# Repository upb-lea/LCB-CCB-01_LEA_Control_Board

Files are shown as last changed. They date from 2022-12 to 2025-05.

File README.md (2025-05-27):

# LEA Control Board

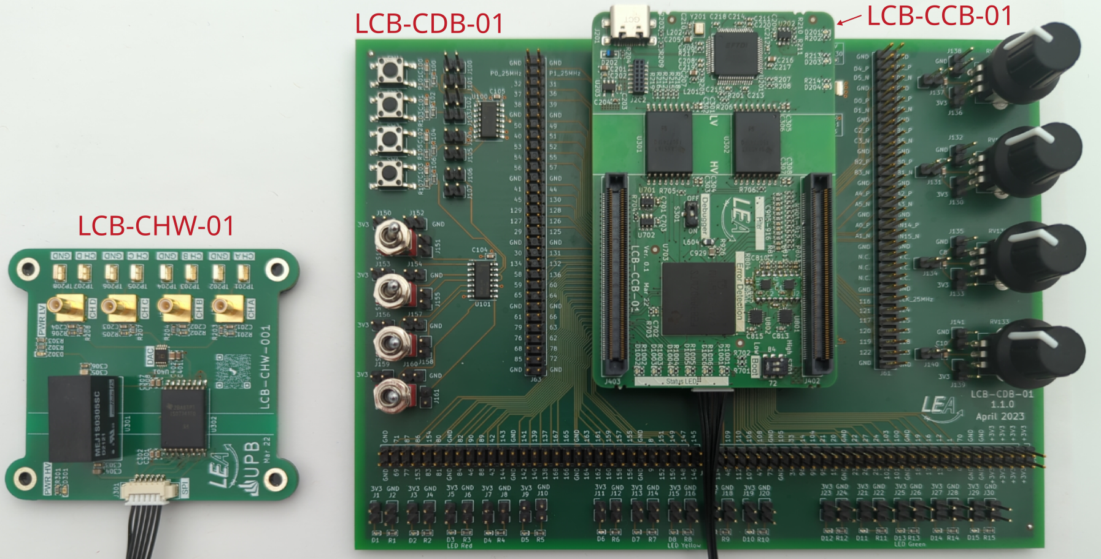
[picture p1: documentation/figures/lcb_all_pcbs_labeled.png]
    

The LEA Control Board (LCB) is a construction kit to provide power electronic converters with a control board.

The basic module is the control board (LCB-CCB) itself. It contains a powerful dual-core processor, error latches and various predefined low-pass filters to respond to input signals. An XDS100v2 debugger is directly integrated on the board. 

The docking board (LCB-CDB) is suitable for initial operation. This contains various input options (switches, buttons, potentiometers) as well as LEDs for output.

The external hardware monitor (LCB-CHW) is for viewing internal counter variables on the oscilloscope and is mainly used for troubleshooting the control board in the overall system (control board + power converter).

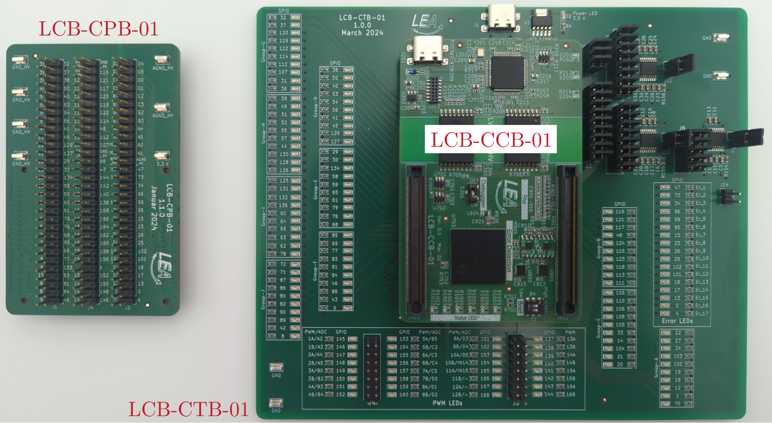
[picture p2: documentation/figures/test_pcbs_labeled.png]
    

The pin board (LCB-CPB) is for in-circuit signal measurments by an external scope on certain pins.
The test board (LCB-CTB) was developed to check all pins, PWM signals, ADCs and DACs for functionality after a new board has been completed (end of line test).

## PCB overview
This is the main repository of the LEA Control Board (LCB) project. Due to correct PCB versioning, every single PCB is in its own repository.
 * [LCB-CDB-01_Dock_Board](https://github.com/upb-lea/LCB-CDB-01_Dock_Board)
 * [LCB-CHW-01_Hardware_Monitor](https://github.com/upb-lea/LCB-CHW-01_Hardware_Monitor)
 * [LCB-CPB-01_Pin_Board](https://github.com/upb-lea/LCB-CPB-01_Pin_Board)
 * [LCB-CTB-01_Test_Board](https://github.com/upb-lea/LCB-CTB-01_Test_Board)
 * [LCB-CBB-01_Bus_Board](https://github.com/upb-lea/LCB-CBB-01_Bus_Board)

Symbols, footprints and 3D-models can be found in the [LEA KiCad Library](https://github.com/upb-lea/LEA_KiCad_Library).

## PCB versioning
Example `LCB-CCB-01-1.0.5`:
 * First three letters `LCB`: Parent project name `LEA Control Board`
 * Second three letters `CCB`: PCB name `Control Board`
 * Number `01`: PCB size. For future use in case of several PCB sizes
 * First version number `1`: Major version, increases for incompatible changes
 * Second number `0`: PCB release, increases for improved layouts
 * Third number `5`: Schematic version, increases for component changes, but no layout changes

## Kicad Options
To open the LEA Control Board files, [KiCad 9](https://www.kicad.org/) needs to be used. Make sure that you run the latest version of KiCad.

### Downloading this project and folder structure
To use this project, LEA KiCad symbols, footprints and 3D-models need to be included. Note, that both folders need to be in the same direction.

Clone the symbols, footprints and 3D-models:
```
git clone https://github.com/upb-lea/LEA_KiCad_Library.git
```

Clone this project:
```
https://github.com/upb-lea/LCB-CCB-01_LEA_Control_Board.git
```
If you are downloading the `.zip`-files manually, unpack them in the same direction.

### Symbol library and footprint libary
The libraries are included by default, if the above mentioned folder structure was considered. Open Kicad, load one of the projects and see the libraries:
 * `symbol editor` -> Search for `LEA_Symbol_Library`
 * `footprint editor` -> Search for `LEA_Footprint_Library`

### Set environment variable for 3D models:
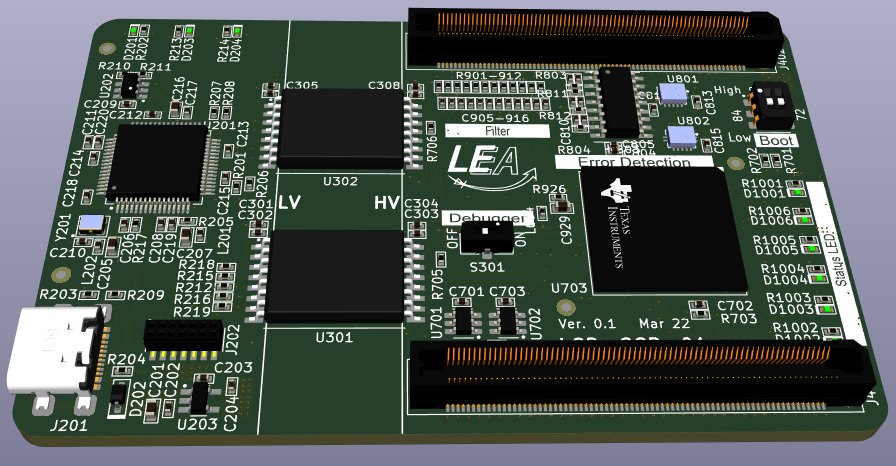
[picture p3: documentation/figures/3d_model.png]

Please refer to [this section](https://github.com/upb-lea/LEA_KiCad_Library#set-environment-variable-for-3d-models).

## Software
Various software examples using the LEA Control Board is available and can be found [in this repository](https://github.com/upb-lea/LCB-Software). There are examples for using the hardware monitor, SPI, UART and many others.

## How to design the LCB into your cirucit?
 * A stable external 3.3 V power supply must be provided, recommended by a linear regulator.
 * It is recommended to use buffer-ICs for the LCB GPIOs to prevent damage on the LCB board.

## Design decisions 
 * To not confuse the user, there is only one supply voltage needed. All pins of the board are save for 3.3 V. Some components can be used with higher voltage, but this would lead to confusion and may damage the board due to misunderstandings.
 * A stable external 3.3 V power supply must be provided, recommended by a linear regulator. We did not decide for an internal regulator, as this regulator does not know your external load, and might be overloaded.

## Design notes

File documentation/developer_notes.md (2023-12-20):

# Developer notes

## create BOM

Create XML-file from kicad schematic
```
kicad-cli sch export python-bom LCB-CPB-01_Pin_Board.kicad_sch 
```

create BOM using kicost
```
pip install kicost
```
Run kicost
`kicost`

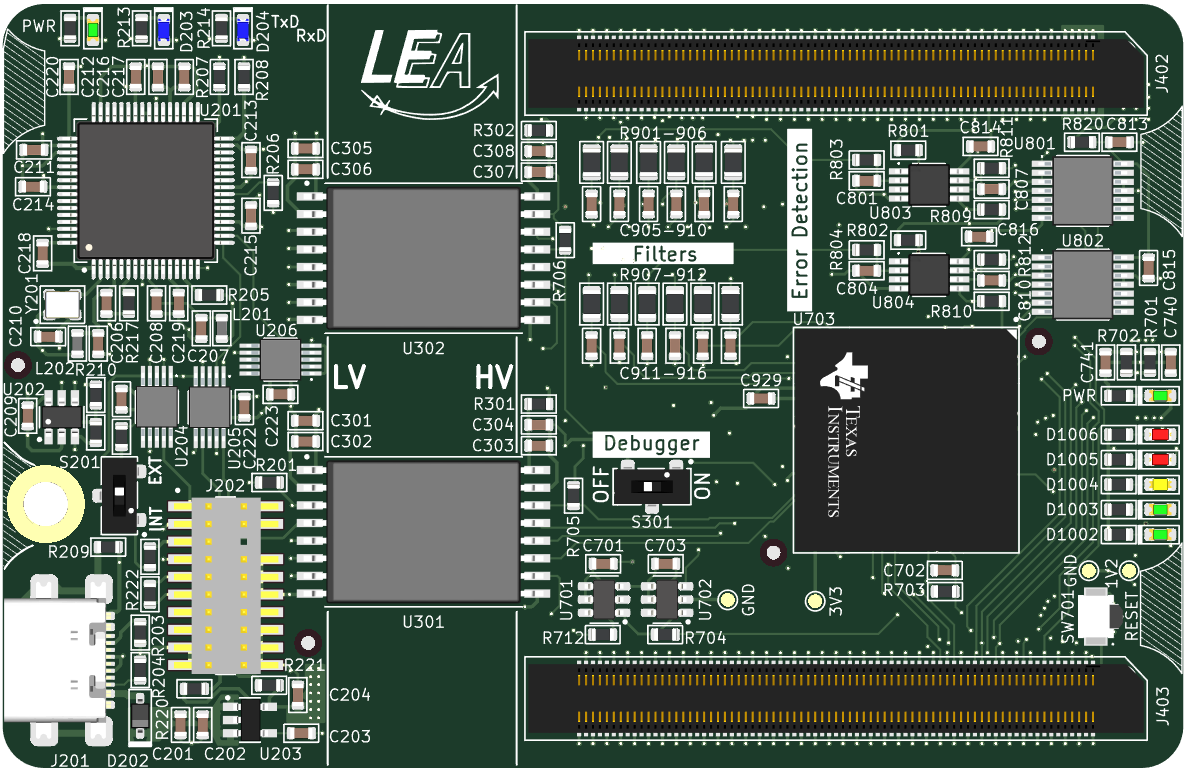
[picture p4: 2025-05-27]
LCB-CCB-01/TopSide.png

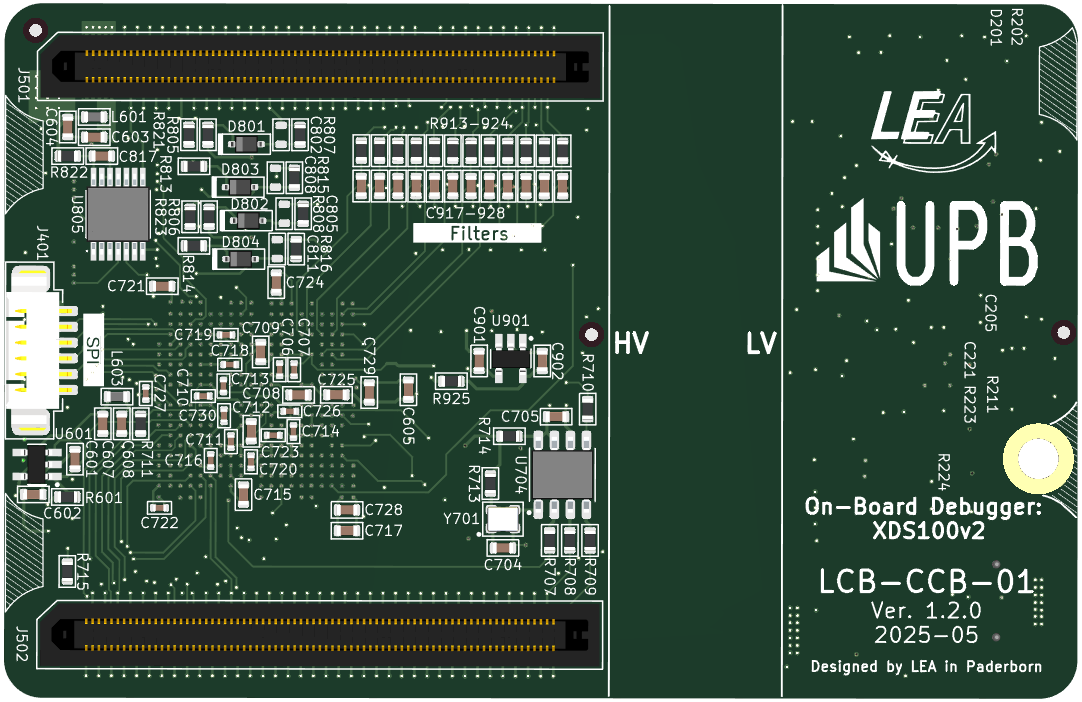
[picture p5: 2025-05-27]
LCB-CCB-01/BottomSide.png

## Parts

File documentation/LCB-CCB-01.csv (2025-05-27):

Source: | /home/nikolasf/Dokumente/01_git/70_PCBs/LCB-CCB-01_LEA_Control_Board/LCB-CCB-01/LCB-CCB-01.kicad_sch
Date: | 2025-05-27T11:14:56+0200
Tool: | Eeschema 9.0.2
Generator: | /usr/share/kicad/plugins/bom_csv_grouped_by_value.py
Component Count: | 248
Collated Components:
Item | Qty | Reference(s) | Value | LibPart | Footprint | Datasheet | DNP | Datasheet | Description | Footprint | Manufacturer | Sim.Enable | manf# | mouser#
1 | 1 | ACCESSORY901 | ACCESSORY_USB_C_cable | LEA_SymbolLibrary:ACCESSORY_USB_C_cable |  | https://www.mouser.de/datasheet/2/813/ACCA-2532_Model__1_-1621233.pdf |  | https://www.mouser.de/datasheet/2/813/ACCA-2532_Model__1_-1621233.pdf |  |  | SparkFun |  | CAB-15424 | 474-CAB-15424
2 | 4 | C201, C205, C207, C216 | 4u7 | LEA_SymbolLibrary:C_0603__4u7_X5R_10P__35V | LEA_FootprintLibrary:C_0603 |  |  |  | Capacitor 0603 | LEA_FootprintLibrary:C_0603 | TDK |  | C1608X5R1V475K | 810-C1608X5R1V475K
3 | 3 | C202, C203, C702 | 10n | LEA_SymbolLibrary:C_0603__10n_X7R_10P__50V | LEA_FootprintLibrary:C_0603 |  |  |  | Capacitor 0603 | LEA_FootprintLibrary:C_0603 | TDK |  | CGA3E2X7R1H103K | 810-CGA3E2X7R1H103K
4 | 5 | C204, C601, C602, C740, C741 | 1u0 | LEA_SymbolLibrary:C_0603__1u0_X5R_10P__50V | LEA_FootprintLibrary:C_0603 |  |  |  | Capacitor 0603 | LEA_FootprintLibrary:C_0603 | TDK |  | C1608X5R1H105K | 810-C1608X5R1H105K
5 | 41 | C206, C208, C209, C210, C211, C212, C213, C214, C215, C217, C218, C219, C220, C221, C222, C223, C302, C303, C306, C307, C701, C703, C704, C705, C708, C709, C712, C715, C717, C721, C724, C725, C728, C729, C813, C814, C815, C816, C817, C901, C902 | 100n | LEA_SymbolLibrary:C_0603_100n_X5R_10P__50V | LEA_FootprintLibrary:C_0603 |  |  |  | Capacitor 0603 | LEA_FootprintLibrary:C_0603 | TDK |  | C1608X5R1H104K | 810-C1608X5R1H104K
6 | 9 | C301, C304, C305, C308, C603, C604, C605, C607, C608 | 2u2 | LEA_SymbolLibrary:C_0603__2u2_X5R_10P__35V | LEA_FootprintLibrary:C_0603 |  |  |  | Capacitor 0603 | LEA_FootprintLibrary:C_0603 | TDK |  | C1608X5R1V225K | 810-C1608X5R1V225K
7 | 15 | C706, C707, C710, C711, C713, C714, C716, C718, C719, C720, C722, C723, C726, C727, C730 | 100n | LEA_SymbolLibrary:C_0402_100n_X7R_10P__50V | LEA_FootprintLibrary:C_0402 |  |  |  | Capacitor 0402 | LEA_FootprintLibrary:C_0402 | TDK |  | C1005X7R1H104K | 810-C1005X7R1H104K
8 | 16 | C801, C804, C807, C810, C905, C906, C909, C910, C913, C914, C917, C918, C921, C922, C925, C926 | 100p | LEA_SymbolLibrary:C_0603_100p_C0G_10P__50V | LEA_FootprintLibrary:C_0603 |  |  |  | Capacitor 0603 | LEA_FootprintLibrary:C_0603 | TDK |  | C1608C0G1H101KAA | 810-C1608C0G1H101KAA
9 | 4 | C802, C805, C808, C811 | 10n | LEA_SymbolLibrary:C_0603__10n_X7R_10P__50V | LEA_FootprintLibrary:C_0603 |  | DNP |  | Capacitor 0603 | LEA_FootprintLibrary:C_0603 | TDK |  | CGA3E2X7R1H103K | 810-CGA3E2X7R1H103K
10 | 12 | C907, C908, C911, C912, C915, C916, C919, C920, C923, C924, C927, C928 | 1n0 | LEA_SymbolLibrary:C_0603__1n0_X7R_10P__50V | LEA_FootprintLibrary:C_0603 |  |  |  | Capacitor 0603 | LEA_FootprintLibrary:C_0603 | TDK |  | C1608X7R1H102KAE | 810-C1608X7R1H102KAE
11 | 1 | C929 | 22u | LEA_SymbolLibrary:C_0603__22u_X5R_10P_6V3 | LEA_FootprintLibrary:C_0603 |  |  |  | Capacitor 0603 | LEA_FootprintLibrary:C_0603 | Samsung |  | CL10A226KQ8NRNE | 187-CL10A226KQ8NRNE
12 | 4 | D201, D1001, D1002, D1003 | 2mA | LEA_SymbolLibrary:LED_0603_G_2mA_APTD1608LCGCK | LEA_FootprintLibrary:LED_0603_G | https://www.mouser.de/datasheet/2/216/APTD1608LCGCK-1102124.pdf |  | https://www.mouser.de/datasheet/2/216/APTD1608LCGCK-1102124.pdf | LED 0603, Green, If 2mA, Vf 1.9V | LEA_FootprintLibrary:LED_0603_G | Kingbright |  | APTD1608LCGCK | 604-APTD1608LCGCK
13 | 1 | D202 | 1A0 | LEA_SymbolLibrary:D_SOD_1A0_BAS3010A03WE6327HTSA1 | LEA_FootprintLibrary:SOD-323_Infineon | https://www.mouser.de/datasheet/2/196/Infineon-BAS3010ASERIES-DS-v01_01-en-1226012.pdf |  | https://www.mouser.de/datasheet/2/196/Infineon-BAS3010ASERIES-DS-v01_01-en-1226012.pdf | Schottky Diodes & Rectifiers Medium Power IF Diode | LEA_FootprintLibrary:SOD-323_Infineon | Infineon |  | BAS3010A03WE6327HTSA1 | 726-BAS3010A-03WE6
14 | 2 | D203, D204 | 2mA | LEA_SymbolLibrary:LED_0603_B_2mA_APHD1608LVBC/D | LEA_FootprintLibrary:LED_0603_B | https://eu.mouser.com/datasheet/2/216/APHD1608LVBC-D-1100823.pdf |  | https://eu.mouser.com/datasheet/2/216/APHD1608LVBC-D-1100823.pdf | LED 0603, Blue, If 2mA, Vf 2.65V | LEA_FootprintLibrary:LED_0603_B | Kingbright |  | APHD1608LVBC/D | 604-APHD1608LVBCD
15 | 4 | D801, D802, D803, D804 | 150mA | LEA_SymbolLibrary:D_SOD_150mA_BAS316_R1_00001 | LEA_FootprintLibrary:SOD-323_Panjit | https://www.mouser.de/datasheet/2/1057/BAS316-1876387.pdf |  | https://www.mouser.de/datasheet/2/1057/BAS316-1876387.pdf | Diodes - General Purpose, Power, Switching SURFACE MOUNT SWITCHING DIODE | LEA_FootprintLibrary:SOD-323_Panjit | Panjit |  | BAS316_R1_00001 | 241-BAS316_R1_00001
16 | 1 | D1004 | 2mA | LEA_SymbolLibrary:LED_0603_Y_2mA_APTD1608LSYCK | LEA_FootprintLibrary:LED_0603_Y | https://eu.mouser.com/datasheet/2/216/APHD1608LSURCK-1100899.pdf |  | https://eu.mouser.com/datasheet/2/216/APHD1608LSURCK-1100899.pdf | LED 0603, Yellow, If 2mA, Vf 1.85V | LEA_FootprintLibrary:LED_0603_Y | Kingbright |  | APTD1608LSYCK | 604-APTD1608LSYCK
17 | 2 | D1005, D1006 | 2mA | LEA_SymbolLibrary:LED_0603_R_2mA_APHD1608LSURCK | LEA_FootprintLibrary:LED_0603_R | https://eu.mouser.com/datasheet/2/216/APHD1608LSURCK-1100899.pdf |  | https://eu.mouser.com/datasheet/2/216/APHD1608LSURCK-1100899.pdf | LED 0603, Red, If 2mA, Vf 1.75V | LEA_FootprintLibrary:LED_0603_R | Kingbright |  | APHD1608LSURCK | 604-APHD1608LSURCK
18 | 1 | J201 | USBC_GTC_USB4110-GF-A | LEA_SymbolLibrary:Conn_USBC_GTC_USB4110-GF-A | LEA_FootprintLibrary:USB_C_GCT_USB4110-GF-A | https://www.mouser.de/datasheet/2/837/USB4110-2888203.pdf |  | https://www.mouser.de/datasheet/2/837/USB4110-2888203.pdf | USB Connectors USB Type C, 2.0, Rec, SMT , G/F, RA , Top Mnt, T & R | LEA_FootprintLibrary:USB_C_GCT_USB4110-GF-A | GTC |  | USB4110-GF-A | 640-USB4110-GF-A
19 | 1 | J202 | FTR-110-03-G-D-06-TR | LEA_SymbolLibrary:Conn_02x10_Male_JTAG | LEA_FootprintLibrary:FTR-110-03-G-D-06 | https://kinetictest.samtec.com/partnumber/ftr-110-03-g-d-06-tr |  | https://kinetictest.samtec.com/partnumber/ftr-110-03-g-d-06-tr | 20 pin SMD Micro Header, 1.27 mm pitch | LEA_FootprintLibrary:FTR-110-03-G-D-06 | Samtec |  | FTR-110-03-G-D-06-TR | 200-FTR11003GD06TR
20 | 1 | J401 | Molex_532617006 | LEA_SymbolLibrary:Conn_Molex_532617006 | LEA_FootprintLibrary:6-PinHeader_Molex_532617006 | https://www.molex.com/pdm_docs/sd/532617006_sd.pdf |  | https://www.molex.com/pdm_docs/sd/532617006_sd.pdf | 6 Pin Male, right angle, 1.25mm Pitch | LEA_FootprintLibrary:6-PinHeader_Molex_532617006 | Molex |  | 53261-7006 | 538-53261-7006
21 | 2 | J402, J403 | ERF5-075-05.0-L-DV-TR | LEA_SymbolLibrary:Conn_ERF5-075-05.0-L-DV-TR | LEA_FootprintLibrary:ERF5-075-05.0-L-DV | https://suddendocs.samtec.com/prints/erf5-xxx-xx.x-dv-xx-tr-footprint.pdf |  | https://suddendocs.samtec.com/prints/erf5-xxx-xx.x-dv-xx-tr-footprint.pdf | Board to Board & Mezzanine Connectors 0.50 mm Edge Rate Rugged High Speed Socket | LEA_FootprintLibrary:ERF5-075-05.0-L-DV | Samtec |  | ERF5-075-05.0-L-DV-TR | 200-ERF507505.0LDVTR
22 | 2 | J501, J502 | ERM5-075-05.0-L-DV-K-TR | LEA_SymbolLibrary:Conn_ERM5-075-05.0-L-DV-K-TR | LEA_FootprintLibrary:ERM5-075-05.0-L-DV | https://suddendocs.samtec.com/prints/erm5-xxx-xx.x-dv-xx-tr-footprint.pdf |  | https://suddendocs.samtec.com/prints/erm5-xxx-xx.x-dv-xx-tr-footprint.pdf | Board to Board & Mezzanine Connectors 0.50 mm Edge Rate Rugged High Speed Terminal | LEA_FootprintLibrary:ERM5-075-05.0-L-DV | Samtec | 0 | ERM5-075-05.0-L-DV-K-TR | 200-ERM5075050LDVKTR
23 | 2 | L201, L202 | Ferrite_0603 | LEA_SymbolLibrary:Ferrite_0603_600R_300mA | LEA_FootprintLibrary:L_0603 | https://www.mouser.de/datasheet/2/643/ds_ST_FCB_0603_series-3420259.pdf |  | https://www.mouser.de/datasheet/2/643/ds_ST_FCB_0603_series-3420259.pdf | Ferrite Bead, 0603, 600Ohm, 300mA | LEA_FootprintLibrary:L_0603 | Murata |  | FCB-0603-601A | 530-FCB-0603-601A
24 | 2 | L601, L603 | 60R/3A5 | LEA_SymbolLibrary:Ferrite_0603_60R_3A5 | LEA_FootprintLibrary:L_0603 | https://product.tdk.com/system/files/dam/doc/product/emc/emc/beads/catalog/beads_commercial_power_mpz1608_en.pdf |  | https://product.tdk.com/system/files/dam/doc/product/emc/emc/beads/catalog/beads_commercial_power_mpz1608_en.pdf | Ferrite Bead, 0603 | LEA_FootprintLibrary:L_0603 | TDK |  | MPZ1608S600ATAH0 | 810-MPZ1608S600ATAH0
25 | 11 | R201, R205, R207, R208, R211, R223, R701, R702, R703, R705, R706 | 2k2 | LEA_SymbolLibrary:R_0603__2k2_THICK__1P__75V | LEA_FootprintLibrary:R_0603 |  |  |  | Resistor 0603 | LEA_FootprintLibrary:R_0603 | Vishay |  | CRCW06032K20FKEAC | 71-CRCW06032K20FKEAC
26 | 9 | R202, R213, R214, R1001, R1002, R1003, R1004, R1005, R1006 | 680R | LEA_SymbolLibrary:R_0603_680R_THICK__1P__75V | LEA_FootprintLibrary:R_0603 |  |  |  | Resistor 0603 | LEA_FootprintLibrary:R_0603 | Vishay |  | CRCW0603680RFKEAC | 71-CRCW0603680RFKEAC
27 | 9 | R203, R204, R220, R221, R224, R805, R806, R813, R814 | 4k7 | LEA_SymbolLibrary:R_0603__4k7_THICK__1P__75V | LEA_FootprintLibrary:R_0603 |  |  |  | Resistor 0603 | LEA_FootprintLibrary:R_0603 | Vishay |  | CRCW06034K70FKEBC | 71-CRCW06034K70FKEBC
28 | 15 | R206, R209, R222, R301, R302, R601, R704, R712, R713, R714, R820, R821, R822, R823, R925 | 0R0 | LEA_SymbolLibrary:R_0603__0R0_THICK__1P__75V | LEA_FootprintLibrary:R_0603 |  |  |  | Resistor 0603 | LEA_FootprintLibrary:R_0603 | Vishay |  | CRCW06030000Z0EAC | 71-CRCW06030000Z0EAC
29 | 5 | R210, R807, R808, R815, R816 | 10k | LEA_SymbolLibrary:R_0603__10k_THICK__1P__75V | LEA_FootprintLibrary:R_0603 |  |  |  | Resistor 0603 | LEA_FootprintLibrary:R_0603 | Vishay |  | CRCW060310K0FKEAC | 71-CRCW060310K0FKEAC
30 | 1 | R217 | 12k | LEA_SymbolLibrary:R_0603__12k_THICK__1P__75V | LEA_FootprintLibrary:R_0603 |  |  |  | Resistor 0603 | LEA_FootprintLibrary:R_0603 | Vishay |  | CRCW060312K0FKEAC | 71-CRCW060312K0FKEAC
31 | 4 | R707, R708, R709, R710 | 33R | LEA_SymbolLibrary:R_0603__33R_THICK__1P__75V | LEA_FootprintLibrary:R_0603 |  |  |  | Resistor 0603 | LEA_FootprintLibrary:R_0603 | Vishay |  | CRCW060333R0FKEAC | 71-CRCW060333R0FKEAC
32 | 1 | R711 | 56R | LEA_SymbolLibrary:R_0603__56R_THICK__1P__75V | LEA_FootprintLibrary:R_0603 |  |  |  | Resistor 0603 | LEA_FootprintLibrary:R_0603 | Vishay |  | CRCW060356R0FKEAC | 71-CRCW060356R0FKEAC
33 | 1 | R715 | 10R | LEA_SymbolLibrary:R_0603__10R_THICK__1P__75V | LEA_FootprintLibrary:R_0603 |  |  |  | Resistor 0603 | LEA_FootprintLibrary:R_0603 | Vishay |  | CRCW060310R0FKEAC | 71-CRCW060310R0FKEAC
34 | 20 | R801, R802, R803, R804, R809, R810, R811, R812, R913, R914, R915, R916, R917, R918, R919, R920, R921, R922, R923, R924 | 1k0 | LEA_SymbolLibrary:R_0603__1k0_THICK__1P__75V | LEA_FootprintLibrary:R_0603 |  |  |  | Resistor 0603 | LEA_FootprintLibrary:R_0603 | Vishay |  | CRCW06031K00FKEAC | 71-CRCW06031K00FKEAC
35 | 12 | R901, R902, R903, R904, R905, R906, R907, R908, R909, R910, R911, R912 | 1k0 | LEA_SymbolLibrary:R_0805__1k0_THICK__1P_150V | LEA_FootprintLibrary:R_0805 |  |  |  | Resistor 0805 | LEA_FootprintLibrary:R_0805 | Vishay |  | CRCW08051K00FKEAC | 71-CRCW08051K00FKEAC
36 | 2 | S201, S301 | CAS-120TA | LEA_SymbolLibrary:CAS-120TA | LEA_FootprintLibrary:CAS-120TA | https://www.mouser.de/datasheet/2/972/cas-1628136.pdf |  | https://www.mouser.de/datasheet/2/972/cas-1628136.pdf | Slide Switches SPDT, ON-ON, slide, J-hook SMD terminals, 100mA @ 6V DC | LEA_FootprintLibrary:CAS-120TA | Nidec |  | CAS-120TA | 229-CAS-120TA
37 | 1 | SW701 | SW_Push_RightAngle | LEA_SymbolLibrary:SW_Push_RightAngle | LEA_FootprintLibrary:Sw_Push_RightAngle | https://www.mouser.de/datasheet/2/307/en_b3u-3476507.pdf |  | https://www.mouser.de/datasheet/2/307/en_b3u-3476507.pdf | Push button switch, right angle, generic, two pins | LEA_FootprintLibrary:Sw_Push_RightAngle | Omron Electronics |  | B3U-3000PM | 653-B3U-3000PM
38 | 1 | U201 | FT2232HL | LEA_SymbolLibrary:FT2232HL | LEA_FootprintLibrary:LQFP-64_12x12_Pitch0.5mm_FTDI | https://ftdichip.com/wp-content/uploads/2020/07/DS_FT2232H.pdf |  | https://ftdichip.com/wp-content/uploads/2020/07/DS_FT2232H.pdf | USB Interface IC USB HS to Dual UART/ FIFO/SPI/JTAG/I2C | LEA_FootprintLibrary:LQFP-64_12x12_Pitch0.5mm_FTDI | FTDI |  | FT2232HL-TRAY | 895-FT2232HL-TRAY
39 | 1 | U202 | 93LC56BT-I_OT | LEA_SymbolLibrary:EEPROM_93LC56BT-I_OT | LEA_FootprintLibrary:SOT-23-6_Microchip | http://ww1.microchip.com/downloads/en/devicedoc/21794f.pdf |  | http://ww1.microchip.com/downloads/en/devicedoc/21794f.pdf | EEPROM Serial-Microwire 2K-Bit 128 x 16 2MHz,93LC56BT-I/OT,SOT-23-6,SMD | LEA_FootprintLibrary:SOT-23-6_Microchip | Microchip |  | 93LC56BT-I/OT | 579-93LC56BT-I/OT
40 | 1 | U203 | MIC5259-3.3YD5-TR | LEA_SymbolLibrary:MIC5259-3.3YD5-TR | LEA_FootprintLibrary:SOT-23-5_Microchip | https://ww1.microchip.com/downloads/en/DeviceDoc/mic5259.pdf |  | https://ww1.microchip.com/downloads/en/DeviceDoc/mic5259.pdf | LDO Voltage Regulator 3.3V 300mA | LEA_FootprintLibrary:SOT-23-5_Microchip | Microchip | 0 | MIC5259-3.3YD5-TR | 998-MIC5259-3.3YD5TR
41 | 3 | U204, U205, U206 | ADG736BRMZ | LEA_SymbolLibrary:ADG736BRMZ | LEA_FootprintLibrary:MSOP10_AnalogDevices | http://www.analog.com/media/en/technical-documentation/data-sheets/ADG736.pdf |  | http://www.analog.com/media/en/technical-documentation/data-sheets/ADG736.pdf | Analog Devices ADG736BRMZ, Analogue SPDT Switch Dual SPDT, 3 V, 5 V, 10-Pin MSOP | LEA_FootprintLibrary:MSOP10_AnalogDevices | Analog Devices |  | ADG736BRMZ | 584-ADG736BRMZ
42 | 2 | U301, U302 | ISO_ISO7741FQDWWQ1 | LEA_SymbolLibrary:ISO_ISO7741FQDWWQ1 | LEA_FootprintLibrary:SOIC-16_TI_DWW0016A_Optimized | https://www.ti.com/lit/ds/symlink/iso7741-q1.pdf?ts=1637972753620 |  | https://www.ti.com/lit/ds/symlink/iso7741-q1.pdf?ts=1637972753620 | ISO774x-Q1 Automotive, High-Speed, Reinforced Quad-Channel Digital Isolators | LEA_FootprintLibrary:SOIC-16_TI_DWW0016A_Optimized | Texas Instruments |  | ISO7741FQDWWQ1 | 595-ISO7741FQDWWQ1
43 | 1 | U601 | MIC5504-1.2YM5-TR | LEA_SymbolLibrary:MIC5504-1.2YM5-TR | LEA_FootprintLibrary:SOT-23-5_Microchip | https://www.mouser.de/datasheet/2/268/MIC5501_02_03_04_300mA_Single_Output_LDO_in_Small_-3442643.pdf |  | https://www.mouser.de/datasheet/2/268/MIC5501_02_03_04_300mA_Single_Output_LDO_in_Small_-3442643.pdf | LDO Voltage Regulator 1.2V 300mA | LEA_FootprintLibrary:SOT-23-5_Microchip | Microchip |  | MIC5504-1.2YM5-TR | 998-MIC5504-1.2YM5TR
44 | 1 | U701 | TPS3702CX33DDCT | LEA_SymbolLibrary:TPS3702CX33DDCT | LEA_FootprintLibrary:TSOT-23-6_TI | https://www.ti.com/lit/ds/symlink/tps3702.pdf?HQS=dis-mous-null-mousermode-dsf-pf-null-wwe&ts=1642032019663 |  | https://www.ti.com/lit/ds/symlink/tps3702.pdf?HQS=dis-mous-null-mousermode-dsf-pf-null-wwe&ts=1642032019663 | Supervisory Circuits High-Acc, Fixed Threshold OV/UV Mntr | LEA_FootprintLibrary:TSOT-23-6_TI | Texas Instruments |  | TPS3702CX33DDCT | 595-TPS3702CX33DDCT
45 | 1 | U702 | TPS3702CX12DDCT | LEA_SymbolLibrary:TPS3702CX12DDCT | LEA_FootprintLibrary:TSOT-23-6_TI | https://www.ti.com/lit/ds/symlink/tps3702.pdf?HQS=dis-mous-null-mousermode-dsf-pf-null-wwe&ts=1642032019663 |  | https://www.ti.com/lit/ds/symlink/tps3702.pdf?HQS=dis-mous-null-mousermode-dsf-pf-null-wwe&ts=1642032019663 | Supervisory Circuits High-Acc, Fixed Threshold OV/UV Mntr | LEA_FootprintLibrary:TSOT-23-6_TI | Texas Instruments |  | TPS3702CX12DDCT | 595-TPS3702CX12DDCT
46 | 1 | U703 | TMS320F28388D | LEA_SymbolLibrary:TMS320F2838xDZWT | LEA_FootprintLibrary:BGA-361_19x19_16.0x16.0mm | https://www.ti.com/lit/ds/symlink/tms320f28388d.pdf?ts=1737445638002 |  | https://www.ti.com/lit/ds/symlink/tms320f28388d.pdf?ts=1737445638002 | MCU C2000 32-bit, Dual-core C28x architecture | LEA_FootprintLibrary:BGA-361_19x19_16.0x16.0mm | Texas Instruments |  | F28388DZWTSR | 595-F28388DZWTSR
47 | 1 | U704 | PI6C49CB04AQ3WEX | LEA_SymbolLibrary:PI6C49CB04AQ3WEX | LEA_FootprintLibrary:SOIC-8 | https://www.mouser.de/datasheet/2/115/DIOD_S_A0009189232_1-2543411.pdf |  | https://www.mouser.de/datasheet/2/115/DIOD_S_A0009189232_1-2543411.pdf | Clock Buffer LOW SKEW 1 TO 4 CLOCK BUFFER | LEA_FootprintLibrary:SOIC-8 | Diodes Incorporated |  | PI6C49CB04AQ3WEX | 621-PI6C49CB04AQ3WEX
48 | 2 | U801, U802 | 74HC74PW | LEA_SymbolLibrary:74HC74PW | LEA_FootprintLibrary:TSSOP-14-Nexperia | https://assets.nexperia.com/documents/data-sheet/74HC_HCT74.pdf |  | https://assets.nexperia.com/documents/data-sheet/74HC_HCT74.pdf | Flip-Flops 74HC74PW/SOT402/TSSOP14 | LEA_FootprintLibrary:TSSOP-14-Nexperia | Nexperia |  | 74HC74PW,118 | 771-74HC74PW-T
49 | 2 | U803, U804 | TLV3202AIDGKR | LEA_SymbolLibrary:OP_2_TLV3202AIDGKR_VSSOP-8 | LEA_FootprintLibrary:VSSOP-8-TI | https://www.ti.com/lit/ds/symlink/tlv3202.pdf?ts=1737103769904 |  | https://www.ti.com/lit/ds/symlink/tlv3202.pdf?ts=1737103769904 |  | LEA_FootprintLibrary:VSSOP-8-TI | Texas Instruments |  | TLV3202AIDGKR | 595-TLV3202AIDGKR
50 | 1 | U805 | 74ALVC08PW | LEA_SymbolLibrary:AND_Gate_74ALVC08PW | LEA_FootprintLibrary:TSSOP-14-Nexperia | https://assets.nexperia.com/documents/data-sheet/74ALVC08.pdf |  | https://assets.nexperia.com/documents/data-sheet/74ALVC08.pdf | 4 gate, 8 input, 4 Output, AND gate, Logic Gates 74ALVC08PW/TSSOP14 | LEA_FootprintLibrary:TSSOP-14-Nexperia | Nexperia |  | 74ALVC08PW,118 | 771-ALVC08PW118
51 | 1 | U901 | MAX6037AAUK30+T | LEA_SymbolLibrary:MAX6037AAUK30+T | LEA_FootprintLibrary:SOT-23-5_Microchip | https://datasheets.maximintegrated.com/en/ds/MAX6037-MAX6037C.pdf |  | https://datasheets.maximintegrated.com/en/ds/MAX6037-MAX6037C.pdf | Precision Voltage Reference 3.0V | LEA_FootprintLibrary:SOT-23-5_Microchip | Maxim Integrated |  | MAX6037AAUK30+T | 700-MAX6037AAUK30T
52 | 1 | Y201 | ECS-2033-120-AU | LEA_SymbolLibrary:ECS-2033-120-AU | LEA_FootprintLibrary:Osc_ECS_2.5x2 | https://www.mouser.de/datasheet/2/122/ecs_2025_2033-18511.pdf |  | https://www.mouser.de/datasheet/2/122/ecs_2025_2033-18511.pdf | Standard Clock Oscillators 12.000 MHZ 3.3Volt 100 ppm -55C +125C | LEA_FootprintLibrary:Osc_ECS_2.5x2 | ECS |  | ECS-2033-120-AU | 520-2033-120-AU
53 | 1 | Y701 | ECS-2520S33-250-FN-TR | LEA_SymbolLibrary:ECS-2520S33-250-FN-TR | LEA_FootprintLibrary:Osc_ECS_2.5x2 | https://www.mouser.de/datasheet/2/122/ECS_2520S-1064133.pdf |  | https://www.mouser.de/datasheet/2/122/ECS_2520S-1064133.pdf | Standard Clock Oscillators 25MHz 3.3V 10ppm -40C +85C | LEA_FootprintLibrary:Osc_ECS_2.5x2 | ECS |  | ECS-2520S33-250-FN-TR | 520-2520S33-250-FNT

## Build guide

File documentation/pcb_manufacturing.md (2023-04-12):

# Manufacturing and soldering the LCB
## Manufacturing the LCB
 * Minimum PCB thickness is 2.3 mm due to the position-pin overlapping of J501/402 and J502/J403.
 * For automated placement, the position pin holes of the connectors J501/402/J502/J403 should be milled with a depth of minimum 1.3 mm. 
 
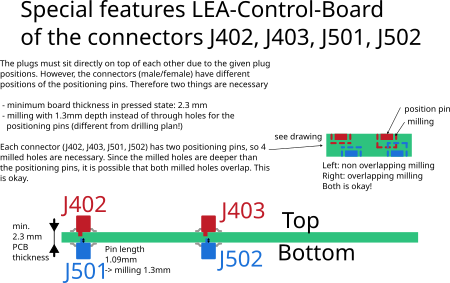
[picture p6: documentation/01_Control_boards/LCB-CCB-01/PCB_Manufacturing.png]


## MCU BGA soldering process
 * Remove all solder from MCU pad (smooth and flat surface).
 * Clean with PCB cleaner and remove all dust residues.
 * Apply a very thin layer of Flux on MCU pad.
 * Use the Rework station for the soldering the MCU chip.
 
## Initial flashing the XDS100 debugger
Please refer to [this tutorial](https://github.com/upb-lea/LCB-Software#flash-xds100-firmware-to-ftdi-chip).

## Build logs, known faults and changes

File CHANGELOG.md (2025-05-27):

# Changelog
All notable changes to this project will be documented in this file.

The format is based on [Keep a Changelog](https://keepachangelog.com/en/1.0.0/),
and this project adheres to [Semantic Versioning](https://semver.org/spec/v2.0.0.html).

## [1.2.0] - 2025-05-27
### Changed
 * USB connector and some components close to the keep-out-areas have moved a bit
 * Rotated 3D-model of processor

## [1.1.0] - 2025-02-21
### Changed
 * Update component names to more readable format
 * Update many 0402 components to 0603 components
 * Updated, more stable external debugger connector
 * Updated housings for error latch, easier to solder

### Added
 * Markings for the holders in the rework-station
 * Hole on debugger side to add custom plastic spacer to prevent board detaching from main pcb by mistake
 * Test points for 3.3 V, 1.2 V and GND
 * Reset button
 * 0 Ohm resistors for some electronics groups
 * Low active AND gate output to summarize the error latch signals

### Fixed
 * Fixed ADA01 workaround due to wrong comparator
 * ADC filters fixed from series connection to parallel connection
 * BOM for microcontroller
 
### Removed
 * Boot switch
 * Impedance buffer U902. Also works without this buffer IC.
 * R926 (not needed).

## [1.0.0] - 2023-04-09
### Added
 * LCB-CCB-01 Control Board initial release

[1.1.0]: https://github.com/upb-lea/LCB-CCB-01_LEA_Control_Board/compare/1.0.0...1.1.0
[1.0.0]: https://github.com/upb-lea/LCB-CCB-01_LEA_Control_Board/compare/1.0.0...1.0.0

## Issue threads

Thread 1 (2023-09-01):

The base module (LCB-CCB) accidentally detaches from the docking board (LCB-CDB)

meisernitz, 2023-09-01:
The base module (LCB-CCB) sometimes detaches from the docking board (LCB-CDB) unintentionally
For example when touching the usb cables.

A possible solution would be to add two plastic spacers near the iso couplers.
There are no components at this point.

VijayThera, 2025-01-06:
added M3 hole for a spacer

Closed 2025-01-06.

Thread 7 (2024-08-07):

ADC filters should not be in series

gituser789, 2024-08-07:
# Description of failure
Filtering for ADC and error comparator are in series. This leads to unwanted linking in filter time constants and also in filter functionality, because the first filter resistor limits the current for the second filter. This results in an unwanted input signal for the input comparator.

# Workaround
The workaround is to bring the filter values to uncritical values (r1=100, c1=1n, r2=2k2, c2=1n).

# Real fix
The final solution is a schematic change in placing the filters in parallel, not in series.

- [ ] Replace filter values for the comparator inputs
- [ ] update schematic to the new values

VijayThera, 2024-12-19:
Updated schematics with parallel connection

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

Closed 2024-12-19.

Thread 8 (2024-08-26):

Check if more 0603 components can be used instead of 0402

gituser789, 2024-08-26:
Especially for the components that are made for later adaption like the RC filters.
So it will be more easy to change these components (by soldering).

VijayThera, 2025-01-06:
changed all analog RC filters from 0402 to 0603

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

Closed 2025-01-10.

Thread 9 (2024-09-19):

increase board width for 1 mm

gituser789, 2024-09-19:
For processing in the vapour phase (hanging on the mounting rack to solder double sided PCBs)

gituser789, 2024-12-13:
* [ ] No board size increas
 * [ ] Defined space to hold the board during rework
 * [ ] Defined space should be marked

VijayThera, 2025-01-06:
No change to the board size
Defined space to hold the board during rework, marked the spaces on top layer silklayer

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

gituser789, 2025-01-06:
Please shade the area

Closed 2025-01-06.

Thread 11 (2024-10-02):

U902 Input Voltage range

gituser789, 2024-10-02:
Common mode input voltage range is not enough.

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

gituser789, 2024-12-13:
* [ ] check needed current from analog part of the controller
* [ ] check provided current from LDO
* [ ] Remove the buffer

VijayThera, 2024-12-19:
**Removed buffer U902**
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

needed current for analog part of the controller - Max. 20 mA
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

provided current from LDO - Typ. ~ 30 mA
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

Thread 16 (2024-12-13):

Possibility to find broken parts on the LCB

gituser789, 2024-12-13:
- [x] e.g. adding `0 Ohm` resisistors for different sub-circuits
 - [ ] or working with two 3V3 supplies

VijayThera, 2024-12-29:
added 0R for different sub-circuits

Closed 2024-12-29.

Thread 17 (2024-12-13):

Think about removing the hardware error latch

gituser789, 2024-12-13:
Too custom. Users may use their own latch on their power electronics PCB

VijayThera, 2025-01-10:
After considering Mr. Schafmeister's comments/ideas, it is decided to keep the hardware error detection circuit for this version 1.1.0

Closed 2025-01-10.

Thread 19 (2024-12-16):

Use same filter time constants for all analog filters

gituser789, 2024-12-16:
different time constants are more confusing for the user.
Time constants should be same by default.
The user needs to configure them anyway.

VijayThera, 2024-12-19:
fixed all time constants to 100ns

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

gituser789, 2025-01-13:
Bring back the different time constants
 * Highlight with different colors (maybe background colors?) the different time constants

VijayThera, 2025-01-20:
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

Closed 2025-01-20.

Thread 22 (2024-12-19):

Holes for adding plastic spacers in the combo-area of holder for rework-station (on debugger side only)

gituser789, 2024-12-19:

VijayThera, 2025-01-06:
added M3 hole for spacer

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

Closed 2025-01-06.

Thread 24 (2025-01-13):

Housing sizes for error latch

gituser789, 2025-01-13:
The error latch is made of two compnents: `Comparator` and `Flip-Flop`.
The comparator is the device where soldering with cables is often necessary.
Make this device bigger (keep existing library symbol and make a new one for the bigger device)

The copmarator can be smaller, as soldering with cables is not necessary/planned here.
Make this device smaller (keep existing library symbol and make a new one for the smaller device)

VijayThera, 2025-01-20:
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

Closed 2025-01-23.

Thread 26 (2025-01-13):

Move filter input capacitor to input voltage devider

gituser789, 2025-01-13:
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

gituser789, 2025-01-13:
Function description:
`C809` is for faster switching of the comparator.
 * The reference voltage is in steady state always the same and stable
 * during switching event, additional current flows trough `R809` and the reference changes just for the switching event
 * this leads to a bigger difference between `+` and `-` input pins
 * together with the amplification of the opamp, the switching event speeds up, as the +/- difference is bigger

An additional parallel capacitor to `R815` would lead to stabilization of the reference voltage and would work against the described functionality.

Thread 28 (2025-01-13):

XDS connector update and pre-test necessary

gituser789, 2025-01-13:
The pin header for external debugger connection should be more robust and proof against twist (wrong connector direction).
 * look on the internet for XDS500 and XDS1000 debugger, and check common connectors
 * See if the are twist-proof and may add the connector

Next, a pre-investigation is necessary:
 * small lab setup, and see if external debugger can be used in general. Also check, if external debugger is more robust than internal one. There must be an XDS200 somewhere in the lab.
 * See if any disconnection of on-board XDS100 debugger is necessary if external one is used
 * if yes, add a switch on the PCB what can disconnect the on-board debugger easily

Closed 2025-02-19.

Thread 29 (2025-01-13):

Controller update

gituser789, 2025-01-13:
Update the material number and the symbol name of the actual core controller to the dual core controller.
* overwriter old material number, use same symbol.
* In description, replace the `x` with `8`
* New mouser number: `595-F28388DZWTSR` (very important is the `R` in the end for `tape and reel`).

VijayThera, 2025-01-23:
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

Closed 2025-01-23.

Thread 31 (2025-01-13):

Reset button

gituser789, 2025-01-13:
* `R715` should be `10 Ohm`, which acts as a low pass filter with the given `C` to debounce the switch
* Add `Reset` on the silkscreen next to the switch

Closed 2025-01-17.

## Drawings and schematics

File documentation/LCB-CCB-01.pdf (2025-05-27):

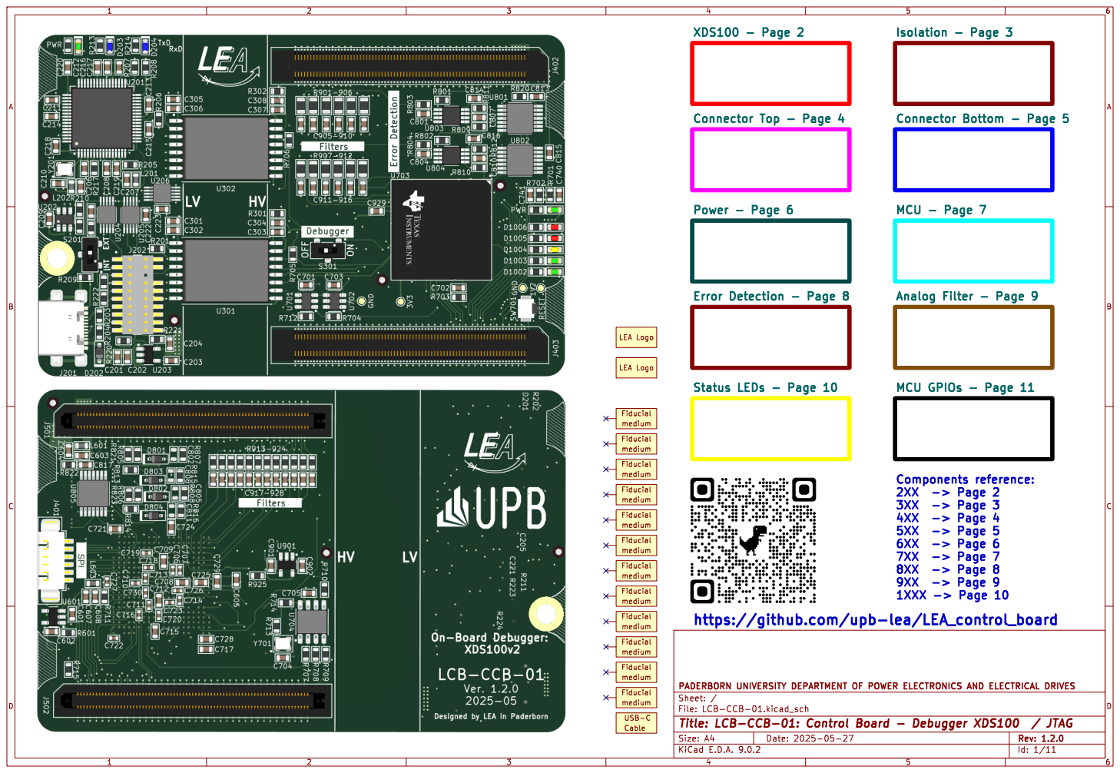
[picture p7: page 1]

LEA Logo Fiducial medium

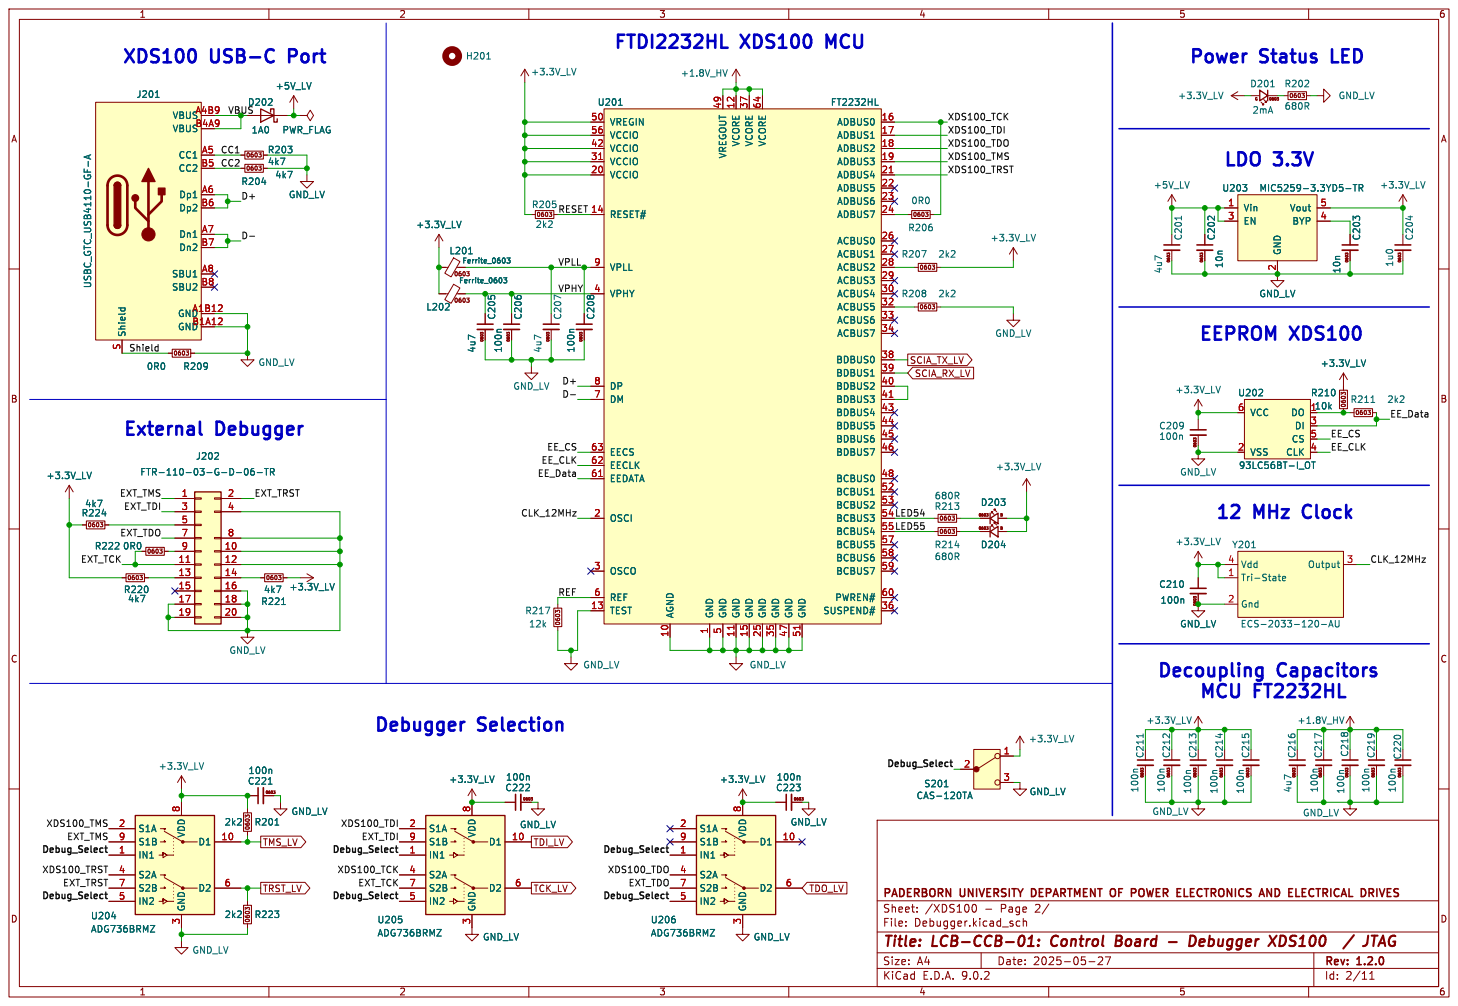
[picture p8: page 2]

5 VCORE 12 GND 11 VCORE 37 GND 15 VCORE 64 GND 25 GND 35 GND 47 GND 51 ADBUS0 16 ADBUS1 17 ADBUS2 18 ADBUS3 19 ADBUS4 21 ADBUS5 22 ADBUS6 23 ADBUS7 24 ACBUS0 26 ACBUS1 27 ACBUS2 28 ACBUS3 29 ACBUS4 30 ACBUS5 32 ACBUS6 33 ACBUS7 34 BDBUS0 38 BDBUS1 39 BDBUS2 40 BDBUS3 41 BDBUS4 43 BDBUS5 44 BDBUS6 45 BDBUS7 46 BCBUS0 48 BCBUS1 52 BCBUS2 53 BCBUS3 54 BCBUS4 55 BCBUS5 57 BCBUS6 58 BCBUS7 59 PWREN# 60 SUSPEND# 36 C208 100n C206 100n C205 4u7

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

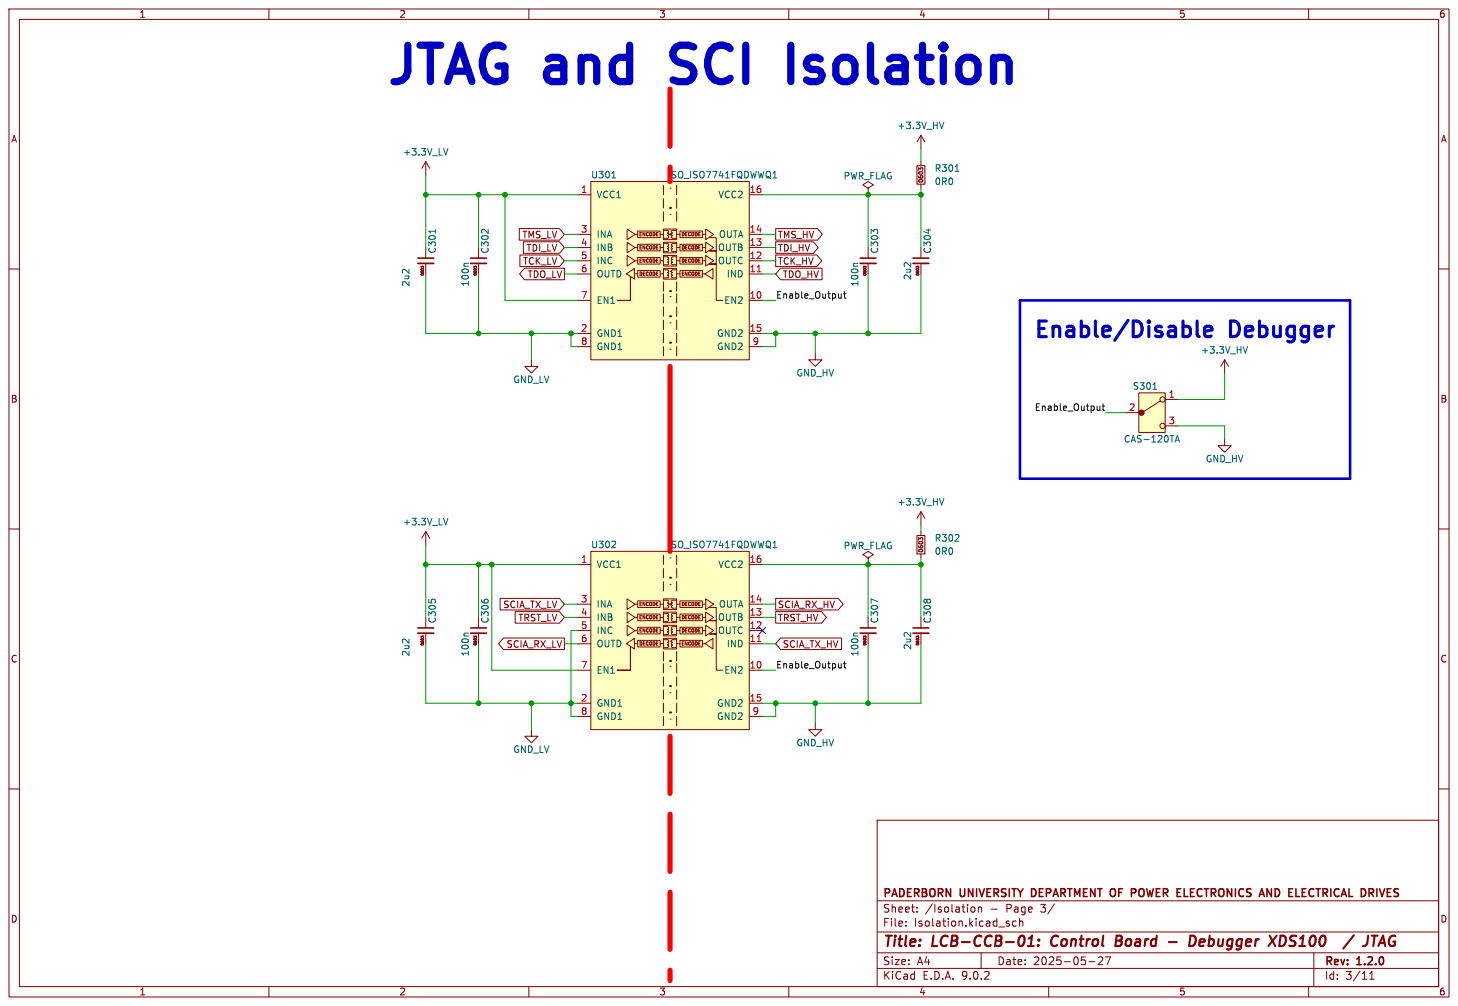
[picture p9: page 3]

JTAG and SCI Isolation

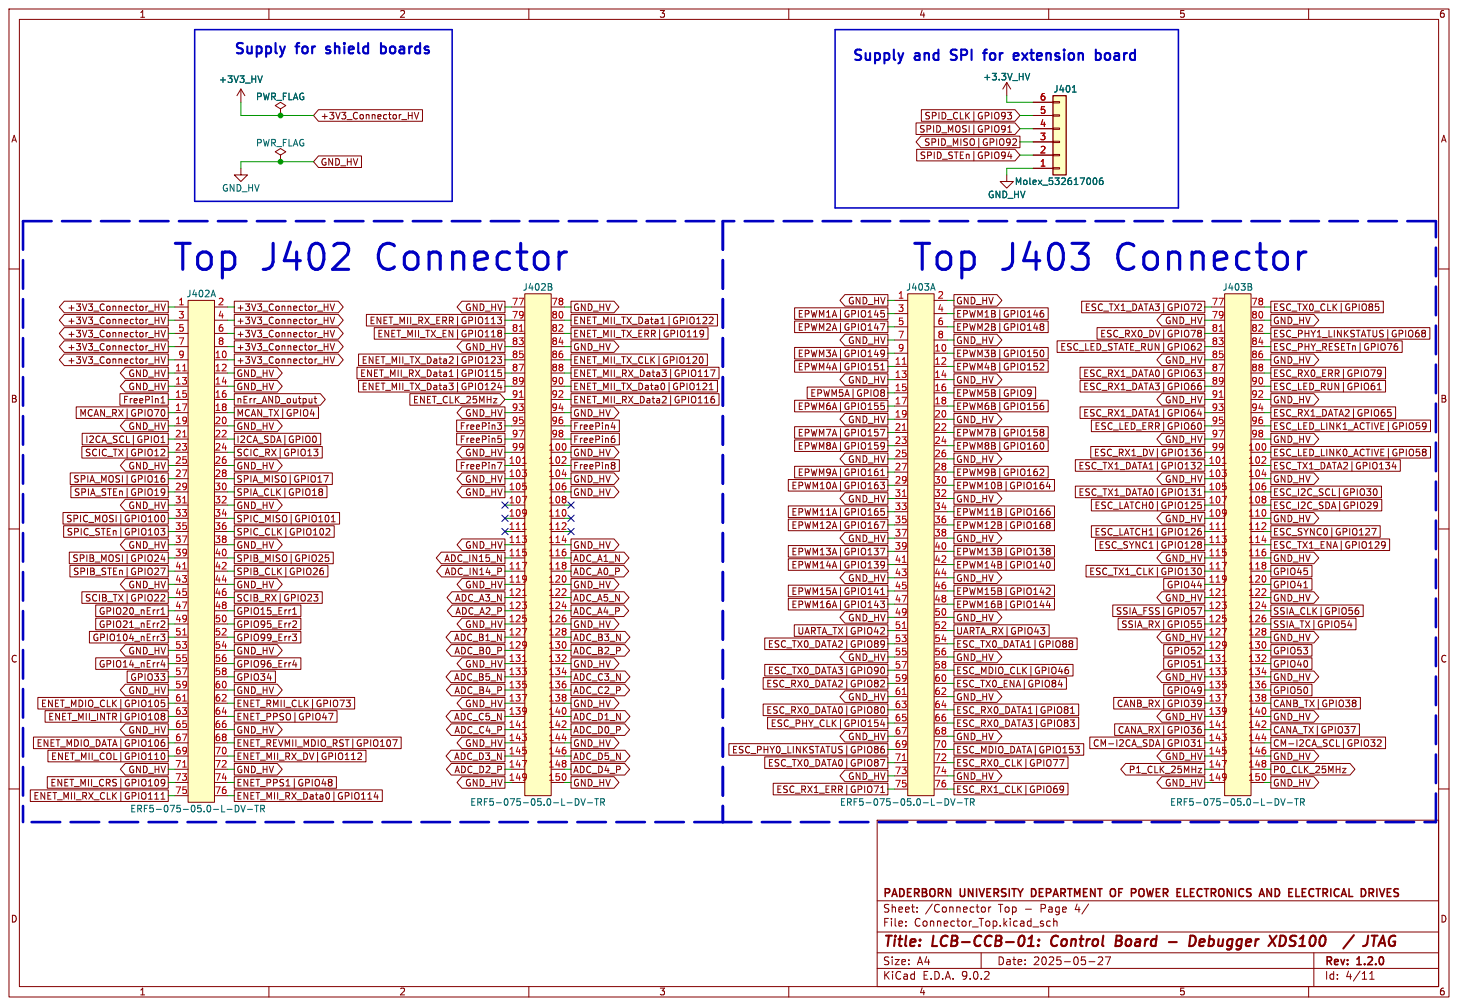
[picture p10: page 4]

Supply for shield boards

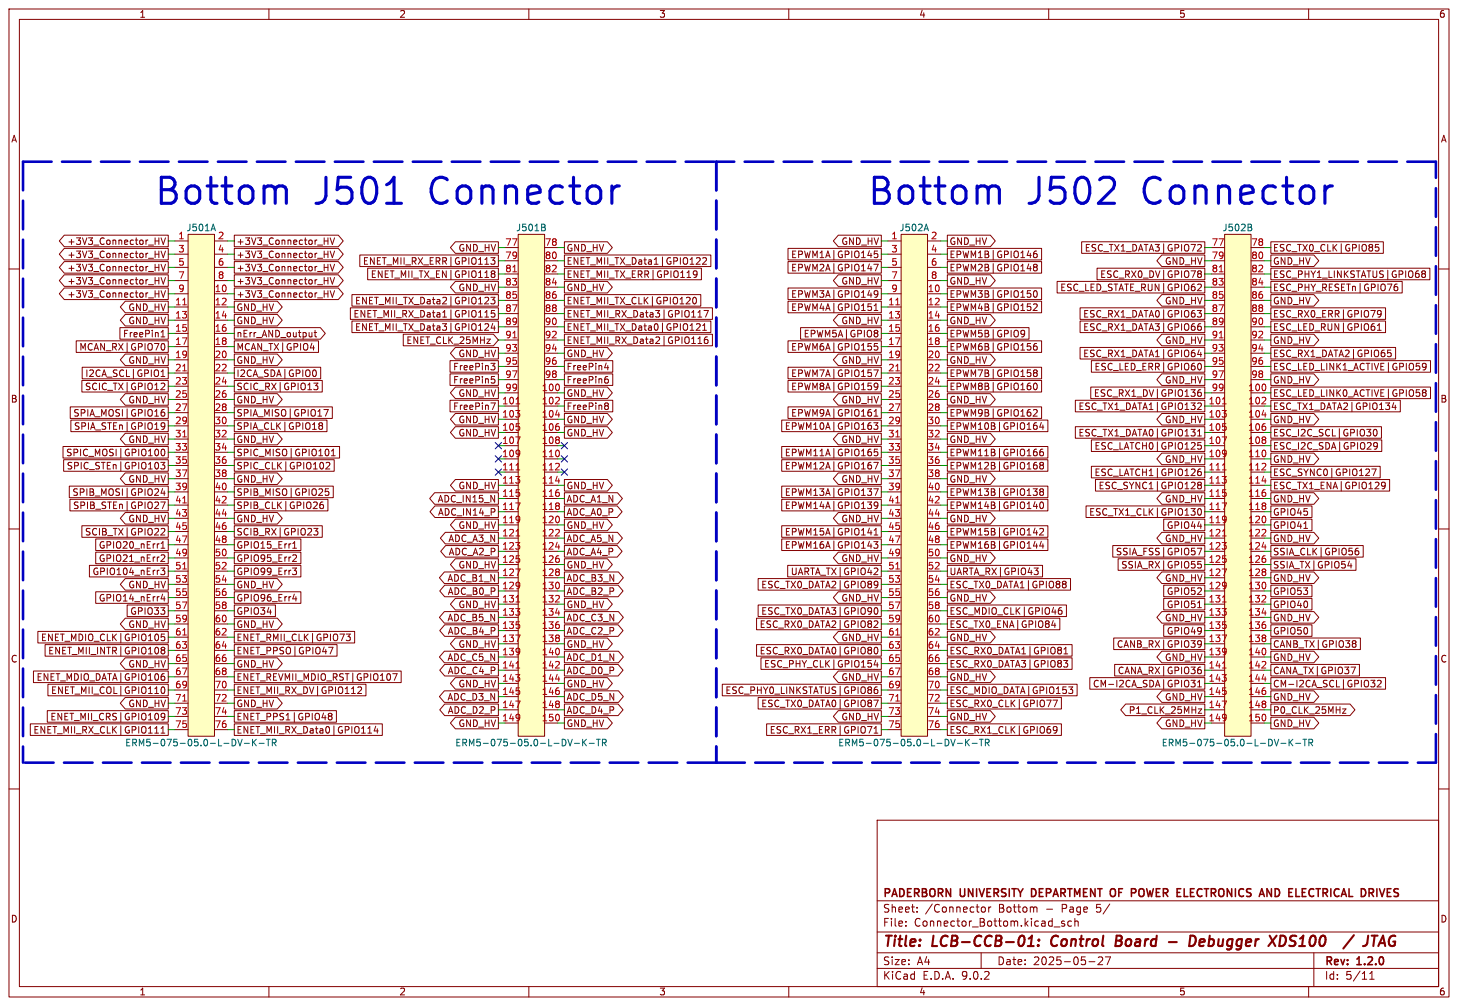
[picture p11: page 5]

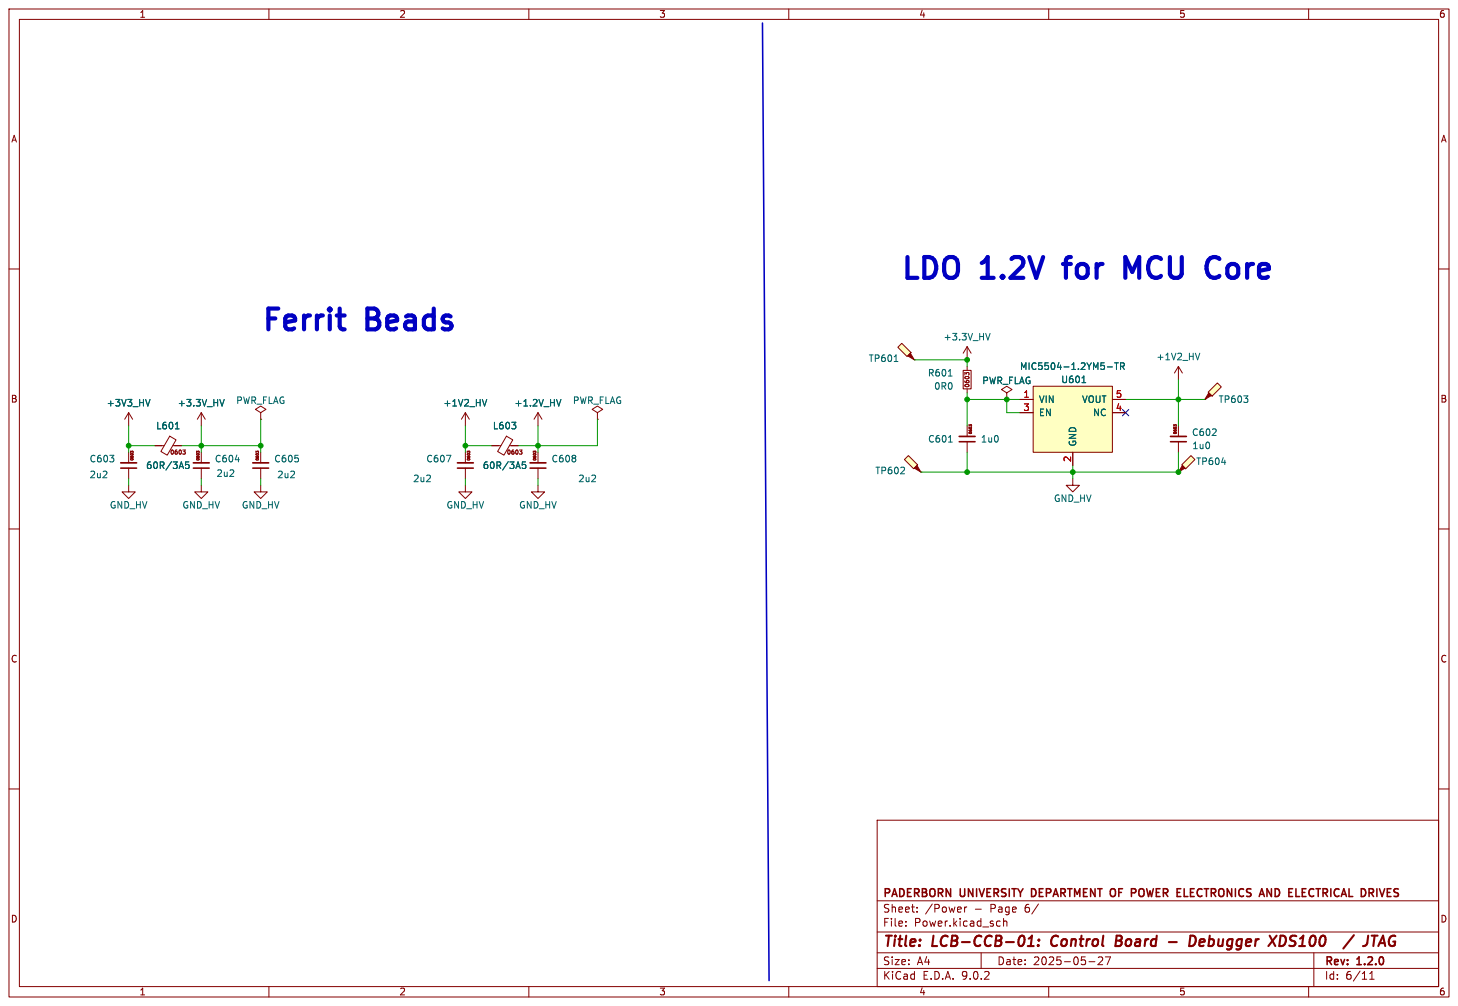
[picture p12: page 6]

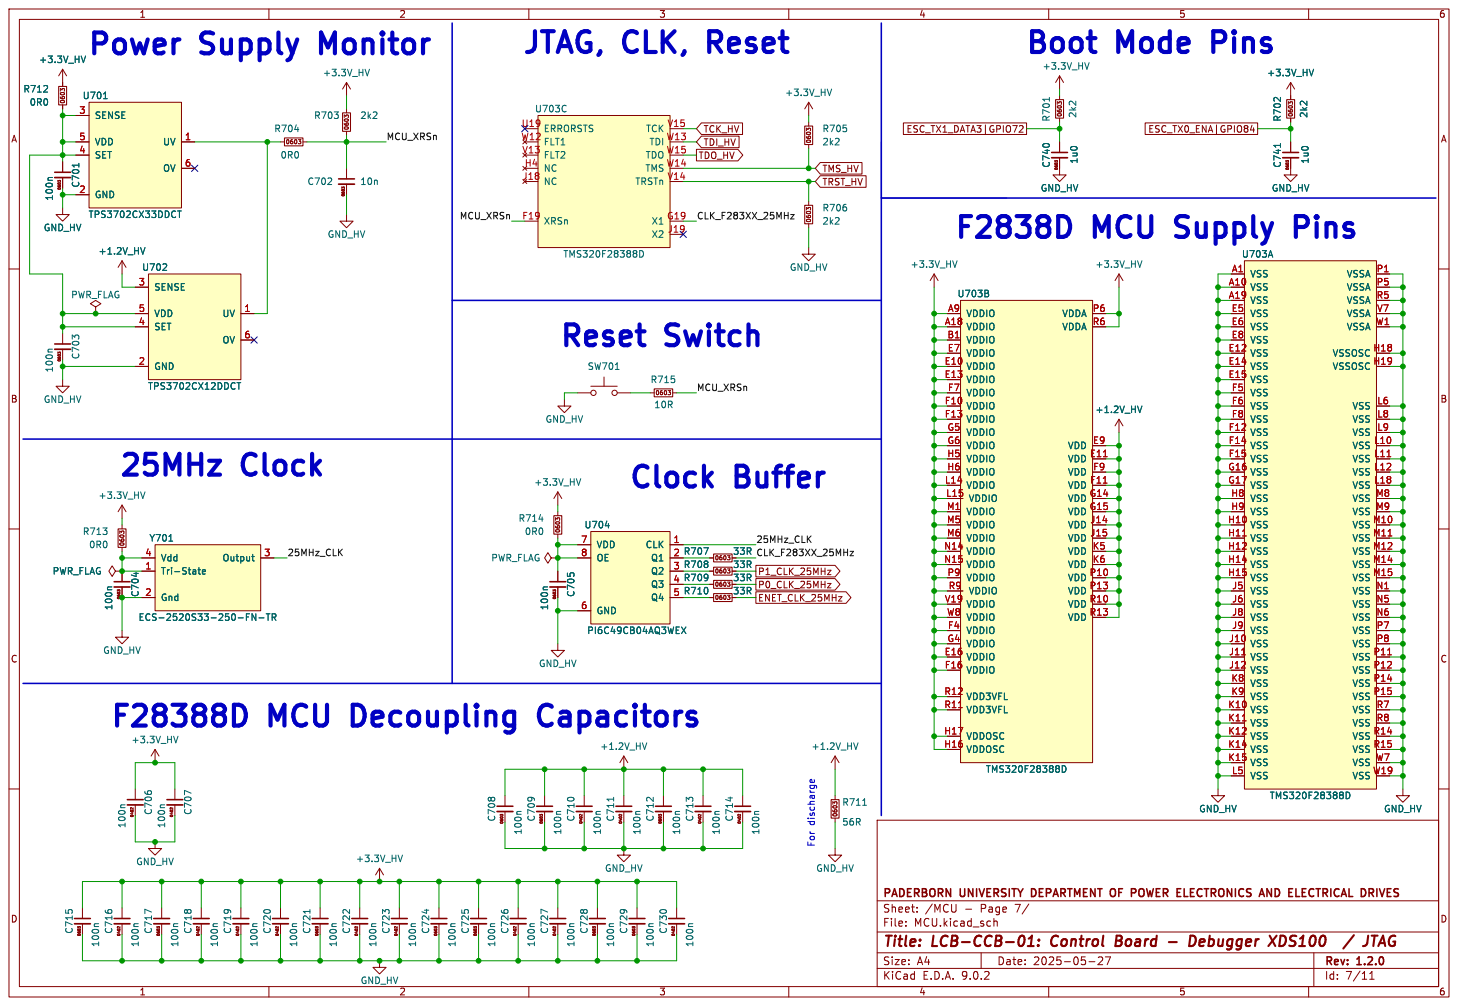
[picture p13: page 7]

Boot Mode Pins For discharge
VDDA P6 VDDA R6 VDD E9 VDD E11 VDD F9 VDD F11 VDD G14 VDD G15 VDD J14 VDD J15 VDD K5 VDD K6 VDD P10 VDD P13 VDD R10 VDD R13 U703B
VDDIO A9 VDDIO A18 VDDIO B1 VDDIO E7 VDDIO E10 VDDIO E13 VDDIO F7 VDDIO F10 VDDIO F13 VDDIO G5 VDDIO G6 VDDIO H5 VDDIO H6 VDDIO L14 VDDIO L15 VDDIO M1 VDDIO M5 VDDIO M6 VDDIO N14 VDDIO N15 VDDIO P9 VDDIO R9 VDDIO V19 VDDIO W8 VDDIO F4 VDDIO G4 VDDIO E16 VDDIO F16 VDD3VFL R12 VDD3VFL R11 VDDOSC H17 VDDOSC H16

VSSA P1 VSSA P5 VSSA R5 VSSA V7 VSSA W1 VSSOSC H18 VSSOSC H19 VSS L6 VSS L8 VSS L9 VSS L10 VSS L11 VSS L12 VSS L18 VSS M8 VSS M9 VSS M10 VSS M11 VSS M12 VSS M14 VSS M15 VSS N1 VSS N5 VSS N6 VSS P7 VSS P8 VSS P11 VSS P12 VSS P14 VSS P15 VSS R7 VSS R8 VSS R14 VSS R15 VSS W7 VSS W19GND_HV

F2838D MCU Supply Pins

VSS A1 VSS A10 VSS A19 VSS E5 VSS E6 VSS E8 VSS E12 VSS E14 VSS E15 VSS F5 VSS F6 VSS F8 VSS F12 VSS F14 VSS F15 VSS G16 VSS G17 VSS H8 VSS H9 VSS H10 VSS H11 VSS H12 VSS H14 VSS H15 VSS J5 VSS J6 VSS J8 VSS J9 VSS J10 VSS J11 VSS J12 VSS K8 VSS K9 VSS K10 VSS K11 VSS K12 VSS K14 VSS K15 VSS L5

VSSA P1 VSSA P5 VSSA R5 VSSA V7 VSSA W1 VSSOSC H18 VSSOSC H19 VSS L6 VSS L8 VSS L9 VSS L10 VSS L11 VSS L12 VSS L18 VSS M8 VSS M9 VSS M10 VSS M11 VSS M12 VSS M14 VSS M15 VSS N1 VSS N5 VSS N6 VSS P7 VSS P8 VSS P11 VSS P12 VSS P14 VSS P15 VSS R7 VSS R8 VSS R14 VSS R15 VSS W7 VSS W19

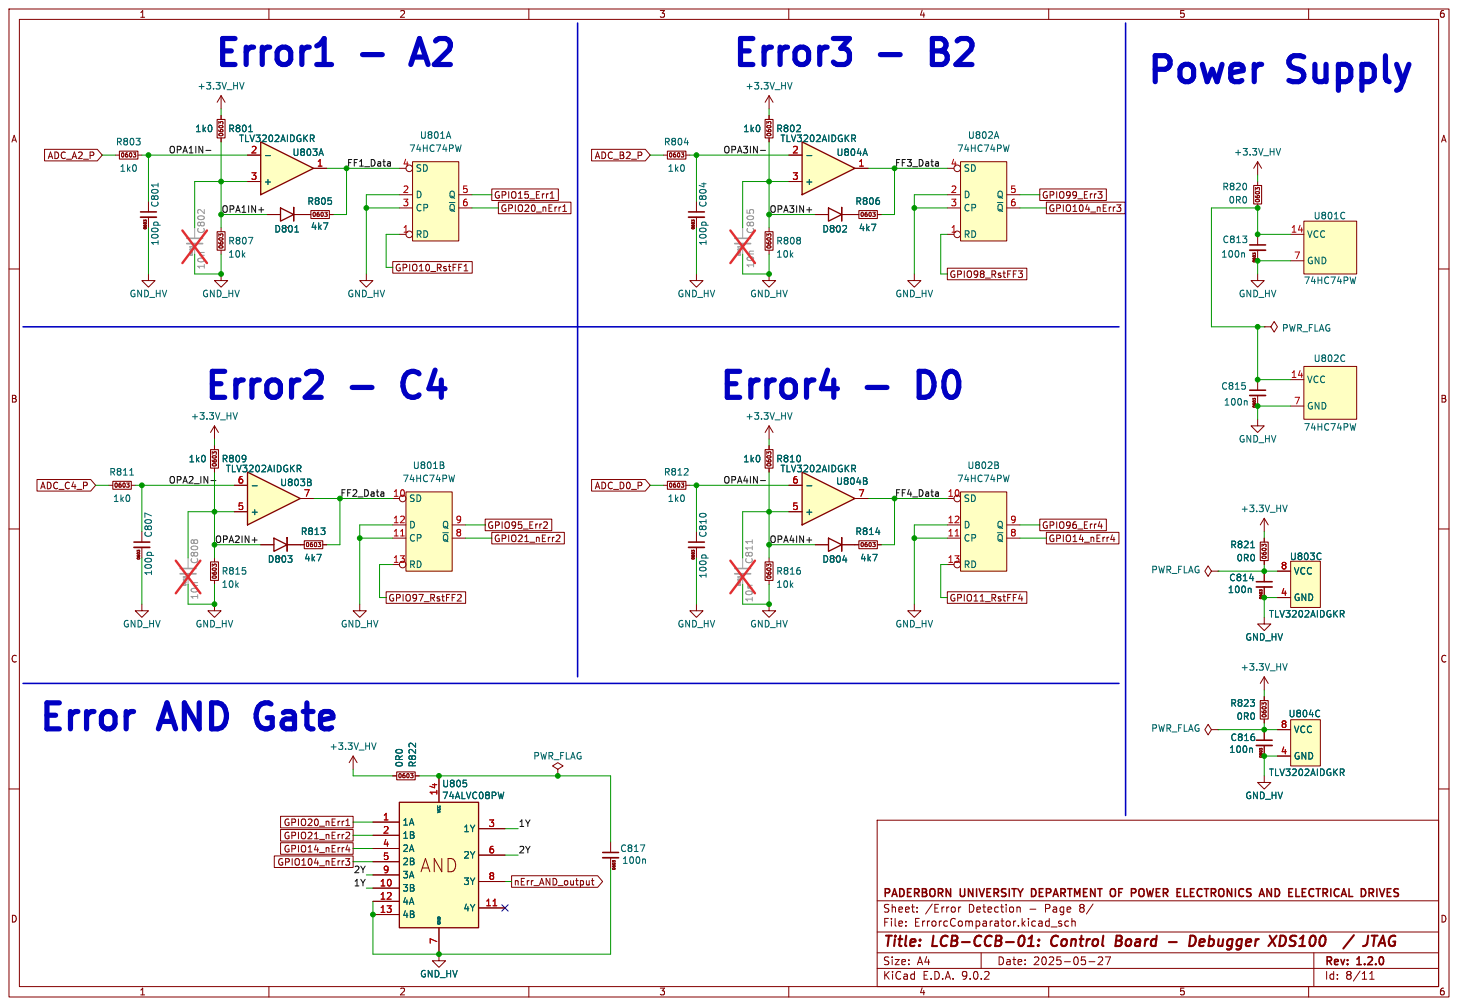
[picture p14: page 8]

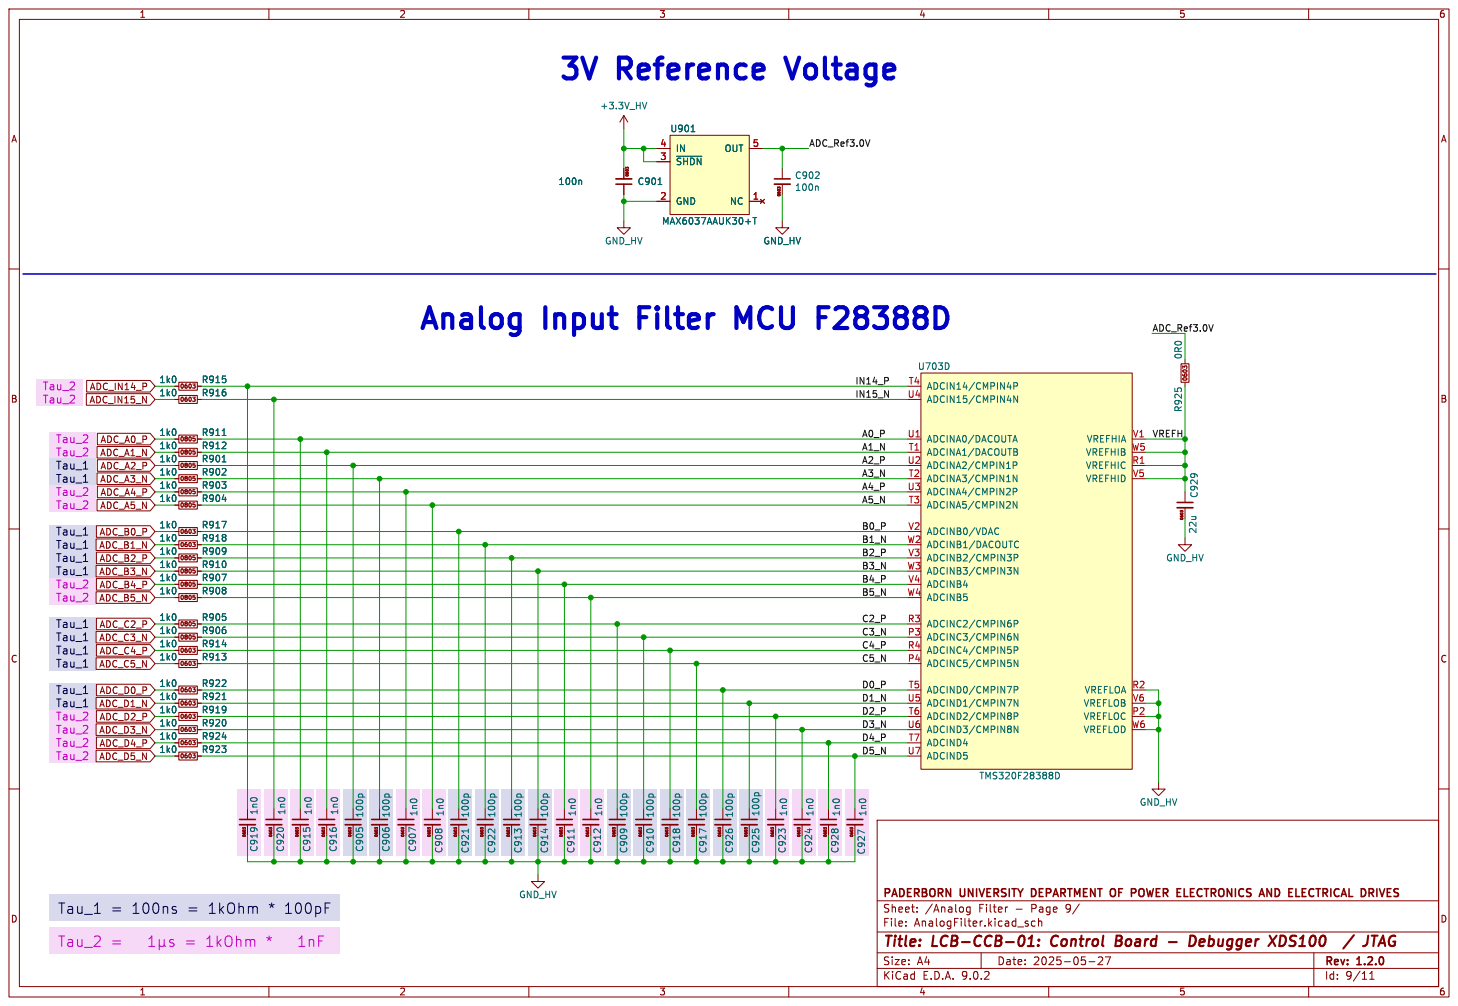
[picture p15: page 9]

Analog Input Filter MCU F28388D

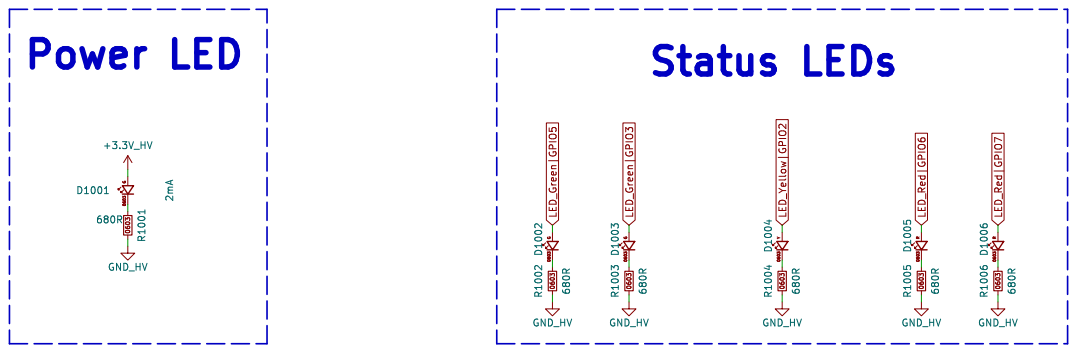
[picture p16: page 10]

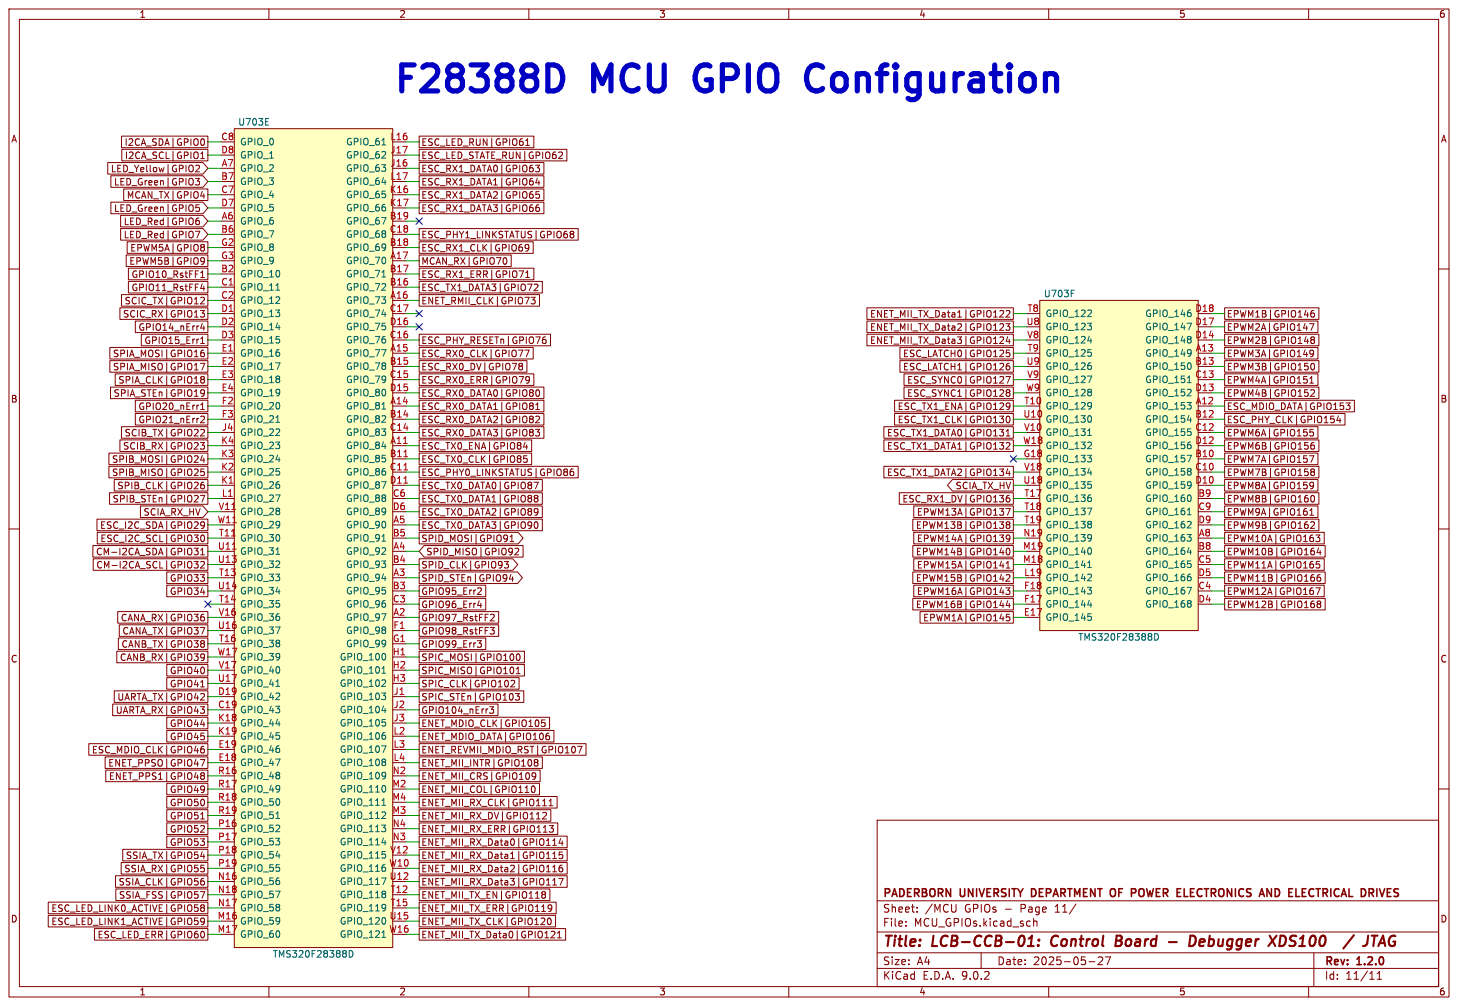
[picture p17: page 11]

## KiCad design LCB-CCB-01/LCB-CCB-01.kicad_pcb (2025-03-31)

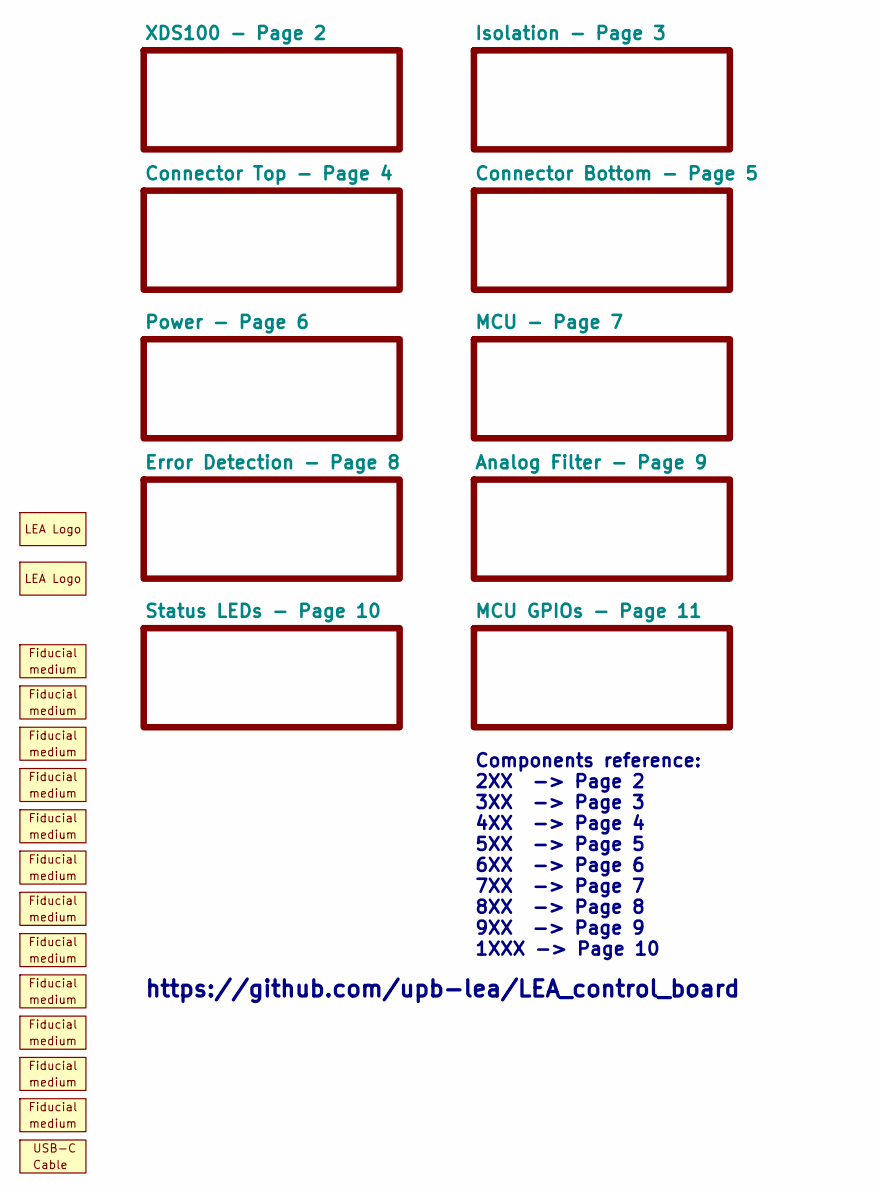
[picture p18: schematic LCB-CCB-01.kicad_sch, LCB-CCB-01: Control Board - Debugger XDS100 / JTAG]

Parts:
ACCESSORY901: ACCESSORY_USB_C_cable; mouser# 474-CAB-15424
O901, O902, O903, O904, O905, O906, O907, O908, O909, O910, O911, O912: Fiducial_medium; Fiducials_medium
SYM901, SYM902: SYM_LEA_Logo; SYM_lea_logo

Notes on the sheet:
Components reference: 2XX -> Page 2 3XX -> Page 3 4XX -> Page 4 5XX -> Page 5 6XX -> Page 6 7XX -> Page 7 8XX -> Page 8 9XX -> Page 9 1XXX -> Page 10
https://github.com/upb-lea/LEA_control_board

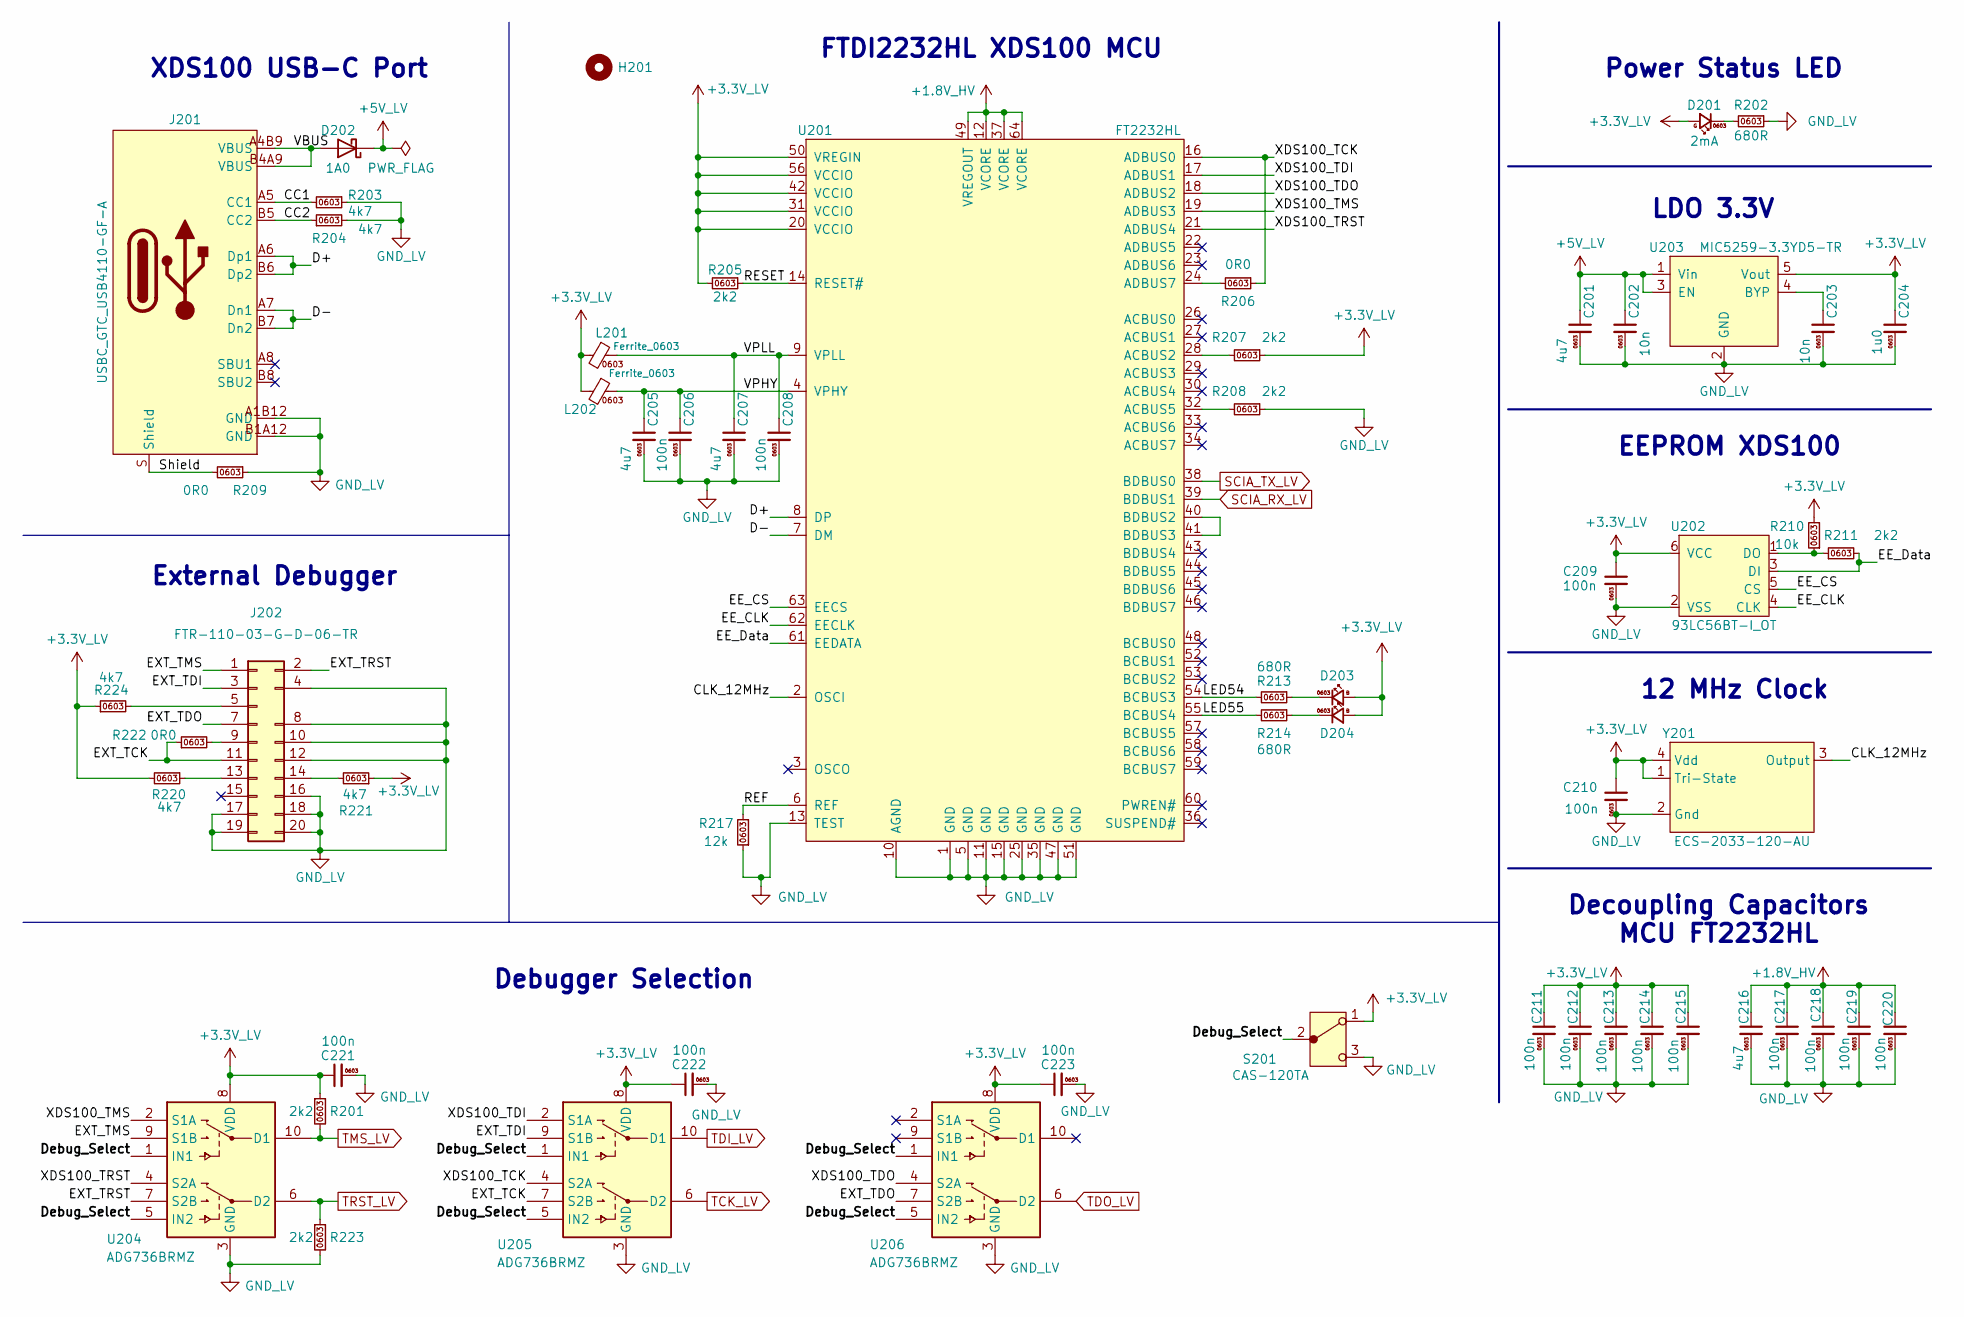
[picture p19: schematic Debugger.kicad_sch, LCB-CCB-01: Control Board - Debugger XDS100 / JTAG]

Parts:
C201, C205, C207, C216: 4u7; C_0603; mouser# 810-C1608X5R1V475K
C202, C203: 10n; C_0603; mouser# 810-CGA3E2X7R1H103K
C204: 1u0; C_0603; mouser# 810-C1608X5R1H105K
C206, C208, C209, C210, C211, C212, C213, C214, C215, C217, C218, C219, C220, C221, C222, C223: 100n; C_0603; mouser# 810-C1608X5R1H104K
D201: 2mA; LED_0603_G; mouser# 604-APTD1608LCGCK
D202: 1A0; SOD-323_Infineon; mouser# 726-BAS3010A-03WE6
D203, D204: 2mA; LED_0603_B; mouser# 604-APHD1608LVBCD
H201: M3_MountingHole; MountingHole_M3
J201: USBC_GTC_USB4110-GF-A; USB_C_GCT_USB4110-GF-A; mouser# 640-USB4110-GF-A
J202: FTR-110-03-G-D-06-TR; FTR-110-03-G-D-06; mouser# 200-FTR11003GD06TR
L201, L202: Ferrite_0603; L_0603; mouser# 530-FCB-0603-601A
R201, R205, R207, R208, R211, R223: 2k2; R_0603; mouser# 71-CRCW06032K20FKEAC
R202, R213, R214: 680R; R_0603; mouser# 71-CRCW0603680RFKEAC
R203, R204, R220, R221, R224: 4k7; R_0603; mouser# 71-CRCW06034K70FKEBC
R206, R209, R222: 0R0; R_0603; mouser# 71-CRCW06030000Z0EAC
R210: 10k; R_0603; mouser# 71-CRCW060310K0FKEAC
R217: 12k; R_0603; mouser# 71-CRCW060312K0FKEAC
S201: CAS-120TA; mouser# 229-CAS-120TA
U201: FT2232HL; LQFP-64_12x12_Pitch0.5mm_FTDI; mouser# 895-FT2232HL-TRAY
U202: 93LC56BT-I_OT; SOT-23-6_Microchip; mouser# 579-93LC56BT-I/OT
U203: MIC5259-3.3YD5-TR; SOT-23-5_Microchip; mouser# 998-MIC5259-3.3YD5TR
U204, U205, U206: ADG736BRMZ; MSOP10_AnalogDevices; mouser# 584-ADG736BRMZ
Y201: ECS-2033-120-AU; Osc_ECS_2.5x2; mouser# 520-2033-120-AU

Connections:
+1.8V_HV: C216.1, C217.1, C218.1, C219.1, C220.1, U201.12 (VCORE), U201.37 (VCORE), U201.49 (VREGOUT), U201.64 (VCORE)
+3.3V_LV: C204.1, C209.1, C210.1, C211.1, C212.1, C213.1, C214.1, C215.1, C221.1, C222.1, C223.1, D201.A, D203.A, D204.A, L201.2, L202.2, R201.1, R205.2, R207.1, R210.2, R220.2, R221.1, R224.1, S201.1, U201.20 (VCCIO), U201.31 (VCCIO), U201.42 (VCCIO), U201.50 (VREGIN), U201.56 (VCCIO), U202.6 (VCC), U203.5 (Vout), U204.8 (VDD), U205.8 (VDD), U206.8 (VDD), Y201.1 (Tri-State), Y201.4 (Vdd); also elsewhere on the board
+5V_LV: C201.1, C202.1, D202.C, U203.1 (Vin), U203.3 (EN)
/XDS100 - Page 2/CC1: J201.A5 (CC1), R203.2
/XDS100 - Page 2/CC2: J201.B5 (CC2), R204.1
/XDS100 - Page 2/CLK_12MHz: U201.2 (OSCI), Y201.3 (Output)
/XDS100 - Page 2/D+: J201.A6 (Dp1), J201.B6 (Dp2), U201.8 (DP)
/XDS100 - Page 2/D-: J201.A7 (Dn1), J201.B7 (Dn2), U201.7 (DM)
/XDS100 - Page 2/Debug_Select: S201.2, U204.1 (IN1), U204.5 (IN2), U205.1 (IN1), U205.5 (IN2), U206.1 (IN1), U206.5 (IN2)
/XDS100 - Page 2/EE_CLK: U201.62 (EECLK), U202.4 (CLK)
/XDS100 - Page 2/EE_CS: U201.63 (EECS), U202.5 (CS)
/XDS100 - Page 2/EE_Data: R211.2, U201.61 (EEDATA), U202.3 (DI)
/XDS100 - Page 2/EXT_TCK: J202.11, R222.1, U205.7 (S2B)
/XDS100 - Page 2/EXT_TDI: J202.3, U205.9 (S1B)
/XDS100 - Page 2/EXT_TDO: J202.7, U206.7 (S2B)
/XDS100 - Page 2/EXT_TMS: J202.1, U204.9 (S1B)
/XDS100 - Page 2/EXT_TRST: J202.2, U204.7 (S2B)
/XDS100 - Page 2/LED54: R213.2, U201.54 (BCBUS3)
/XDS100 - Page 2/LED55: R214.2, U201.55 (BCBUS4)
/XDS100 - Page 2/REF: R217.2, U201.6 (REF)
/XDS100 - Page 2/RESET: R205.1, U201.14 (RESET#)
/XDS100 - Page 2/Shield: J201.S (Shield), R209.2
/XDS100 - Page 2/VBUS: D202.A, J201.A4B9 (VBUS), J201.B4A9 (VBUS)
/XDS100 - Page 2/VPHY: C205.1, C206.1, L202.1, U201.4 (VPHY)
/XDS100 - Page 2/VPLL: C207.1, C208.1, L201.1, U201.9 (VPLL)
/XDS100 - Page 2/XDS100_TCK: R206.1, U201.16 (ADBUS0), U205.4 (S2A)
/XDS100 - Page 2/XDS100_TDI: U201.17 (ADBUS1), U205.2 (S1A)
/XDS100 - Page 2/XDS100_TDO: U201.18 (ADBUS2), U206.4 (S2A)
/XDS100 - Page 2/XDS100_TMS: U201.19 (ADBUS3), U204.2 (S1A)
/XDS100 - Page 2/XDS100_TRST: U201.21 (ADBUS4), U204.4 (S2A)
GND_LV: C201.2, C202.2, C203.2, C204.2, C205.2, C206.2, C207.2, C208.2, C209.2, C210.2, C211.2, C212.2, C213.2, C214.2, C215.2, C216.2, C217.2, C218.2, C219.2, C220.2, C221.2, C222.2, C223.2, J201.A1B12 (GND), J201.B1A12 (GND), J202.4, J202.8, J202.10, J202.12, J202.16, J202.17, J202.18, J202.19, J202.20, R202.1, R203.1, R204.2, R208.1, R209.1, R217.1, R223.2, S201.3, U201.1 (GND), U201.5 (GND), U201.10 (AGND), U201.11 (GND), U201.13 (TEST), U201.15 (GND), U201.25 (GND), U201.35 (GND), U201.47 (GND), U201.51 (GND), U202.2 (VSS), U203.2 (GND), U204.3 (GND), U205.3 (GND), U206.3 (GND), Y201.2 (Gnd); also elsewhere on the board
unnamed: D201.C, R202.2
unnamed: D203.C, R213.1
unnamed: D204.C, R214.1
unnamed: J202.5, R224.2
unnamed: J202.9, R222.2
unnamed: J202.13, R220.1
unnamed: J202.14, R221.2
unnamed: R207.2, U201.28 (ACBUS2)
unnamed: R208.2, U201.32 (ACBUS5)
unnamed: R206.2, U201.24 (ADBUS7)
unnamed: U201.40 (BDBUS2), U201.41 (BDBUS3)
unnamed: R210.1, R211.1, U202.1 (DO)
unnamed: C203.1, U203.4 (BYP)
SCIA_RX_LV: U201.39 (BDBUS1); also elsewhere on the board
SCIA_TX_LV: U201.38 (BDBUS0); also elsewhere on the board
TCK_LV: U205.6 (D2); also elsewhere on the board
TDI_LV: U205.10 (D1); also elsewhere on the board
TDO_LV: U206.6 (D2); also elsewhere on the board
TMS_LV: R201.2, U204.10 (D1); also elsewhere on the board
TRST_LV: R223.1, U204.6 (D2); also elsewhere on the board

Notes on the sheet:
Power Status LED
EEPROM XDS100
Decoupling Capacitors MCU FT2232HL
Debugger Selection
External Debugger
XDS100 USB-C Port
FTDI2232HL XDS100 MCU
12 MHz Clock
LDO 3.3V

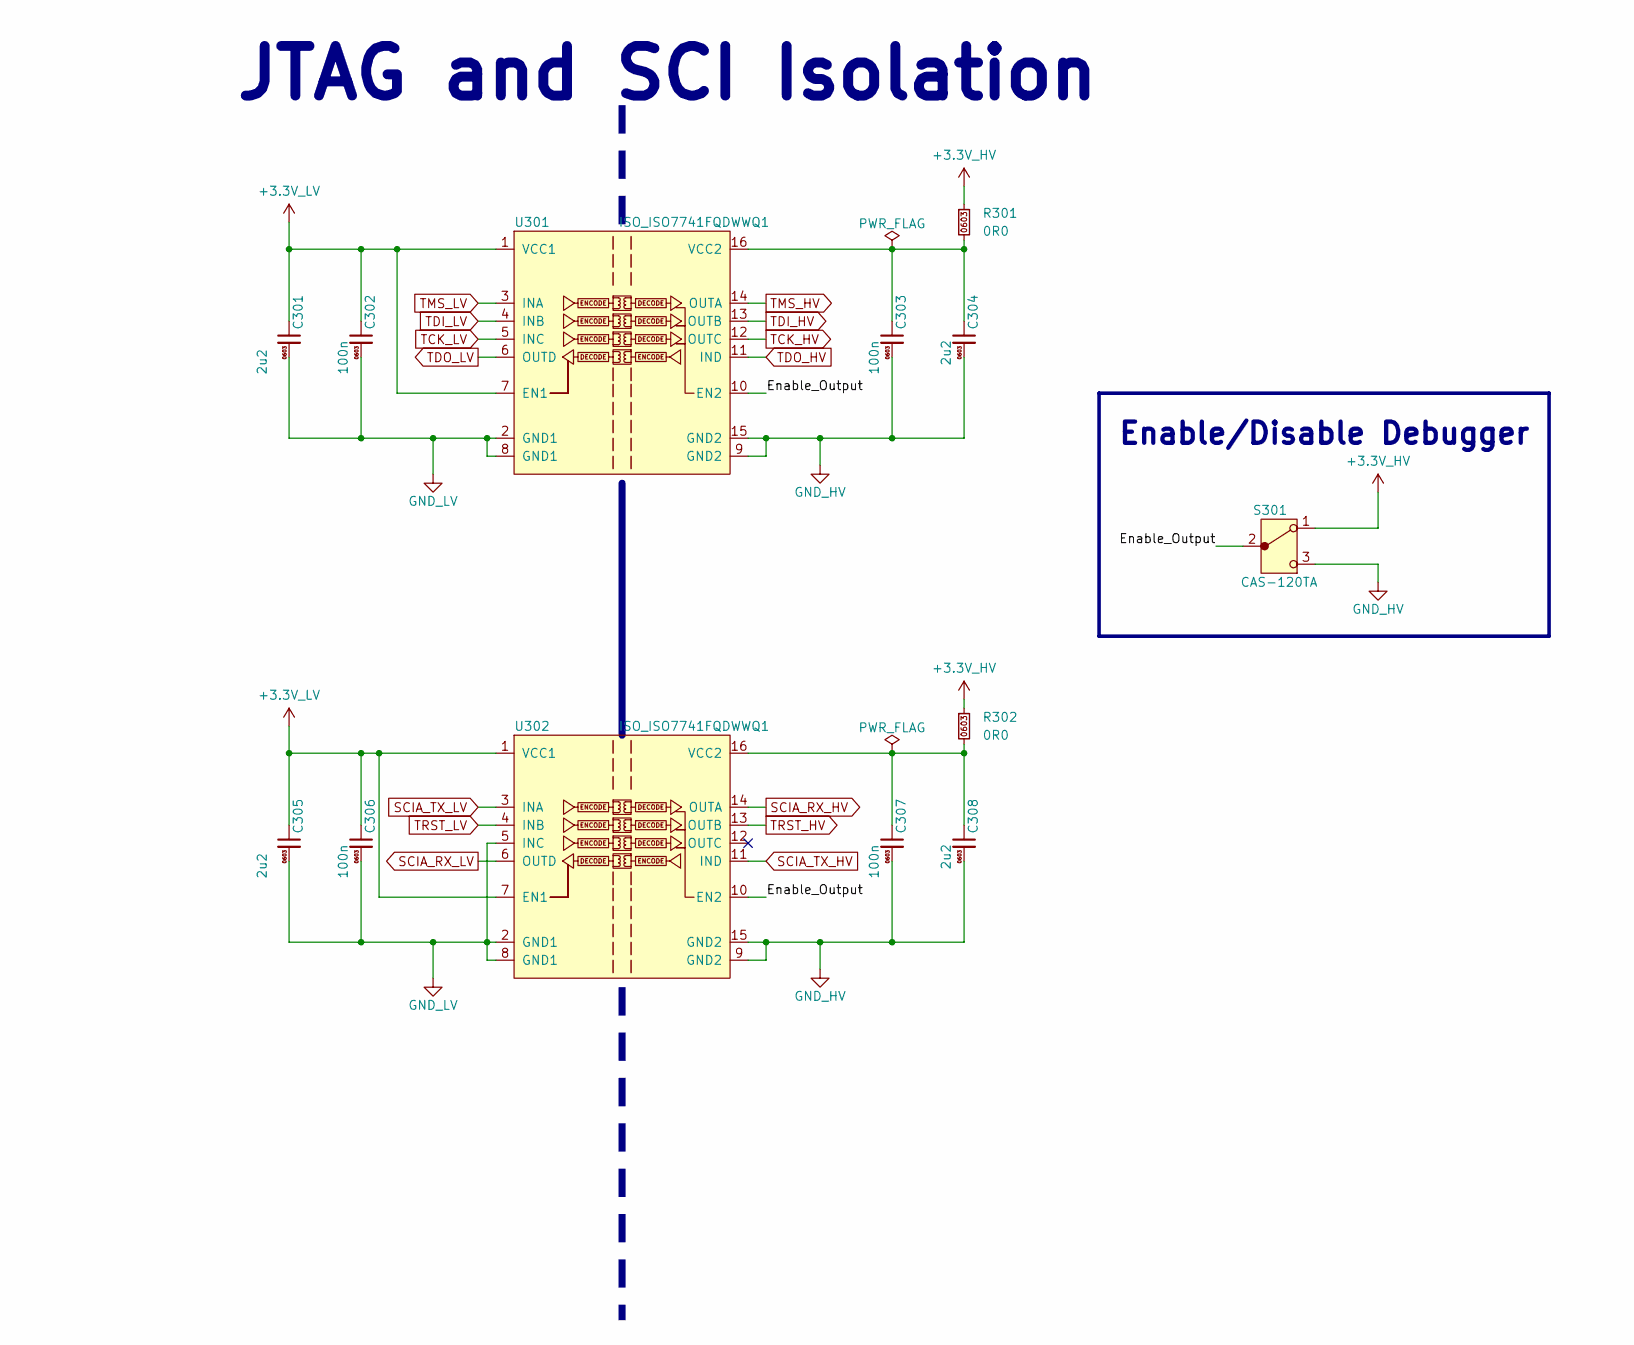
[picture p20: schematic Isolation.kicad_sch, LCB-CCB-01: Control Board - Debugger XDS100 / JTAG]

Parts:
C301, C304, C305, C308: 2u2; C_0603; mouser# 810-C1608X5R1V225K
C302, C303, C306, C307: 100n; C_0603; mouser# 810-C1608X5R1H104K
R301, R302: 0R0; R_0603; mouser# 71-CRCW06030000Z0EAC
S301: CAS-120TA; mouser# 229-CAS-120TA
U301, U302: ISO_ISO7741FQDWWQ1; SOIC-16_TI_DWW0016A_Optimized; mouser# 595-ISO7741FQDWWQ1

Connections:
+3.3V_HV: R301.1, R302.1, S301.1; also elsewhere on the board
+3.3V_LV: C301.1, C302.1, C305.1, C306.1, U301.1 (VCC1), U301.7 (EN1), U302.1 (VCC1), U302.7 (EN1); also elsewhere on the board
/Isolation - Page 3/Enable_Output: S301.2, U301.10 (EN2), U302.10 (EN2)
GND_HV: C303.2, C304.2, C307.2, C308.2, S301.3, U301.9 (GND2), U301.15 (GND2), U302.9 (GND2), U302.15 (GND2); also elsewhere on the board
GND_LV: C301.2, C302.2, C305.2, C306.2, U301.2 (GND1), U301.8 (GND1), U302.2 (GND1), U302.5 (INC), U302.8 (GND1); also elsewhere on the board
unnamed: C303.1, C304.1, R301.2, U301.16 (VCC2)
unnamed: C307.1, C308.1, R302.2, U302.16 (VCC2)
SCIA_RX_HV: U302.14 (OUTA); also elsewhere on the board
SCIA_RX_LV: U302.6 (OUTD); also elsewhere on the board
SCIA_TX_HV: U302.11 (IND); also elsewhere on the board
SCIA_TX_LV: U302.3 (INA); also elsewhere on the board
TCK_HV: U301.12 (OUTC); also elsewhere on the board
TCK_LV: U301.5 (INC); also elsewhere on the board
TDI_HV: U301.13 (OUTB); also elsewhere on the board
TDI_LV: U301.4 (INB); also elsewhere on the board
TDO_HV: U301.11 (IND); also elsewhere on the board
TDO_LV: U301.6 (OUTD); also elsewhere on the board
TMS_HV: U301.14 (OUTA); also elsewhere on the board
TMS_LV: U301.3 (INA); also elsewhere on the board
TRST_HV: U302.13 (OUTB); also elsewhere on the board
TRST_LV: U302.4 (INB); also elsewhere on the board

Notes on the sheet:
JTAG and SCI Isolation
Enable/Disable Debugger

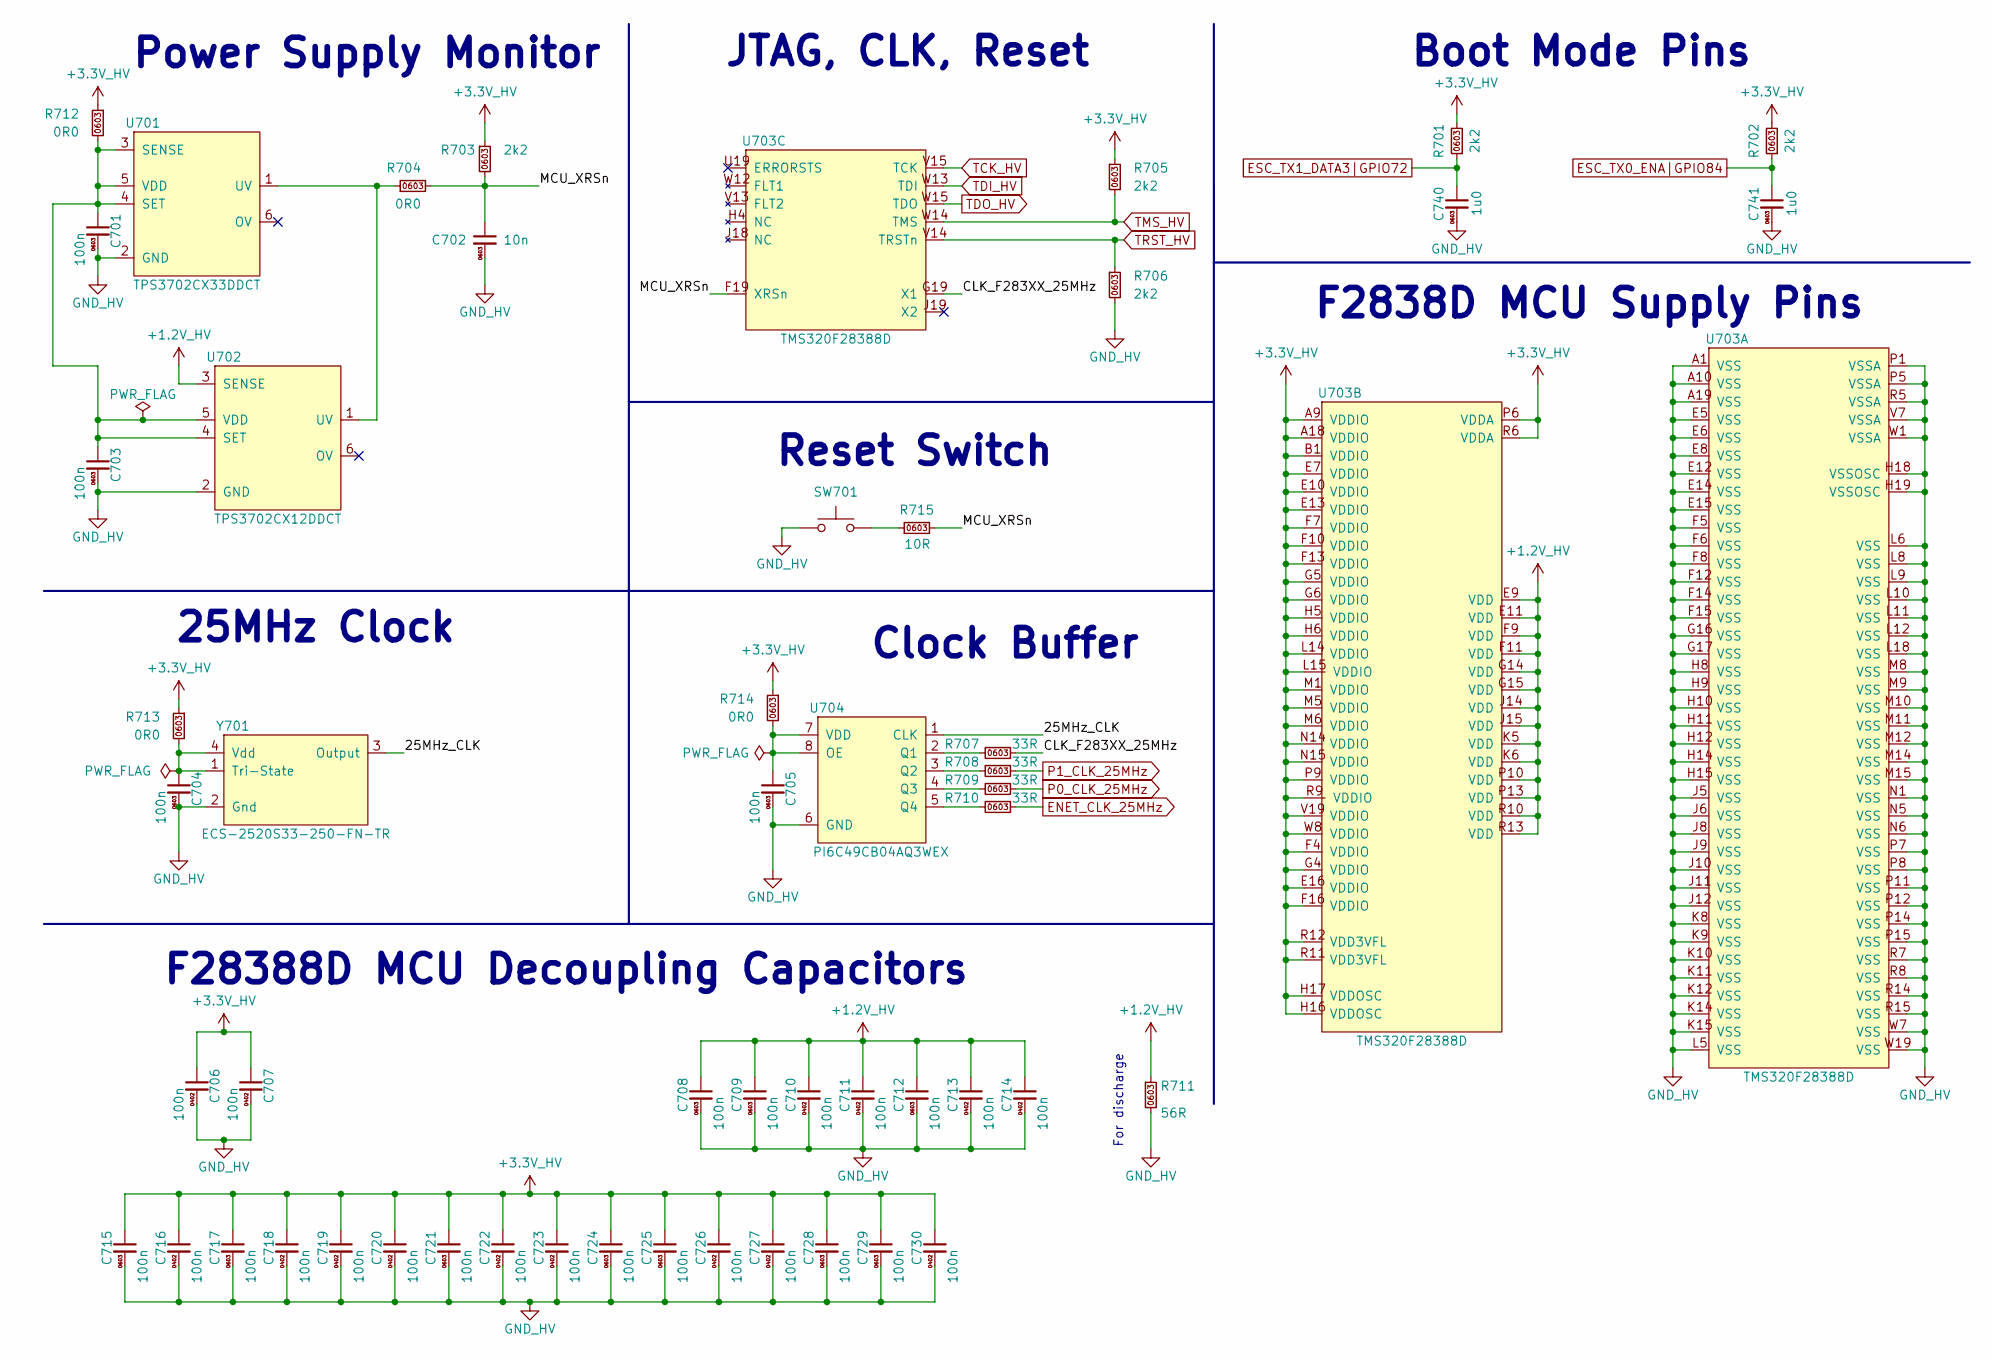
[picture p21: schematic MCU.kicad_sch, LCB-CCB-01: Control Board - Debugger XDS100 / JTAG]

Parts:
C701, C703, C704, C705, C708, C709, C712, C715, C717, C721, C724, C725, C728, C729: 100n; C_0603; mouser# 810-C1608X5R1H104K
C702: 10n; C_0603; mouser# 810-CGA3E2X7R1H103K
C706, C707, C710, C711, C713, C714, C716, C718, C719, C720, C722, C723, C726, C727, C730: 100n; C_0402; mouser# 810-C1005X7R1H104K
C740, C741: 1u0; C_0603; mouser# 810-C1608X5R1H105K
R701, R702, R703, R705, R706: 2k2; R_0603; mouser# 71-CRCW06032K20FKEAC
R704, R712, R713, R714: 0R0; R_0603; mouser# 71-CRCW06030000Z0EAC
R707, R708, R709, R710: 33R; R_0603; mouser# 71-CRCW060333R0FKEAC
R711: 56R; R_0603; mouser# 71-CRCW060356R0FKEAC
R715: 10R; R_0603; mouser# 71-CRCW060310R0FKEAC
SW701: SW_Push_RightAngle; Sw_Push_RightAngle; mouser# 653-B3U-3000PM
U701: TPS3702CX33DDCT; TSOT-23-6_TI; mouser# 595-TPS3702CX33DDCT
U702: TPS3702CX12DDCT; TSOT-23-6_TI; mouser# 595-TPS3702CX12DDCT
U703: TMS320F28388D; BGA-361_19x19_16.0x16.0mm; mouser# 595-F28388DZWTSR
U704: PI6C49CB04AQ3WEX; SOIC-8; mouser# 621-PI6C49CB04AQ3WEX
Y701: ECS-2520S33-250-FN-TR; Osc_ECS_2.5x2; mouser# 520-2520S33-250-FNT

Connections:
+1.2V_HV: C708.1, C709.1, C710.1, C711.1, C712.1, C713.1, C714.1, R711.1, U702.3 (SENSE), U703.E9 (VDD), U703.E11 (VDD), U703.F9 (VDD), U703.F11 (VDD), U703.G14 (VDD), U703.G15 (VDD), U703.J14 (VDD), U703.J15 (VDD), U703.K5 (VDD), U703.K6 (VDD), U703.P10 (VDD), U703.P13 (VDD), U703.R10 (VDD), U703.R13 (VDD); also elsewhere on the board
+3.3V_HV: C706.1, C707.1, C715.1, C716.1, C717.1, C718.1, C719.1, C720.1, C721.1, C722.1, C723.1, C724.1, C725.1, C726.1, C727.1, C728.1, C729.1, C730.1, R701.2, R702.2, R703.1, R705.1, R712.1, R713.1, R714.1, U703.A9 (VDDIO), U703.A18 (VDDIO), U703.B1 (VDDIO), U703.E7 (VDDIO), U703.E10 (VDDIO), U703.E13 (VDDIO), U703.E16 (VDDIO), U703.F4 (VDDIO), U703.F7 (VDDIO), U703.F10 (VDDIO), U703.F13 (VDDIO), U703.F16 (VDDIO), U703.G4 (VDDIO), U703.G5 (VDDIO), U703.G6 (VDDIO), U703.H5 (VDDIO), U703.H6 (VDDIO), U703.H16 (VDDOSC), U703.H17 (VDDOSC), U703.L14 (VDDIO), U703.L15 (VDDIO), U703.M1 (VDDIO), U703.M5 (VDDIO), U703.M6 (VDDIO), U703.N14 (VDDIO), U703.N15 (VDDIO), U703.P6 (VDDA), U703.P9 (VDDIO), U703.R6 (VDDA), U703.R9 (VDDIO), U703.R11 (VDD3VFL), U703.R12 (VDD3VFL), U703.V19 (VDDIO), U703.W8 (VDDIO); also elsewhere on the board
/MCU - Page 7/25MHz_CLK: U704.1 (CLK), Y701.3 (Output)
/MCU - Page 7/CLK_F283XX_25MHz: R707.1, U703.G19 (X1)
/MCU - Page 7/MCU_XRSn: C702.1, R703.2, R704.2, R715.2, U703.F19 (XRSn)
ENET_CLK_25MHz: R710.1; also elsewhere on the board
ESC_TX0_ENA|GPIO84: C741.1, R702.1; also elsewhere on the board
ESC_TX1_DATA3|GPIO72: C740.1, R701.1; also elsewhere on the board
GND_HV: C701.2, C702.2, C703.2, C704.2, C705.2, C706.2, C707.2, C708.2, C709.2, C710.2, C711.2, C712.2, C713.2, C714.2, C715.2, C716.2, C717.2, C718.2, C719.2, C720.2, C721.2, C722.2, C723.2, C724.2, C725.2, C726.2, C727.2, C728.2, C729.2, C730.2, C740.2, C741.2, R706.2, R711.2, SW701.1, U701.2 (GND), U702.2 (GND), U703.A1 (VSS), U703.A10 (VSS), U703.A19 (VSS), U703.E5 (VSS), U703.E6 (VSS), U703.E8 (VSS), U703.E12 (VSS), U703.E14 (VSS), U703.E15 (VSS), U703.F5 (VSS), U703.F6 (VSS), U703.F8 (VSS), U703.F12 (VSS), U703.F14 (VSS), U703.F15 (VSS), U703.G16 (VSS), U703.G17 (VSS), U703.H8 (VSS), U703.H9 (VSS), U703.H10 (VSS), U703.H11 (VSS), U703.H12 (VSS), U703.H14 (VSS), U703.H15 (VSS), U703.H18 (VSSOSC), U703.H19 (VSSOSC), U703.J5 (VSS), U703.J6 (VSS), U703.J8 (VSS), U703.J9 (VSS), U703.J10 (VSS), U703.J11 (VSS), U703.J12 (VSS), U703.K8 (VSS), U703.K9 (VSS), U703.K10 (VSS), U703.K11 (VSS), U703.K12 (VSS), U703.K14 (VSS), U703.K15 (VSS), U703.L5 (VSS), U703.L6 (VSS), U703.L8 (VSS), U703.L9 (VSS), U703.L10 (VSS), U703.L11 (VSS), U703.L12 (VSS), U703.L18 (VSS), U703.M8 (VSS), U703.M9 (VSS), U703.M10 (VSS), U703.M11 (VSS), U703.M12 (VSS), U703.M14 (VSS), U703.M15 (VSS), U703.N1 (VSS), U703.N5 (VSS), U703.N6 (VSS), U703.P1 (VSSA), U703.P5 (VSSA), U703.P7 (VSS), U703.P8 (VSS), U703.P11 (VSS), U703.P12 (VSS), U703.P14 (VSS), U703.P15 (VSS), U703.R5 (VSSA), U703.R7 (VSS), U703.R8 (VSS), U703.R14 (VSS), U703.R15 (VSS), U703.V7 (VSSA), U703.W1 (VSSA), U703.W7 (VSS), U703.W19 (VSS), U704.6 (GND), Y701.2 (Gnd); also elsewhere on the board
unnamed: R715.1, SW701.2
unnamed: C701.1, C703.1, R712.2, U701.3 (SENSE), U701.4 (SET), U701.5 (VDD), U702.4 (SET), U702.5 (VDD)
unnamed: R704.1, U701.1 (UV), U702.1 (UV)
unnamed: C705.1, R714.2, U704.7 (VDD), U704.8 (OE)
unnamed: R707.2, U704.2 (Q1)
unnamed: R708.2, U704.3 (Q2)
unnamed: R709.2, U704.4 (Q3)
unnamed: R710.2, U704.5 (Q4)
unnamed: C704.1, R713.2, Y701.1 (Tri-State), Y701.4 (Vdd)
P0_CLK_25MHz: R709.1; also elsewhere on the board
P1_CLK_25MHz: R708.1; also elsewhere on the board
TCK_HV: U703.V15 (TCK); also elsewhere on the board
TDI_HV: U703.W13 (TDI); also elsewhere on the board
TDO_HV: U703.W15 (TDO); also elsewhere on the board
TMS_HV: R705.2, U703.W14 (TMS); also elsewhere on the board
TRST_HV: R706.1, U703.V14 (TRSTn); also elsewhere on the board

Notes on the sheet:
Power Supply Monitor
F2838D MCU Supply Pins
Reset Switch
JTAG, CLK, Reset
F28388D MCU Decoupling Capacitors
For discharge
Clock Buffer
25MHz Clock
Boot Mode Pins

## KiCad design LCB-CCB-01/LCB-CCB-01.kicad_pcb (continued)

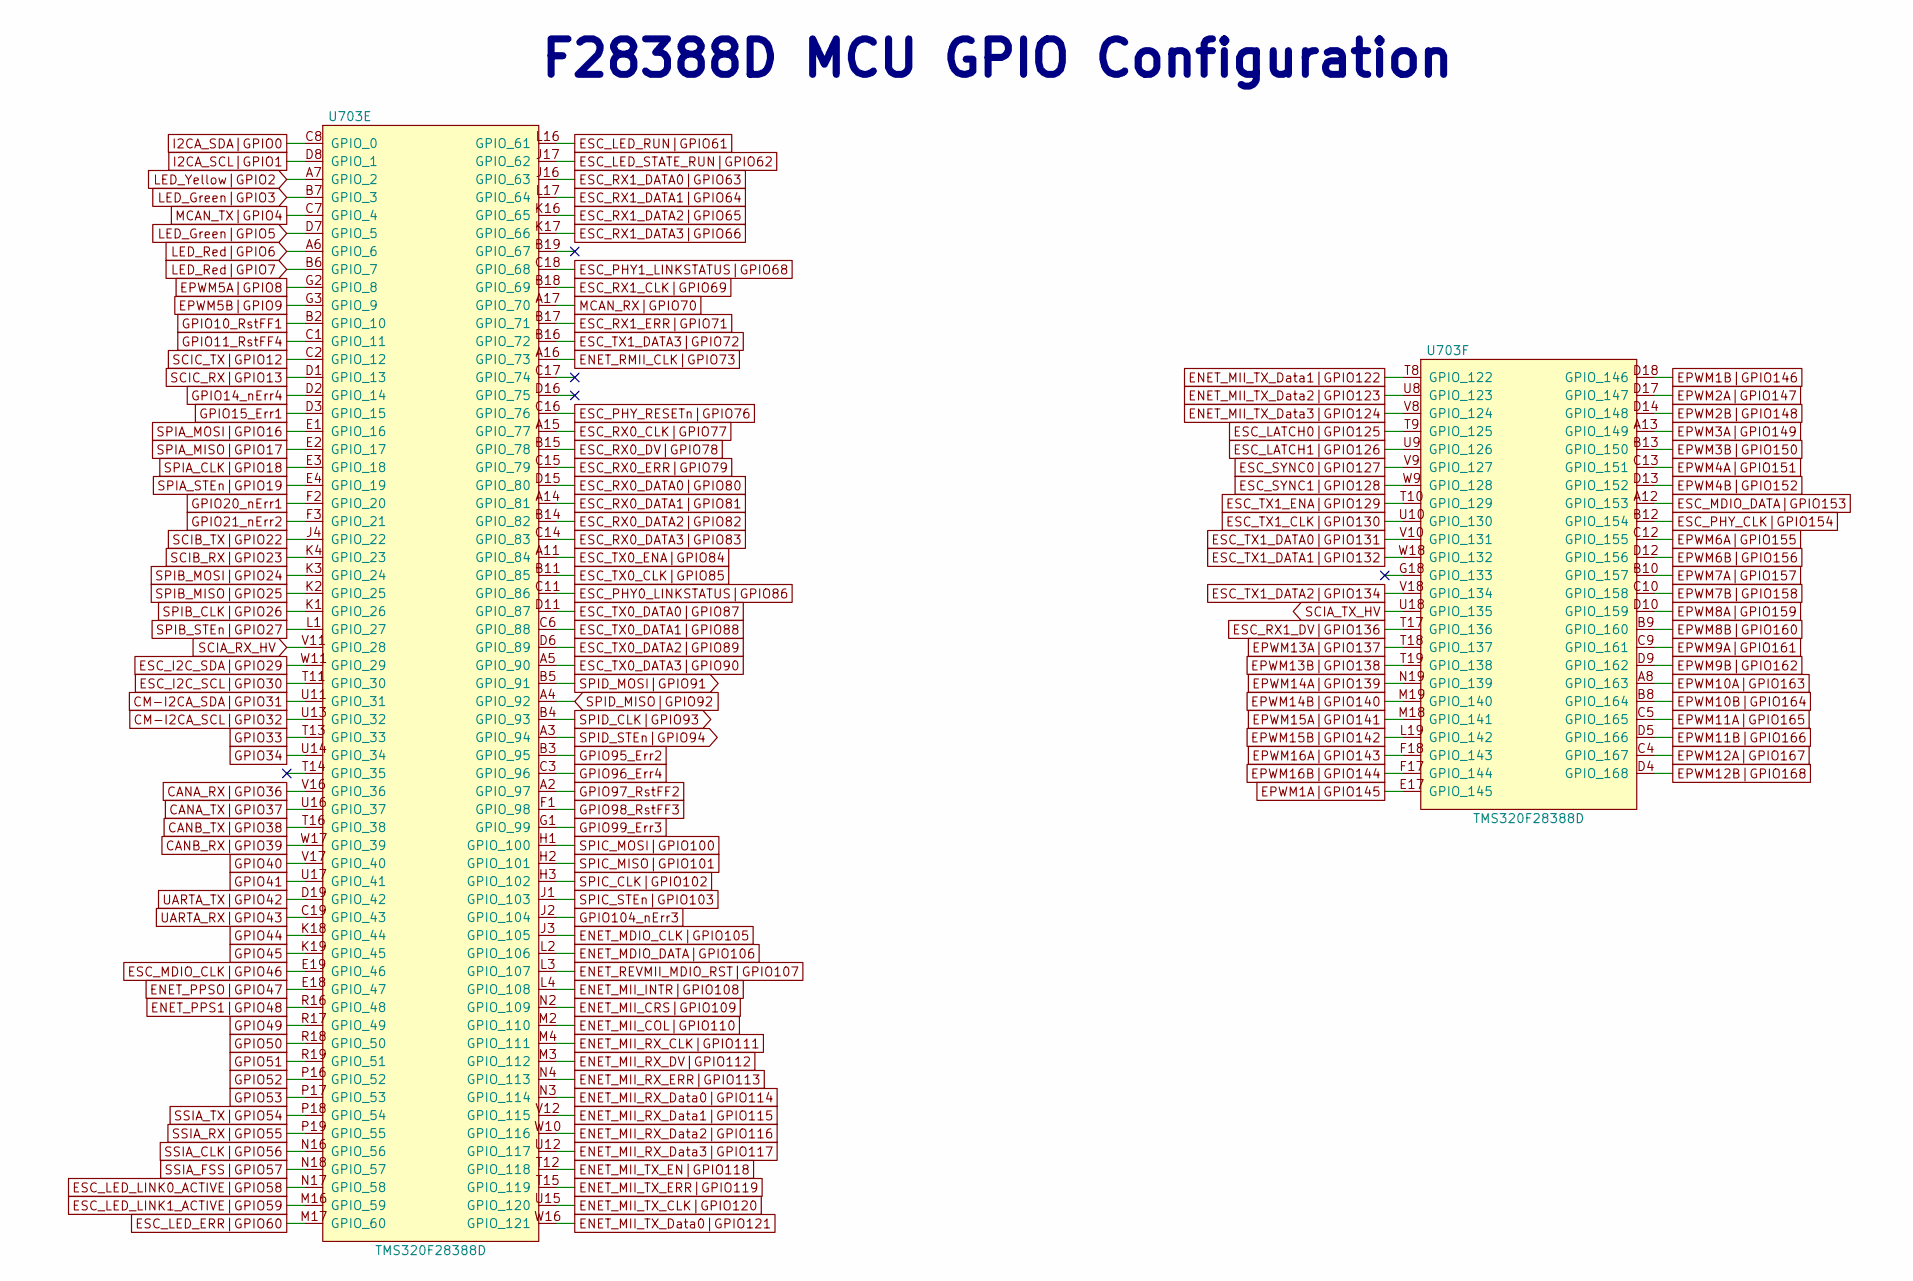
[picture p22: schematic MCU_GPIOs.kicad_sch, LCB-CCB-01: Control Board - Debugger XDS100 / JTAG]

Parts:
U703: TMS320F28388D; BGA-361_19x19_16.0x16.0mm; mouser# 595-F28388DZWTSR

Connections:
CANA_RX|GPIO36: U703.V16 (GPIO_36); also elsewhere on the board
CANA_TX|GPIO37: U703.U16 (GPIO_37); also elsewhere on the board
CANB_RX|GPIO39: U703.W17 (GPIO_39); also elsewhere on the board
CANB_TX|GPIO38: U703.T16 (GPIO_38); also elsewhere on the board
CM-I2CA_SCL|GPIO32: U703.U13 (GPIO_32); also elsewhere on the board
CM-I2CA_SDA|GPIO31: U703.U11 (GPIO_31); also elsewhere on the board
ENET_MDIO_CLK|GPIO105: U703.J3 (GPIO_105); also elsewhere on the board
ENET_MDIO_DATA|GPIO106: U703.L2 (GPIO_106); also elsewhere on the board
ENET_MII_COL|GPIO110: U703.M2 (GPIO_110); also elsewhere on the board
ENET_MII_CRS|GPIO109: U703.N2 (GPIO_109); also elsewhere on the board
ENET_MII_INTR|GPIO108: U703.L4 (GPIO_108); also elsewhere on the board
ENET_MII_RX_CLK|GPIO111: U703.M4 (GPIO_111); also elsewhere on the board
ENET_MII_RX_DV|GPIO112: U703.M3 (GPIO_112); also elsewhere on the board
ENET_MII_RX_Data0|GPIO114: U703.N3 (GPIO_114); also elsewhere on the board
ENET_MII_RX_Data1|GPIO115: U703.V12 (GPIO_115); also elsewhere on the board
ENET_MII_RX_Data2|GPIO116: U703.W10 (GPIO_116); also elsewhere on the board
ENET_MII_RX_Data3|GPIO117: U703.U12 (GPIO_117); also elsewhere on the board
ENET_MII_RX_ERR|GPIO113: U703.N4 (GPIO_113); also elsewhere on the board
ENET_MII_TX_CLK|GPIO120: U703.U15 (GPIO_120); also elsewhere on the board
ENET_MII_TX_Data0|GPIO121: U703.W16 (GPIO_121); also elsewhere on the board
ENET_MII_TX_Data1|GPIO122: U703.T8 (GPIO_122); also elsewhere on the board
ENET_MII_TX_Data2|GPIO123: U703.U8 (GPIO_123); also elsewhere on the board
ENET_MII_TX_Data3|GPIO124: U703.V8 (GPIO_124); also elsewhere on the board
ENET_MII_TX_EN|GPIO118: U703.T12 (GPIO_118); also elsewhere on the board
ENET_MII_TX_ERR|GPIO119: U703.T15 (GPIO_119); also elsewhere on the board
ENET_PPS1|GPIO48: U703.R16 (GPIO_48); also elsewhere on the board
ENET_PPSO|GPIO47: U703.E18 (GPIO_47); also elsewhere on the board
ENET_REVMII_MDIO_RST|GPIO107: U703.L3 (GPIO_107); also elsewhere on the board
ENET_RMII_CLK|GPIO73: U703.A16 (GPIO_73); also elsewhere on the board
EPWM1A|GPIO145: U703.E17 (GPIO_145); also elsewhere on the board
EPWM1B|GPIO146: U703.D18 (GPIO_146); also elsewhere on the board
EPWM2A|GPIO147: U703.D17 (GPIO_147); also elsewhere on the board
EPWM2B|GPIO148: U703.D14 (GPIO_148); also elsewhere on the board
EPWM3A|GPIO149: U703.A13 (GPIO_149); also elsewhere on the board
EPWM3B|GPIO150: U703.B13 (GPIO_150); also elsewhere on the board
EPWM4A|GPIO151: U703.C13 (GPIO_151); also elsewhere on the board
EPWM4B|GPIO152: U703.D13 (GPIO_152); also elsewhere on the board
EPWM5A|GPIO8: U703.G2 (GPIO_8); also elsewhere on the board
EPWM5B|GPIO9: U703.G3 (GPIO_9); also elsewhere on the board
EPWM6A|GPIO155: U703.C12 (GPIO_155); also elsewhere on the board
EPWM6B|GPIO156: U703.D12 (GPIO_156); also elsewhere on the board
EPWM7A|GPIO157: U703.B10 (GPIO_157); also elsewhere on the board
EPWM7B|GPIO158: U703.C10 (GPIO_158); also elsewhere on the board
EPWM8A|GPIO159: U703.D10 (GPIO_159); also elsewhere on the board
EPWM8B|GPIO160: U703.B9 (GPIO_160); also elsewhere on the board
EPWM9A|GPIO161: U703.C9 (GPIO_161); also elsewhere on the board
EPWM9B|GPIO162: U703.D9 (GPIO_162); also elsewhere on the board
EPWM10A|GPIO163: U703.A8 (GPIO_163); also elsewhere on the board
EPWM10B|GPIO164: U703.B8 (GPIO_164); also elsewhere on the board
EPWM11A|GPIO165: U703.C5 (GPIO_165); also elsewhere on the board
EPWM11B|GPIO166: U703.D5 (GPIO_166); also elsewhere on the board
EPWM12A|GPIO167: U703.C4 (GPIO_167); also elsewhere on the board
EPWM12B|GPIO168: U703.D4 (GPIO_168); also elsewhere on the board
EPWM13A|GPIO137: U703.T18 (GPIO_137); also elsewhere on the board
EPWM13B|GPIO138: U703.T19 (GPIO_138); also elsewhere on the board
EPWM14A|GPIO139: U703.N19 (GPIO_139); also elsewhere on the board
EPWM14B|GPIO140: U703.M19 (GPIO_140); also elsewhere on the board
EPWM15A|GPIO141: U703.M18 (GPIO_141); also elsewhere on the board
EPWM15B|GPIO142: U703.L19 (GPIO_142); also elsewhere on the board
EPWM16A|GPIO143: U703.F18 (GPIO_143); also elsewhere on the board
EPWM16B|GPIO144: U703.F17 (GPIO_144); also elsewhere on the board
ESC_I2C_SCL|GPIO30: U703.T11 (GPIO_30); also elsewhere on the board
ESC_I2C_SDA|GPIO29: U703.W11 (GPIO_29); also elsewhere on the board
ESC_LATCH0|GPIO125: U703.T9 (GPIO_125); also elsewhere on the board
ESC_LATCH1|GPIO126: U703.U9 (GPIO_126); also elsewhere on the board
ESC_LED_ERR|GPIO60: U703.M17 (GPIO_60); also elsewhere on the board
ESC_LED_LINK0_ACTIVE|GPIO58: U703.N17 (GPIO_58); also elsewhere on the board
ESC_LED_LINK1_ACTIVE|GPIO59: U703.M16 (GPIO_59); also elsewhere on the board
ESC_LED_RUN|GPIO61: U703.L16 (GPIO_61); also elsewhere on the board
ESC_LED_STATE_RUN|GPIO62: U703.J17 (GPIO_62); also elsewhere on the board
ESC_MDIO_CLK|GPIO46: U703.E19 (GPIO_46); also elsewhere on the board
ESC_MDIO_DATA|GPIO153: U703.A12 (GPIO_153); also elsewhere on the board
ESC_PHY0_LINKSTATUS|GPIO86: U703.C11 (GPIO_86); also elsewhere on the board
ESC_PHY1_LINKSTATUS|GPIO68: U703.C18 (GPIO_68); also elsewhere on the board
ESC_PHY_CLK|GPIO154: U703.B12 (GPIO_154); also elsewhere on the board
ESC_PHY_RESETn|GPIO76: U703.C16 (GPIO_76); also elsewhere on the board
ESC_RX0_CLK|GPIO77: U703.A15 (GPIO_77); also elsewhere on the board
ESC_RX0_DATA0|GPIO80: U703.D15 (GPIO_80); also elsewhere on the board
ESC_RX0_DATA1|GPIO81: U703.A14 (GPIO_81); also elsewhere on the board
ESC_RX0_DATA2|GPIO82: U703.B14 (GPIO_82); also elsewhere on the board
ESC_RX0_DATA3|GPIO83: U703.C14 (GPIO_83); also elsewhere on the board
ESC_RX0_DV|GPIO78: U703.B15 (GPIO_78); also elsewhere on the board
ESC_RX0_ERR|GPIO79: U703.C15 (GPIO_79); also elsewhere on the board
ESC_RX1_CLK|GPIO69: U703.B18 (GPIO_69); also elsewhere on the board
ESC_RX1_DATA0|GPIO63: U703.J16 (GPIO_63); also elsewhere on the board
ESC_RX1_DATA1|GPIO64: U703.L17 (GPIO_64); also elsewhere on the board
ESC_RX1_DATA2|GPIO65: U703.K16 (GPIO_65); also elsewhere on the board
ESC_RX1_DATA3|GPIO66: U703.K17 (GPIO_66); also elsewhere on the board
ESC_RX1_DV|GPIO136: U703.T17 (GPIO_136); also elsewhere on the board
ESC_RX1_ERR|GPIO71: U703.B17 (GPIO_71); also elsewhere on the board
ESC_SYNC0|GPIO127: U703.V9 (GPIO_127); also elsewhere on the board
ESC_SYNC1|GPIO128: U703.W9 (GPIO_128); also elsewhere on the board
ESC_TX0_CLK|GPIO85: U703.B11 (GPIO_85); also elsewhere on the board
ESC_TX0_DATA0|GPIO87: U703.D11 (GPIO_87); also elsewhere on the board
ESC_TX0_DATA1|GPIO88: U703.C6 (GPIO_88); also elsewhere on the board
ESC_TX0_DATA2|GPIO89: U703.D6 (GPIO_89); also elsewhere on the board
ESC_TX0_DATA3|GPIO90: U703.A5 (GPIO_90); also elsewhere on the board
ESC_TX0_ENA|GPIO84: U703.A11 (GPIO_84); also elsewhere on the board
ESC_TX1_CLK|GPIO130: U703.U10 (GPIO_130); also elsewhere on the board
ESC_TX1_DATA0|GPIO131: U703.V10 (GPIO_131); also elsewhere on the board
ESC_TX1_DATA1|GPIO132: U703.W18 (GPIO_132); also elsewhere on the board
ESC_TX1_DATA2|GPIO134: U703.V18 (GPIO_134); also elsewhere on the board
ESC_TX1_DATA3|GPIO72: U703.B16 (GPIO_72); also elsewhere on the board
ESC_TX1_ENA|GPIO129: U703.T10 (GPIO_129); also elsewhere on the board
GPIO10_RstFF1: U703.B2 (GPIO_10); also elsewhere on the board
GPIO11_RstFF4: U703.C1 (GPIO_11); also elsewhere on the board
GPIO14_nErr4: U703.D2 (GPIO_14); also elsewhere on the board
GPIO15_Err1: U703.D3 (GPIO_15); also elsewhere on the board
GPIO20_nErr1: U703.F2 (GPIO_20); also elsewhere on the board
GPIO21_nErr2: U703.F3 (GPIO_21); also elsewhere on the board
GPIO33: U703.T13 (GPIO_33); also elsewhere on the board
GPIO34: U703.U14 (GPIO_34); also elsewhere on the board
GPIO40: U703.V17 (GPIO_40); also elsewhere on the board
GPIO41: U703.U17 (GPIO_41); also elsewhere on the board
GPIO44: U703.K18 (GPIO_44); also elsewhere on the board
GPIO45: U703.K19 (GPIO_45); also elsewhere on the board
GPIO49: U703.R17 (GPIO_49); also elsewhere on the board
GPIO50: U703.R18 (GPIO_50); also elsewhere on the board
GPIO51: U703.R19 (GPIO_51); also elsewhere on the board
GPIO52: U703.P16 (GPIO_52); also elsewhere on the board
GPIO53: U703.P17 (GPIO_53); also elsewhere on the board
GPIO95_Err2: U703.B3 (GPIO_95); also elsewhere on the board
GPIO96_Err4: U703.C3 (GPIO_96); also elsewhere on the board
GPIO97_RstFF2: U703.A2 (GPIO_97); also elsewhere on the board
GPIO98_RstFF3: U703.F1 (GPIO_98); also elsewhere on the board
GPIO99_Err3: U703.G1 (GPIO_99); also elsewhere on the board
GPIO104_nErr3: U703.J2 (GPIO_104); also elsewhere on the board
I2CA_SCL|GPIO1: U703.D8 (GPIO_1); also elsewhere on the board
I2CA_SDA|GPIO0: U703.C8 (GPIO_0); also elsewhere on the board
LED_Green|GPIO3: U703.B7 (GPIO_3); also elsewhere on the board
LED_Green|GPIO5: U703.D7 (GPIO_5); also elsewhere on the board
LED_Red|GPIO6: U703.A6 (GPIO_6); also elsewhere on the board
LED_Red|GPIO7: U703.B6 (GPIO_7); also elsewhere on the board
LED_Yellow|GPIO2: U703.A7 (GPIO_2); also elsewhere on the board
MCAN_RX|GPIO70: U703.A17 (GPIO_70); also elsewhere on the board
MCAN_TX|GPIO4: U703.C7 (GPIO_4); also elsewhere on the board
SCIA_RX_HV: U703.V11 (GPIO_28); also elsewhere on the board
SCIA_TX_HV: U703.U18 (GPIO_135); also elsewhere on the board
SCIB_RX|GPIO23: U703.K4 (GPIO_23); also elsewhere on the board
SCIB_TX|GPIO22: U703.J4 (GPIO_22); also elsewhere on the board
SCIC_RX|GPIO13: U703.D1 (GPIO_13); also elsewhere on the board
SCIC_TX|GPIO12: U703.C2 (GPIO_12); also elsewhere on the board
SPIA_CLK|GPIO18: U703.E3 (GPIO_18); also elsewhere on the board
SPIA_MISO|GPIO17: U703.E2 (GPIO_17); also elsewhere on the board
SPIA_MOSI|GPIO16: U703.E1 (GPIO_16); also elsewhere on the board
SPIA_STEn|GPIO19: U703.E4 (GPIO_19); also elsewhere on the board
SPIB_CLK|GPIO26: U703.K1 (GPIO_26); also elsewhere on the board
SPIB_MISO|GPIO25: U703.K2 (GPIO_25); also elsewhere on the board
SPIB_MOSI|GPIO24: U703.K3 (GPIO_24); also elsewhere on the board
SPIB_STEn|GPIO27: U703.L1 (GPIO_27); also elsewhere on the board
SPIC_CLK|GPIO102: U703.H3 (GPIO_102); also elsewhere on the board
SPIC_MISO|GPIO101: U703.H2 (GPIO_101); also elsewhere on the board
SPIC_MOSI|GPIO100: U703.H1 (GPIO_100); also elsewhere on the board
SPIC_STEn|GPIO103: U703.J1 (GPIO_103); also elsewhere on the board
SPID_CLK|GPIO93: U703.B4 (GPIO_93); also elsewhere on the board
SPID_MISO|GPIO92: U703.A4 (GPIO_92); also elsewhere on the board
SPID_MOSI|GPIO91: U703.B5 (GPIO_91); also elsewhere on the board
SPID_STEn|GPIO94: U703.A3 (GPIO_94); also elsewhere on the board
SSIA_CLK|GPIO56: U703.N16 (GPIO_56); also elsewhere on the board
SSIA_FSS|GPIO57: U703.N18 (GPIO_57); also elsewhere on the board
SSIA_RX|GPIO55: U703.P19 (GPIO_55); also elsewhere on the board
SSIA_TX|GPIO54: U703.P18 (GPIO_54); also elsewhere on the board
UARTA_RX|GPIO43: U703.C19 (GPIO_43); also elsewhere on the board
UARTA_TX|GPIO42: U703.D19 (GPIO_42); also elsewhere on the board

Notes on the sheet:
F28388D MCU GPIO Configuration

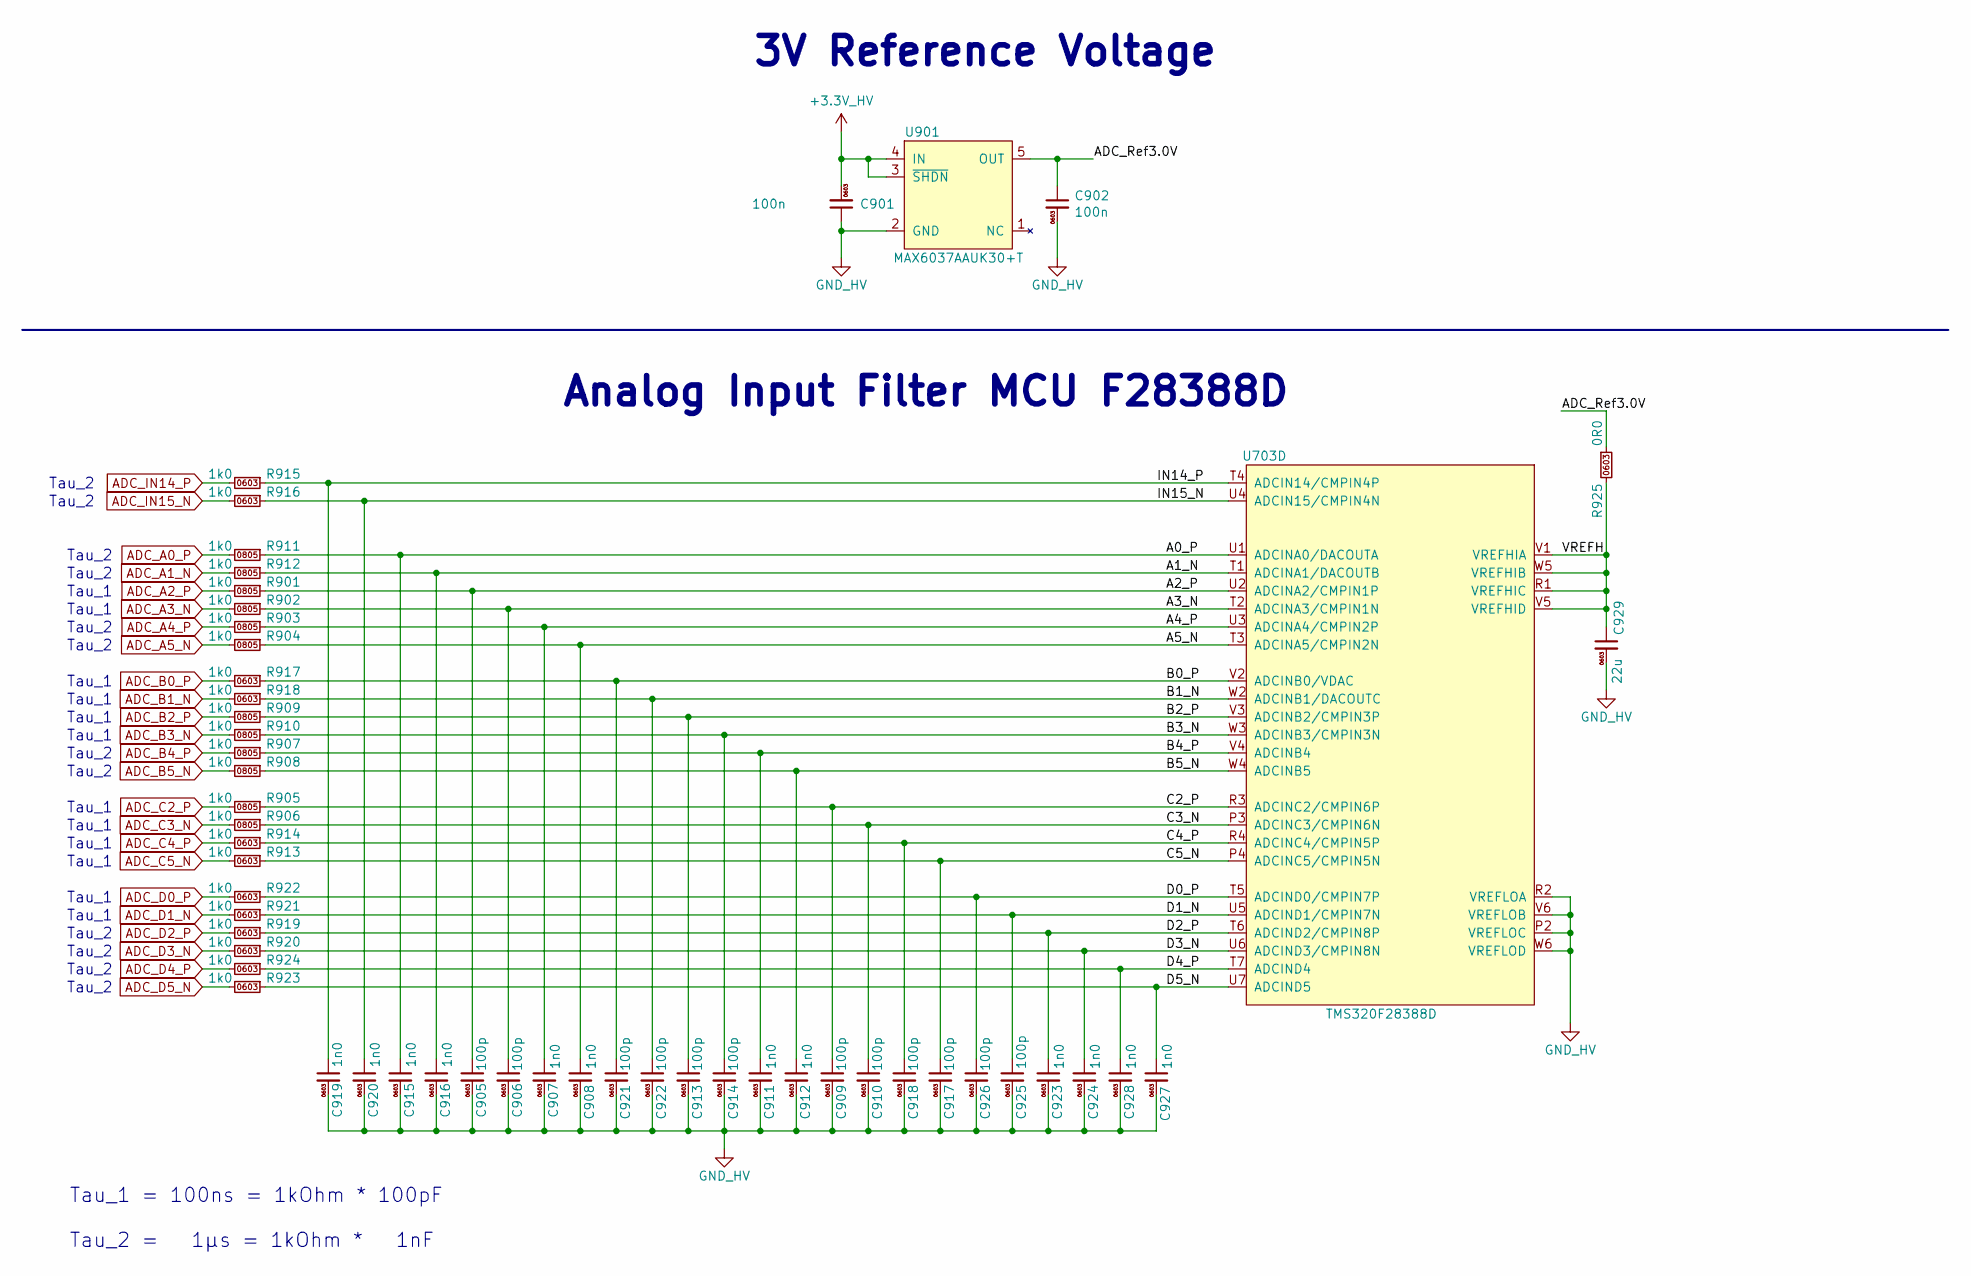
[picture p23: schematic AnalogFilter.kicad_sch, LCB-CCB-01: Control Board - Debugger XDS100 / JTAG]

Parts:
C901, C902: 100n; C_0603; mouser# 810-C1608X5R1H104K
C905, C906, C909, C910, C913, C914, C917, C918, C921, C922, C925, C926: 100p; C_0603; mouser# 810-C1608C0G1H101KAA
C907, C908, C911, C912, C915, C916, C919, C920, C923, C924, C927, C928: 1n0; C_0603; mouser# 810-C1608X7R1H102KAE
C929: 22u; C_0603; mouser# 187-CL10A226KQ8NRNE
R901, R902, R903, R904, R905, R906, R907, R908, R909, R910, R911, R912: 1k0; R_0805; mouser# 71-CRCW08051K00FKEAC
R913, R914, R915, R916, R917, R918, R919, R920, R921, R922, R923, R924: 1k0; R_0603; mouser# 71-CRCW06031K00FKEAC
R925: 0R0; R_0603; mouser# 71-CRCW06030000Z0EAC
U703: TMS320F28388D; BGA-361_19x19_16.0x16.0mm; mouser# 595-F28388DZWTSR
U901: MAX6037AAUK30+T; SOT-23-5_Microchip; mouser# 700-MAX6037AAUK30T

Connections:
+3.3V_HV: C901.2, U901.3 (~SHDN), U901.4 (IN); also elsewhere on the board
/Analog Filter - Page 9/A0_P: C915.1, R911.1, U703.U1 (ADCINA0/DACOUTA)
/Analog Filter - Page 9/A1_N: C916.1, R912.1, U703.T1 (ADCINA1/DACOUTB)
/Analog Filter - Page 9/A2_P: C905.1, R901.1, U703.U2 (ADCINA2/CMPIN1P)
/Analog Filter - Page 9/A3_N: C906.1, R902.1, U703.T2 (ADCINA3/CMPIN1N)
/Analog Filter - Page 9/A4_P: C907.1, R903.1, U703.U3 (ADCINA4/CMPIN2P)
/Analog Filter - Page 9/A5_N: C908.1, R904.1, U703.T3 (ADCINA5/CMPIN2N)
/Analog Filter - Page 9/ADC_Ref3.0V: C902.1, R925.1, U901.5 (OUT)
/Analog Filter - Page 9/B0_P: C921.1, R917.1, U703.V2 (ADCINB0/VDAC)
/Analog Filter - Page 9/B1_N: C922.1, R918.1, U703.W2 (ADCINB1/DACOUTC)
/Analog Filter - Page 9/B2_P: C913.1, R909.1, U703.V3 (ADCINB2/CMPIN3P)
/Analog Filter - Page 9/B3_N: C914.1, R910.1, U703.W3 (ADCINB3/CMPIN3N)
/Analog Filter - Page 9/B4_P: C911.1, R907.1, U703.V4 (ADCINB4)
/Analog Filter - Page 9/B5_N: C912.1, R908.1, U703.W4 (ADCINB5)
/Analog Filter - Page 9/C2_P: C909.1, R905.1, U703.R3 (ADCINC2/CMPIN6P)
/Analog Filter - Page 9/C3_N: C910.1, R906.1, U703.P3 (ADCINC3/CMPIN6N)
/Analog Filter - Page 9/C4_P: C918.1, R914.1, U703.R4 (ADCINC4/CMPIN5P)
/Analog Filter - Page 9/C5_N: C917.1, R913.1, U703.P4 (ADCINC5/CMPIN5N)
/Analog Filter - Page 9/D0_P: C926.1, R922.1, U703.T5 (ADCIND0/CMPIN7P)
/Analog Filter - Page 9/D1_N: C925.1, R921.1, U703.U5 (ADCIND1/CMPIN7N)
/Analog Filter - Page 9/D2_P: C923.1, R919.1, U703.T6 (ADCIND2/CMPIN8P)
/Analog Filter - Page 9/D3_N: C924.1, R920.1, U703.U6 (ADCIND3/CMPIN8N)
/Analog Filter - Page 9/D4_P: C928.1, R924.1, U703.T7 (ADCIND4)
/Analog Filter - Page 9/D5_N: C927.1, R923.1, U703.U7 (ADCIND5)
/Analog Filter - Page 9/IN14_P: C919.1, R915.1, U703.T4 (ADCIN14/CMPIN4P)
/Analog Filter - Page 9/IN15_N: C920.1, R916.1, U703.U4 (ADCIN15/CMPIN4N)
/Analog Filter - Page 9/VREFH: C929.1, R925.2, U703.R1 (VREFHIC), U703.V1 (VREFHIA), U703.V5 (VREFHID), U703.W5 (VREFHIB)
ADC_A0_P: R911.2; also elsewhere on the board
ADC_A1_N: R912.2; also elsewhere on the board
ADC_A2_P: R901.2; also elsewhere on the board
ADC_A3_N: R902.2; also elsewhere on the board
ADC_A4_P: R903.2; also elsewhere on the board
ADC_A5_N: R904.2; also elsewhere on the board
ADC_B0_P: R917.2; also elsewhere on the board
ADC_B1_N: R918.2; also elsewhere on the board
ADC_B2_P: R909.2; also elsewhere on the board
ADC_B3_N: R910.2; also elsewhere on the board
ADC_B4_P: R907.2; also elsewhere on the board
ADC_B5_N: R908.2; also elsewhere on the board
ADC_C2_P: R905.2; also elsewhere on the board
ADC_C3_N: R906.2; also elsewhere on the board
ADC_C4_P: R914.2; also elsewhere on the board
ADC_C5_N: R913.2; also elsewhere on the board
ADC_D0_P: R922.2; also elsewhere on the board
ADC_D1_N: R921.2; also elsewhere on the board
ADC_D2_P: R919.2; also elsewhere on the board
ADC_D3_N: R920.2; also elsewhere on the board
ADC_D4_P: R924.2; also elsewhere on the board
ADC_D5_N: R923.2; also elsewhere on the board
ADC_IN14_P: R915.2; also elsewhere on the board
ADC_IN15_N: R916.2; also elsewhere on the board
GND_HV: C901.1, C902.2, C905.2, C906.2, C907.2, C908.2, C909.2, C910.2, C911.2, C912.2, C913.2, C914.2, C915.2, C916.2, C917.2, C918.2, C919.2, C920.2, C921.2, C922.2, C923.2, C924.2, C925.2, C926.2, C927.2, C928.2, C929.2, U703.P2 (VREFLOC), U703.R2 (VREFLOA), U703.V6 (VREFLOB), U703.W6 (VREFLOD), U901.2 (GND); also elsewhere on the board

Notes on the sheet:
Analog Input Filter MCU F28388D
3V Reference Voltage
Tau_2
Tau_1
Tau_1 = 100ns = 1kOhm * 100pF
Tau_2 = 1µs = 1kOhm * 1nF

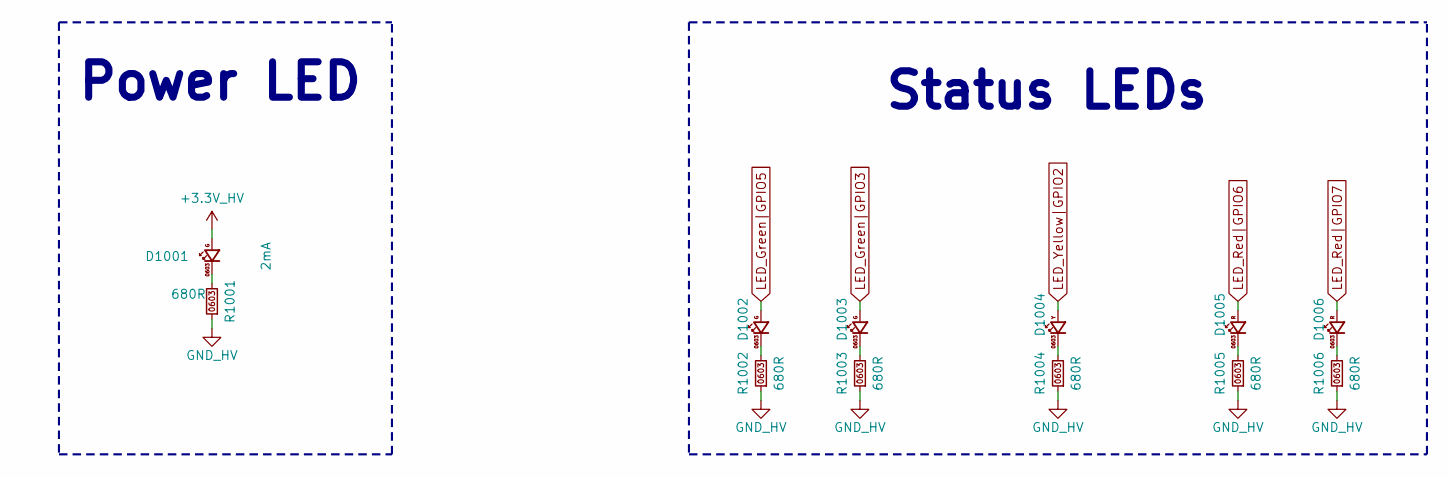
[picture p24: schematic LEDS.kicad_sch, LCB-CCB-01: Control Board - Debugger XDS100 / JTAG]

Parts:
D1001, D1002, D1003: 2mA; LED_0603_G; mouser# 604-APTD1608LCGCK
D1004: 2mA; LED_0603_Y; mouser# 604-APTD1608LSYCK
D1005, D1006: 2mA; LED_0603_R; mouser# 604-APHD1608LSURCK
R1001, R1002, R1003, R1004, R1005, R1006: 680R; R_0603; mouser# 71-CRCW0603680RFKEAC

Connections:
+3.3V_HV: D1001.A; also elsewhere on the board
GND_HV: R1001.1, R1002.1, R1003.1, R1004.1, R1005.1, R1006.1; also elsewhere on the board
LED_Green|GPIO3: D1003.A; also elsewhere on the board
LED_Green|GPIO5: D1002.A; also elsewhere on the board
LED_Red|GPIO6: D1005.A; also elsewhere on the board
LED_Red|GPIO7: D1006.A; also elsewhere on the board
LED_Yellow|GPIO2: D1004.A; also elsewhere on the board
unnamed: D1001.C, R1001.2
unnamed: D1002.C, R1002.2
unnamed: D1003.C, R1003.2
unnamed: D1004.C, R1004.2
unnamed: D1005.C, R1005.2
unnamed: D1006.C, R1006.2

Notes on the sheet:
Status LEDs
Power LED

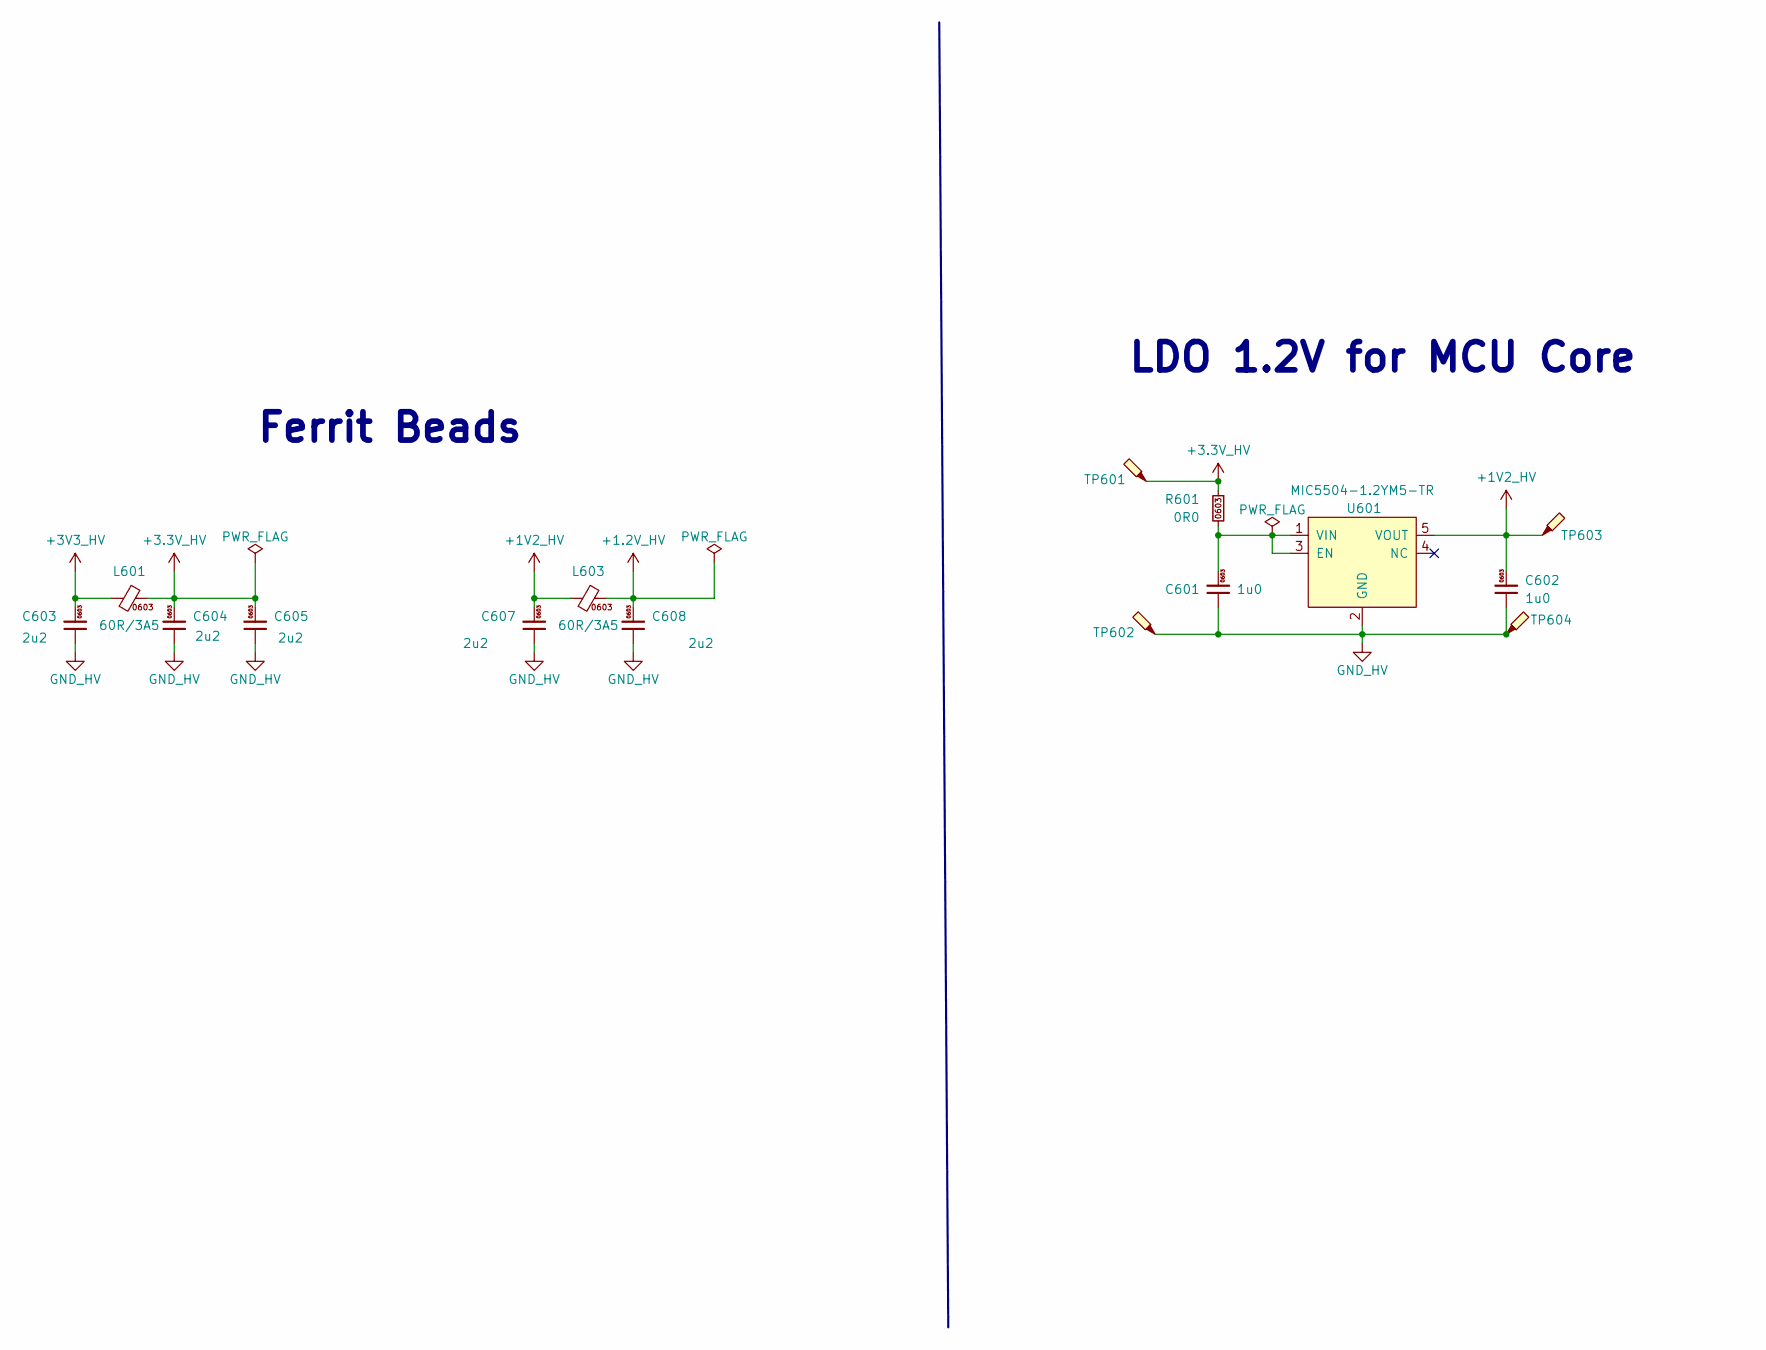
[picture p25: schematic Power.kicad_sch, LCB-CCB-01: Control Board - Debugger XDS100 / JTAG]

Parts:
C601, C602: 1u0; C_0603; mouser# 810-C1608X5R1H105K
C603, C604, C605, C607, C608: 2u2; C_0603; mouser# 810-C1608X5R1V225K
L601, L603: 60R/3A5; L_0603; mouser# 810-MPZ1608S600ATAH0
R601: 0R0; R_0603; mouser# 71-CRCW06030000Z0EAC
TP601, TP602, TP603, TP604: TestPoint_Probe; TestPoint_Pad_D1.0mm
U601: MIC5504-1.2YM5-TR; SOT-23-5_Microchip; mouser# 998-MIC5504-1.2YM5TR

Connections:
+1.2V_HV: C608.2, L603.1; also elsewhere on the board
+1V2_HV: C602.2, C607.2, L603.2, TP603.1, U601.5 (VOUT)
+3.3V_HV: C604.2, C605.2, L601.1, R601.1, TP601.1; also elsewhere on the board
+3V3_Connector_HV: C603.2, L601.2; also elsewhere on the board
GND_HV: C601.1, C602.1, C603.1, C604.1, C605.1, C607.1, C608.1, TP602.1, TP604.1, U601.2 (GND); also elsewhere on the board
unnamed: C601.2, R601.2, U601.1 (VIN), U601.3 (EN)

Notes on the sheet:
LDO 1.2V for MCU Core
Ferrit Beads

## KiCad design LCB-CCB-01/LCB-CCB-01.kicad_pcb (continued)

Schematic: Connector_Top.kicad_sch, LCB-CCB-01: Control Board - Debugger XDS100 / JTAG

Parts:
J401: Molex_532617006; 6-PinHeader_Molex_532617006; mouser# 538-53261-7006
J402, J403: ERF5-075-05.0-L-DV-TR; ERF5-075-05.0-L-DV; mouser# 200-ERF507505.0LDVTR

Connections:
+3.3V_HV: J401.6; also elsewhere on the board
+3V3_Connector_HV: J402.1, J402.2, J402.3, J402.4, J402.5, J402.6, J402.7, J402.8, J402.9, J402.10; also elsewhere on the board
ADC_A0_P: J402.118; also elsewhere on the board
ADC_A1_N: J402.116; also elsewhere on the board
ADC_A2_P: J402.123; also elsewhere on the board
ADC_A3_N: J402.121; also elsewhere on the board
ADC_A4_P: J402.124; also elsewhere on the board
ADC_A5_N: J402.122; also elsewhere on the board
ADC_B0_P: J402.129; also elsewhere on the board
ADC_B1_N: J402.127; also elsewhere on the board
ADC_B2_P: J402.130; also elsewhere on the board
ADC_B3_N: J402.128; also elsewhere on the board
ADC_B4_P: J402.135; also elsewhere on the board
ADC_B5_N: J402.133; also elsewhere on the board
ADC_C2_P: J402.136; also elsewhere on the board
ADC_C3_N: J402.134; also elsewhere on the board
ADC_C4_P: J402.141; also elsewhere on the board
ADC_C5_N: J402.139; also elsewhere on the board
ADC_D0_P: J402.142; also elsewhere on the board
ADC_D1_N: J402.140; also elsewhere on the board
ADC_D2_P: J402.147; also elsewhere on the board
ADC_D3_N: J402.145; also elsewhere on the board
ADC_D4_P: J402.148; also elsewhere on the board
ADC_D5_N: J402.146; also elsewhere on the board
ADC_IN14_P: J402.117; also elsewhere on the board
ADC_IN15_N: J402.115; also elsewhere on the board
CANA_RX|GPIO36: J403.141; also elsewhere on the board
CANA_TX|GPIO37: J403.142; also elsewhere on the board
CANB_RX|GPIO39: J403.137; also elsewhere on the board
CANB_TX|GPIO38: J403.138; also elsewhere on the board
CM-I2CA_SCL|GPIO32: J403.144; also elsewhere on the board
CM-I2CA_SDA|GPIO31: J403.143; also elsewhere on the board
ENET_CLK_25MHz: J402.91; also elsewhere on the board
ENET_MDIO_CLK|GPIO105: J402.61; also elsewhere on the board
ENET_MDIO_DATA|GPIO106: J402.67; also elsewhere on the board
ENET_MII_COL|GPIO110: J402.69; also elsewhere on the board
ENET_MII_CRS|GPIO109: J402.73; also elsewhere on the board
ENET_MII_INTR|GPIO108: J402.63; also elsewhere on the board
ENET_MII_RX_CLK|GPIO111: J402.75; also elsewhere on the board
ENET_MII_RX_DV|GPIO112: J402.70; also elsewhere on the board
ENET_MII_RX_Data0|GPIO114: J402.76; also elsewhere on the board
ENET_MII_RX_Data1|GPIO115: J402.87; also elsewhere on the board
ENET_MII_RX_Data2|GPIO116: J402.92; also elsewhere on the board
ENET_MII_RX_Data3|GPIO117: J402.88; also elsewhere on the board
ENET_MII_RX_ERR|GPIO113: J402.79; also elsewhere on the board
ENET_MII_TX_CLK|GPIO120: J402.86; also elsewhere on the board
ENET_MII_TX_Data0|GPIO121: J402.90; also elsewhere on the board
ENET_MII_TX_Data1|GPIO122: J402.80; also elsewhere on the board
ENET_MII_TX_Data2|GPIO123: J402.85; also elsewhere on the board
ENET_MII_TX_Data3|GPIO124: J402.89; also elsewhere on the board
ENET_MII_TX_EN|GPIO118: J402.81; also elsewhere on the board
ENET_MII_TX_ERR|GPIO119: J402.82; also elsewhere on the board
ENET_PPS1|GPIO48: J402.74; also elsewhere on the board
ENET_PPSO|GPIO47: J402.64; also elsewhere on the board
ENET_REVMII_MDIO_RST|GPIO107: J402.68; also elsewhere on the board
ENET_RMII_CLK|GPIO73: J402.62; also elsewhere on the board
EPWM1A|GPIO145: J403.3; also elsewhere on the board
EPWM1B|GPIO146: J403.4; also elsewhere on the board
EPWM2A|GPIO147: J403.5; also elsewhere on the board
EPWM2B|GPIO148: J403.6; also elsewhere on the board
EPWM3A|GPIO149: J403.9; also elsewhere on the board
EPWM3B|GPIO150: J403.10; also elsewhere on the board
EPWM4A|GPIO151: J403.11; also elsewhere on the board
EPWM4B|GPIO152: J403.12; also elsewhere on the board
EPWM5A|GPIO8: J403.15; also elsewhere on the board
EPWM5B|GPIO9: J403.16; also elsewhere on the board
EPWM6A|GPIO155: J403.17; also elsewhere on the board
EPWM6B|GPIO156: J403.18; also elsewhere on the board
EPWM7A|GPIO157: J403.21; also elsewhere on the board
EPWM7B|GPIO158: J403.22; also elsewhere on the board
EPWM8A|GPIO159: J403.23; also elsewhere on the board
EPWM8B|GPIO160: J403.24; also elsewhere on the board
EPWM9A|GPIO161: J403.27; also elsewhere on the board
EPWM9B|GPIO162: J403.28; also elsewhere on the board
EPWM10A|GPIO163: J403.29; also elsewhere on the board
EPWM10B|GPIO164: J403.30; also elsewhere on the board
EPWM11A|GPIO165: J403.33; also elsewhere on the board
EPWM11B|GPIO166: J403.34; also elsewhere on the board
EPWM12A|GPIO167: J403.35; also elsewhere on the board
EPWM12B|GPIO168: J403.36; also elsewhere on the board
EPWM13A|GPIO137: J403.39; also elsewhere on the board
EPWM13B|GPIO138: J403.40; also elsewhere on the board
EPWM14A|GPIO139: J403.41; also elsewhere on the board
EPWM14B|GPIO140: J403.42; also elsewhere on the board
EPWM15A|GPIO141: J403.45; also elsewhere on the board
EPWM15B|GPIO142: J403.46; also elsewhere on the board
EPWM16A|GPIO143: J403.47; also elsewhere on the board
EPWM16B|GPIO144: J403.48; also elsewhere on the board
ESC_I2C_SCL|GPIO30: J403.106; also elsewhere on the board
ESC_I2C_SDA|GPIO29: J403.108; also elsewhere on the board
ESC_LATCH0|GPIO125: J403.107; also elsewhere on the board
ESC_LATCH1|GPIO126: J403.111; also elsewhere on the board
ESC_LED_ERR|GPIO60: J403.95; also elsewhere on the board
ESC_LED_LINK0_ACTIVE|GPIO58: J403.100; also elsewhere on the board
ESC_LED_LINK1_ACTIVE|GPIO59: J403.96; also elsewhere on the board
ESC_LED_RUN|GPIO61: J403.90; also elsewhere on the board
ESC_LED_STATE_RUN|GPIO62: J403.83; also elsewhere on the board
ESC_MDIO_CLK|GPIO46: J403.58; also elsewhere on the board
ESC_MDIO_DATA|GPIO153: J403.70; also elsewhere on the board
ESC_PHY0_LINKSTATUS|GPIO86: J403.69; also elsewhere on the board
ESC_PHY1_LINKSTATUS|GPIO68: J403.82; also elsewhere on the board
ESC_PHY_CLK|GPIO154: J403.65; also elsewhere on the board
ESC_PHY_RESETn|GPIO76: J403.84; also elsewhere on the board
ESC_RX0_CLK|GPIO77: J403.72; also elsewhere on the board
ESC_RX0_DATA0|GPIO80: J403.63; also elsewhere on the board
ESC_RX0_DATA1|GPIO81: J403.64; also elsewhere on the board
ESC_RX0_DATA2|GPIO82: J403.59; also elsewhere on the board
ESC_RX0_DATA3|GPIO83: J403.66; also elsewhere on the board
ESC_RX0_DV|GPIO78: J403.81; also elsewhere on the board
ESC_RX0_ERR|GPIO79: J403.88; also elsewhere on the board
ESC_RX1_CLK|GPIO69: J403.76; also elsewhere on the board
ESC_RX1_DATA0|GPIO63: J403.87; also elsewhere on the board
ESC_RX1_DATA1|GPIO64: J403.93; also elsewhere on the board
ESC_RX1_DATA2|GPIO65: J403.94; also elsewhere on the board
ESC_RX1_DATA3|GPIO66: J403.89; also elsewhere on the board
ESC_RX1_DV|GPIO136: J403.99; also elsewhere on the board
ESC_RX1_ERR|GPIO71: J403.75; also elsewhere on the board
ESC_SYNC0|GPIO127: J403.112; also elsewhere on the board
ESC_SYNC1|GPIO128: J403.113; also elsewhere on the board
ESC_TX0_CLK|GPIO85: J403.78; also elsewhere on the board
ESC_TX0_DATA0|GPIO87: J403.71; also elsewhere on the board
ESC_TX0_DATA1|GPIO88: J403.54; also elsewhere on the board
ESC_TX0_DATA2|GPIO89: J403.53; also elsewhere on the board
ESC_TX0_DATA3|GPIO90: J403.57; also elsewhere on the board
ESC_TX0_ENA|GPIO84: J403.60; also elsewhere on the board
ESC_TX1_CLK|GPIO130: J403.117; also elsewhere on the board
ESC_TX1_DATA0|GPIO131: J403.105; also elsewhere on the board
ESC_TX1_DATA1|GPIO132: J403.101; also elsewhere on the board
ESC_TX1_DATA2|GPIO134: J403.102; also elsewhere on the board
ESC_TX1_DATA3|GPIO72: J403.77; also elsewhere on the board
ESC_TX1_ENA|GPIO129: J403.114; also elsewhere on the board
FreePin1: J402.15; also elsewhere on the board
FreePin3: J402.95; also elsewhere on the board
FreePin4: J402.96; also elsewhere on the board
FreePin5: J402.97; also elsewhere on the board
FreePin6: J402.98; also elsewhere on the board
FreePin7: J402.101; also elsewhere on the board
FreePin8: J402.102; also elsewhere on the board
GND_HV: J401.1, J402.11, J402.12, J402.13, J402.14, J402.19, J402.20, J402.25, J402.26, J402.31, J402.32, J402.37, J402.38, J402.43, J402.44, J402.53, J402.54, J402.59, J402.60, J402.65, J402.66, J402.71, J402.72, J402.77, J402.78, J402.83, J402.84, J402.93, J402.94, J402.99, J402.100, J402.103, J402.104, J402.105, J402.106, J402.113, J402.114, J402.119, J402.120, J402.125, J402.126, J402.131, J402.132, J402.137, J402.138, J402.143, J402.144, J402.149, J402.150, J403.1, J403.2, J403.7, J403.8, J403.13, J403.14, J403.19, J403.20, J403.25, J403.26, J403.31, J403.32, J403.37, J403.38, J403.43, J403.44, J403.49, J403.50, J403.55, J403.56, J403.61, J403.62, J403.67, J403.68, J403.73, J403.74, J403.79, J403.80, J403.85, J403.86, J403.91, J403.92, J403.97, J403.98, J403.103, J403.104, J403.109, J403.110, J403.115, J403.116, J403.121, J403.122, J403.127, J403.128, J403.133, J403.134, J403.139, J403.140, J403.145, J403.146, J403.149, J403.150; also elsewhere on the board
GPIO14_nErr4: J402.55; also elsewhere on the board
GPIO15_Err1: J402.48; also elsewhere on the board
GPIO20_nErr1: J402.47; also elsewhere on the board
GPIO21_nErr2: J402.49; also elsewhere on the board
GPIO33: J402.57; also elsewhere on the board
GPIO34: J402.58; also elsewhere on the board
GPIO40: J403.132; also elsewhere on the board
GPIO41: J403.120; also elsewhere on the board
GPIO44: J403.119; also elsewhere on the board
GPIO45: J403.118; also elsewhere on the board
GPIO49: J403.135; also elsewhere on the board
GPIO50: J403.136; also elsewhere on the board
GPIO51: J403.131; also elsewhere on the board
GPIO52: J403.129; also elsewhere on the board
GPIO53: J403.130; also elsewhere on the board
GPIO95_Err2: J402.50; also elsewhere on the board
GPIO96_Err4: J402.56; also elsewhere on the board
GPIO99_Err3: J402.52; also elsewhere on the board
GPIO104_nErr3: J402.51; also elsewhere on the board
I2CA_SCL|GPIO1: J402.21; also elsewhere on the board
I2CA_SDA|GPIO0: J402.22; also elsewhere on the board
MCAN_RX|GPIO70: J402.17; also elsewhere on the board
MCAN_TX|GPIO4: J402.18; also elsewhere on the board
P0_CLK_25MHz: J403.148; also elsewhere on the board
P1_CLK_25MHz: J403.147; also elsewhere on the board
SCIB_RX|GPIO23: J402.46; also elsewhere on the board
SCIB_TX|GPIO22: J402.45; also elsewhere on the board
SCIC_RX|GPIO13: J402.24; also elsewhere on the board
SCIC_TX|GPIO12: J402.23; also elsewhere on the board
SPIA_CLK|GPIO18: J402.30; also elsewhere on the board
SPIA_MISO|GPIO17: J402.28; also elsewhere on the board
SPIA_MOSI|GPIO16: J402.27; also elsewhere on the board
SPIA_STEn|GPIO19: J402.29; also elsewhere on the board
SPIB_CLK|GPIO26: J402.42; also elsewhere on the board
SPIB_MISO|GPIO25: J402.40; also elsewhere on the board
SPIB_MOSI|GPIO24: J402.39; also elsewhere on the board
SPIB_STEn|GPIO27: J402.41; also elsewhere on the board
SPIC_CLK|GPIO102: J402.36; also elsewhere on the board
SPIC_MISO|GPIO101: J402.34; also elsewhere on the board
SPIC_MOSI|GPIO100: J402.33; also elsewhere on the board
SPIC_STEn|GPIO103: J402.35; also elsewhere on the board
SPID_CLK|GPIO93: J401.5; also elsewhere on the board
SPID_MISO|GPIO92: J401.3; also elsewhere on the board
SPID_MOSI|GPIO91: J401.4; also elsewhere on the board
SPID_STEn|GPIO94: J401.2; also elsewhere on the board
SSIA_CLK|GPIO56: J403.124; also elsewhere on the board
SSIA_FSS|GPIO57: J403.123; also elsewhere on the board
SSIA_RX|GPIO55: J403.125; also elsewhere on the board
SSIA_TX|GPIO54: J403.126; also elsewhere on the board
UARTA_RX|GPIO43: J403.52; also elsewhere on the board
UARTA_TX|GPIO42: J403.51; also elsewhere on the board
nErr_AND_output: J402.16; also elsewhere on the board

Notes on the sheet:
Top J402 Connector
Supply and SPI for extension board
Top J403 Connector
Supply for shield boards

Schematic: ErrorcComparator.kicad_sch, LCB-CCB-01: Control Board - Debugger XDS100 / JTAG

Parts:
C801, C804, C807, C810: 100p; C_0603; mouser# 810-C1608C0G1H101KAA
C802, C805, C808, C811: 10n; C_0603; mouser# 810-CGA3E2X7R1H103K; not fitted
C813, C814, C815, C816, C817: 100n; C_0603; mouser# 810-C1608X5R1H104K
D801, D802, D803, D804: 150mA; SOD-323_Panjit; mouser# 241-BAS316_R1_00001
R801, R802, R803, R804, R809, R810, R811, R812: 1k0; R_0603; mouser# 71-CRCW06031K00FKEAC
R805, R806, R813, R814: 4k7; R_0603; mouser# 71-CRCW06034K70FKEBC
R807, R808, R815, R816: 10k; R_0603; mouser# 71-CRCW060310K0FKEAC
R820, R821, R822, R823: 0R0; R_0603; mouser# 71-CRCW06030000Z0EAC
U801, U802: 74HC74PW; TSSOP-14-Nexperia; mouser# 771-74HC74PW-T
U803, U804: TLV3202AIDGKR; VSSOP-8-TI; mouser# 595-TLV3202AIDGKR
U805: 74ALVC08PW; TSSOP-14-Nexperia; mouser# 771-ALVC08PW118

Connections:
+3.3V_HV: R801.2, R802.2, R809.2, R810.2, R820.1, R821.1, R822.2, R823.1; also elsewhere on the board
/Error Detection - Page 8/1Y: U805.3 (1Y), U805.10 (3B)
/Error Detection - Page 8/2Y: U805.6 (2Y), U805.9 (3A)
/Error Detection - Page 8/FF1_Data: R805.2, U801.4 (SD), U803.1
/Error Detection - Page 8/FF2_Data: R813.2, U801.10 (SD), U803.7
/Error Detection - Page 8/FF3_Data: R806.2, U802.4 (SD), U804.1
/Error Detection - Page 8/FF4_Data: R814.2, U802.10 (SD), U804.7
/Error Detection - Page 8/OPA1IN+: C802.1, D801.A, R801.1, R807.2, U803.3 (+)
/Error Detection - Page 8/OPA1IN-: C801.1, R803.2, U803.2 (-)
/Error Detection - Page 8/OPA2IN+: C808.1, D803.A, R809.1, R815.2, U803.5 (+)
/Error Detection - Page 8/OPA2_IN-: C807.1, R811.2, U803.6 (-)
/Error Detection - Page 8/OPA3IN+: C805.1, D802.A, R802.1, R808.2, U804.3 (+)
/Error Detection - Page 8/OPA3IN-: C804.1, R804.2, U804.2 (-)
/Error Detection - Page 8/OPA4IN+: C811.1, D804.A, R810.1, R816.2, U804.5 (+)
/Error Detection - Page 8/OPA4IN-: C810.1, R812.2, U804.6 (-)
ADC_A2_P: R803.1; also elsewhere on the board
ADC_B2_P: R804.1; also elsewhere on the board
ADC_C4_P: R811.1; also elsewhere on the board
ADC_D0_P: R812.1; also elsewhere on the board
GND_HV: C801.2, C802.2, C804.2, C805.2, C807.2, C808.2, C810.2, C811.2, C813.2, C814.2, C815.2, C816.2, C817.2, R807.1, R808.1, R815.1, R816.1, U801.2 (D), U801.3 (CP), U801.7 (GND), U801.11 (CP), U801.12 (D), U802.2 (D), U802.3 (CP), U802.7 (GND), U802.11 (CP), U802.12 (D), U803.4 (GND), U804.4 (GND), U805.7 (GND), U805.12 (4A), U805.13 (4B); also elsewhere on the board
GPIO10_RstFF1: U801.1 (RD); also elsewhere on the board
GPIO11_RstFF4: U802.13 (RD); also elsewhere on the board
GPIO14_nErr4: U802.8 (~Q), U805.4 (2A); also elsewhere on the board
GPIO15_Err1: U801.5 (Q); also elsewhere on the board
GPIO20_nErr1: U801.6 (~Q), U805.1 (1A); also elsewhere on the board
GPIO21_nErr2: U801.8 (~Q), U805.2 (1B); also elsewhere on the board
GPIO95_Err2: U801.9 (Q); also elsewhere on the board
GPIO96_Err4: U802.9 (Q); also elsewhere on the board
GPIO97_RstFF2: U801.13 (RD); also elsewhere on the board
GPIO98_RstFF3: U802.1 (RD); also elsewhere on the board
GPIO99_Err3: U802.5 (Q); also elsewhere on the board
GPIO104_nErr3: U802.6 (~Q), U805.5 (2B); also elsewhere on the board
unnamed: D801.C, R805.1
unnamed: D802.C, R806.1
unnamed: D803.C, R813.1
unnamed: D804.C, R814.1
unnamed: C813.1, C815.1, R820.2, U801.14 (VCC), U802.14 (VCC)
unnamed: C814.1, R821.2, U803.8 (VCC)
unnamed: C816.1, R823.2, U804.8 (VCC)
unnamed: C817.1, R822.1, U805.14 (VCC)
nErr_AND_output: U805.8 (3Y); also elsewhere on the board

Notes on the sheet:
Error1 - A2
Error3 - B2
Power Supply
Error AND Gate
Error2 - C4
Error4 - D0

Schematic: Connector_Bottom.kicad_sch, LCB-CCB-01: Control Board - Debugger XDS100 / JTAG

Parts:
J501, J502: ERM5-075-05.0-L-DV-K-TR; ERM5-075-05.0-L-DV; mouser# 200-ERM5075050LDVKTR

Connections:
+3V3_Connector_HV: J501.1, J501.2, J501.3, J501.4, J501.5, J501.6, J501.7, J501.8, J501.9, J501.10; also elsewhere on the board
ADC_A0_P: J501.118; also elsewhere on the board
ADC_A1_N: J501.116; also elsewhere on the board
ADC_A2_P: J501.123; also elsewhere on the board
ADC_A3_N: J501.121; also elsewhere on the board
ADC_A4_P: J501.124; also elsewhere on the board
ADC_A5_N: J501.122; also elsewhere on the board
ADC_B0_P: J501.129; also elsewhere on the board
ADC_B1_N: J501.127; also elsewhere on the board
ADC_B2_P: J501.130; also elsewhere on the board
ADC_B3_N: J501.128; also elsewhere on the board
ADC_B4_P: J501.135; also elsewhere on the board
ADC_B5_N: J501.133; also elsewhere on the board
ADC_C2_P: J501.136; also elsewhere on the board
ADC_C3_N: J501.134; also elsewhere on the board
ADC_C4_P: J501.141; also elsewhere on the board
ADC_C5_N: J501.139; also elsewhere on the board
ADC_D0_P: J501.142; also elsewhere on the board
ADC_D1_N: J501.140; also elsewhere on the board
ADC_D2_P: J501.147; also elsewhere on the board
ADC_D3_N: J501.145; also elsewhere on the board
ADC_D4_P: J501.148; also elsewhere on the board
ADC_D5_N: J501.146; also elsewhere on the board
ADC_IN14_P: J501.117; also elsewhere on the board
ADC_IN15_N: J501.115; also elsewhere on the board
CANA_RX|GPIO36: J502.141; also elsewhere on the board
CANA_TX|GPIO37: J502.142; also elsewhere on the board
CANB_RX|GPIO39: J502.137; also elsewhere on the board
CANB_TX|GPIO38: J502.138; also elsewhere on the board
CM-I2CA_SCL|GPIO32: J502.144; also elsewhere on the board
CM-I2CA_SDA|GPIO31: J502.143; also elsewhere on the board
ENET_CLK_25MHz: J501.91; also elsewhere on the board
ENET_MDIO_CLK|GPIO105: J501.61; also elsewhere on the board
ENET_MDIO_DATA|GPIO106: J501.67; also elsewhere on the board
ENET_MII_COL|GPIO110: J501.69; also elsewhere on the board
ENET_MII_CRS|GPIO109: J501.73; also elsewhere on the board
ENET_MII_INTR|GPIO108: J501.63; also elsewhere on the board
ENET_MII_RX_CLK|GPIO111: J501.75; also elsewhere on the board
ENET_MII_RX_DV|GPIO112: J501.70; also elsewhere on the board
ENET_MII_RX_Data0|GPIO114: J501.76; also elsewhere on the board
ENET_MII_RX_Data1|GPIO115: J501.87; also elsewhere on the board
ENET_MII_RX_Data2|GPIO116: J501.92; also elsewhere on the board
ENET_MII_RX_Data3|GPIO117: J501.88; also elsewhere on the board
ENET_MII_RX_ERR|GPIO113: J501.79; also elsewhere on the board
ENET_MII_TX_CLK|GPIO120: J501.86; also elsewhere on the board
ENET_MII_TX_Data0|GPIO121: J501.90; also elsewhere on the board
ENET_MII_TX_Data1|GPIO122: J501.80; also elsewhere on the board
ENET_MII_TX_Data2|GPIO123: J501.85; also elsewhere on the board
ENET_MII_TX_Data3|GPIO124: J501.89; also elsewhere on the board
ENET_MII_TX_EN|GPIO118: J501.81; also elsewhere on the board
ENET_MII_TX_ERR|GPIO119: J501.82; also elsewhere on the board
ENET_PPS1|GPIO48: J501.74; also elsewhere on the board
ENET_PPSO|GPIO47: J501.64; also elsewhere on the board
ENET_REVMII_MDIO_RST|GPIO107: J501.68; also elsewhere on the board
ENET_RMII_CLK|GPIO73: J501.62; also elsewhere on the board
EPWM1A|GPIO145: J502.3; also elsewhere on the board
EPWM1B|GPIO146: J502.4; also elsewhere on the board
EPWM2A|GPIO147: J502.5; also elsewhere on the board
EPWM2B|GPIO148: J502.6; also elsewhere on the board
EPWM3A|GPIO149: J502.9; also elsewhere on the board
EPWM3B|GPIO150: J502.10; also elsewhere on the board
EPWM4A|GPIO151: J502.11; also elsewhere on the board
EPWM4B|GPIO152: J502.12; also elsewhere on the board
EPWM5A|GPIO8: J502.15; also elsewhere on the board
EPWM5B|GPIO9: J502.16; also elsewhere on the board
EPWM6A|GPIO155: J502.17; also elsewhere on the board
EPWM6B|GPIO156: J502.18; also elsewhere on the board
EPWM7A|GPIO157: J502.21; also elsewhere on the board
EPWM7B|GPIO158: J502.22; also elsewhere on the board
EPWM8A|GPIO159: J502.23; also elsewhere on the board
EPWM8B|GPIO160: J502.24; also elsewhere on the board
EPWM9A|GPIO161: J502.27; also elsewhere on the board
EPWM9B|GPIO162: J502.28; also elsewhere on the board
EPWM10A|GPIO163: J502.29; also elsewhere on the board
EPWM10B|GPIO164: J502.30; also elsewhere on the board
EPWM11A|GPIO165: J502.33; also elsewhere on the board
EPWM11B|GPIO166: J502.34; also elsewhere on the board
EPWM12A|GPIO167: J502.35; also elsewhere on the board
EPWM12B|GPIO168: J502.36; also elsewhere on the board
EPWM13A|GPIO137: J502.39; also elsewhere on the board
EPWM13B|GPIO138: J502.40; also elsewhere on the board
EPWM14A|GPIO139: J502.41; also elsewhere on the board
EPWM14B|GPIO140: J502.42; also elsewhere on the board
EPWM15A|GPIO141: J502.45; also elsewhere on the board
EPWM15B|GPIO142: J502.46; also elsewhere on the board
EPWM16A|GPIO143: J502.47; also elsewhere on the board
EPWM16B|GPIO144: J502.48; also elsewhere on the board
ESC_I2C_SCL|GPIO30: J502.106; also elsewhere on the board
ESC_I2C_SDA|GPIO29: J502.108; also elsewhere on the board
ESC_LATCH0|GPIO125: J502.107; also elsewhere on the board
ESC_LATCH1|GPIO126: J502.111; also elsewhere on the board
ESC_LED_ERR|GPIO60: J502.95; also elsewhere on the board
ESC_LED_LINK0_ACTIVE|GPIO58: J502.100; also elsewhere on the board
ESC_LED_LINK1_ACTIVE|GPIO59: J502.96; also elsewhere on the board
ESC_LED_RUN|GPIO61: J502.90; also elsewhere on the board
ESC_LED_STATE_RUN|GPIO62: J502.83; also elsewhere on the board
ESC_MDIO_CLK|GPIO46: J502.58; also elsewhere on the board
ESC_MDIO_DATA|GPIO153: J502.70; also elsewhere on the board
ESC_PHY0_LINKSTATUS|GPIO86: J502.69; also elsewhere on the board
ESC_PHY1_LINKSTATUS|GPIO68: J502.82; also elsewhere on the board
ESC_PHY_CLK|GPIO154: J502.65; also elsewhere on the board
ESC_PHY_RESETn|GPIO76: J502.84; also elsewhere on the board
ESC_RX0_CLK|GPIO77: J502.72; also elsewhere on the board
ESC_RX0_DATA0|GPIO80: J502.63; also elsewhere on the board
ESC_RX0_DATA1|GPIO81: J502.64; also elsewhere on the board
ESC_RX0_DATA2|GPIO82: J502.59; also elsewhere on the board
ESC_RX0_DATA3|GPIO83: J502.66; also elsewhere on the board
ESC_RX0_DV|GPIO78: J502.81; also elsewhere on the board
ESC_RX0_ERR|GPIO79: J502.88; also elsewhere on the board
ESC_RX1_CLK|GPIO69: J502.76; also elsewhere on the board
ESC_RX1_DATA0|GPIO63: J502.87; also elsewhere on the board
ESC_RX1_DATA1|GPIO64: J502.93; also elsewhere on the board
ESC_RX1_DATA2|GPIO65: J502.94; also elsewhere on the board
ESC_RX1_DATA3|GPIO66: J502.89; also elsewhere on the board
ESC_RX1_DV|GPIO136: J502.99; also elsewhere on the board
ESC_RX1_ERR|GPIO71: J502.75; also elsewhere on the board
ESC_SYNC0|GPIO127: J502.112; also elsewhere on the board
ESC_SYNC1|GPIO128: J502.113; also elsewhere on the board
ESC_TX0_CLK|GPIO85: J502.78; also elsewhere on the board
ESC_TX0_DATA0|GPIO87: J502.71; also elsewhere on the board
ESC_TX0_DATA1|GPIO88: J502.54; also elsewhere on the board
ESC_TX0_DATA2|GPIO89: J502.53; also elsewhere on the board
ESC_TX0_DATA3|GPIO90: J502.57; also elsewhere on the board
ESC_TX0_ENA|GPIO84: J502.60; also elsewhere on the board
ESC_TX1_CLK|GPIO130: J502.117; also elsewhere on the board
ESC_TX1_DATA0|GPIO131: J502.105; also elsewhere on the board
ESC_TX1_DATA1|GPIO132: J502.101; also elsewhere on the board
ESC_TX1_DATA2|GPIO134: J502.102; also elsewhere on the board
ESC_TX1_DATA3|GPIO72: J502.77; also elsewhere on the board
ESC_TX1_ENA|GPIO129: J502.114; also elsewhere on the board
FreePin1: J501.15; also elsewhere on the board
FreePin3: J501.95; also elsewhere on the board
FreePin4: J501.96; also elsewhere on the board
FreePin5: J501.97; also elsewhere on the board
FreePin6: J501.98; also elsewhere on the board
FreePin7: J501.101; also elsewhere on the board
FreePin8: J501.102; also elsewhere on the board
GND_HV: J501.11, J501.12, J501.13, J501.14, J501.19, J501.20, J501.25, J501.26, J501.31, J501.32, J501.37, J501.38, J501.43, J501.44, J501.53, J501.54, J501.59, J501.60, J501.65, J501.66, J501.71, J501.72, J501.77, J501.78, J501.83, J501.84, J501.93, J501.94, J501.99, J501.100, J501.103, J501.104, J501.105, J501.106, J501.113, J501.114, J501.119, J501.120, J501.125, J501.126, J501.131, J501.132, J501.137, J501.138, J501.143, J501.144, J501.149, J501.150, J502.1, J502.2, J502.7, J502.8, J502.13, J502.14, J502.19, J502.20, J502.25, J502.26, J502.31, J502.32, J502.37, J502.38, J502.43, J502.44, J502.49, J502.50, J502.55, J502.56, J502.61, J502.62, J502.67, J502.68, J502.73, J502.74, J502.79, J502.80, J502.85, J502.86, J502.91, J502.92, J502.97, J502.98, J502.103, J502.104, J502.109, J502.110, J502.115, J502.116, J502.121, J502.122, J502.127, J502.128, J502.133, J502.134, J502.139, J502.140, J502.145, J502.146, J502.149, J502.150; also elsewhere on the board
GPIO14_nErr4: J501.55; also elsewhere on the board
GPIO15_Err1: J501.48; also elsewhere on the board
GPIO20_nErr1: J501.47; also elsewhere on the board
GPIO21_nErr2: J501.49; also elsewhere on the board
GPIO33: J501.57; also elsewhere on the board
GPIO34: J501.58; also elsewhere on the board
GPIO40: J502.132; also elsewhere on the board
GPIO41: J502.120; also elsewhere on the board
GPIO44: J502.119; also elsewhere on the board
GPIO45: J502.118; also elsewhere on the board
GPIO49: J502.135; also elsewhere on the board
GPIO50: J502.136; also elsewhere on the board
GPIO51: J502.131; also elsewhere on the board
GPIO52: J502.129; also elsewhere on the board
GPIO53: J502.130; also elsewhere on the board
GPIO95_Err2: J501.50; also elsewhere on the board
GPIO96_Err4: J501.56; also elsewhere on the board
GPIO99_Err3: J501.52; also elsewhere on the board
GPIO104_nErr3: J501.51; also elsewhere on the board
I2CA_SCL|GPIO1: J501.21; also elsewhere on the board
I2CA_SDA|GPIO0: J501.22; also elsewhere on the board
MCAN_RX|GPIO70: J501.17; also elsewhere on the board
MCAN_TX|GPIO4: J501.18; also elsewhere on the board
P0_CLK_25MHz: J502.148; also elsewhere on the board
P1_CLK_25MHz: J502.147; also elsewhere on the board
SCIB_RX|GPIO23: J501.46; also elsewhere on the board
SCIB_TX|GPIO22: J501.45; also elsewhere on the board
SCIC_RX|GPIO13: J501.24; also elsewhere on the board
SCIC_TX|GPIO12: J501.23; also elsewhere on the board
SPIA_CLK|GPIO18: J501.30; also elsewhere on the board
SPIA_MISO|GPIO17: J501.28; also elsewhere on the board
SPIA_MOSI|GPIO16: J501.27; also elsewhere on the board
SPIA_STEn|GPIO19: J501.29; also elsewhere on the board
SPIB_CLK|GPIO26: J501.42; also elsewhere on the board
SPIB_MISO|GPIO25: J501.40; also elsewhere on the board
SPIB_MOSI|GPIO24: J501.39; also elsewhere on the board
SPIB_STEn|GPIO27: J501.41; also elsewhere on the board
SPIC_CLK|GPIO102: J501.36; also elsewhere on the board
SPIC_MISO|GPIO101: J501.34; also elsewhere on the board
SPIC_MOSI|GPIO100: J501.33; also elsewhere on the board
SPIC_STEn|GPIO103: J501.35; also elsewhere on the board
SSIA_CLK|GPIO56: J502.124; also elsewhere on the board
SSIA_FSS|GPIO57: J502.123; also elsewhere on the board
SSIA_RX|GPIO55: J502.125; also elsewhere on the board
SSIA_TX|GPIO54: J502.126; also elsewhere on the board
UARTA_RX|GPIO43: J502.52; also elsewhere on the board
UARTA_TX|GPIO42: J502.51; also elsewhere on the board
nErr_AND_output: J501.16; also elsewhere on the board

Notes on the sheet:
Bottom J502 Connector
Bottom J501 Connector

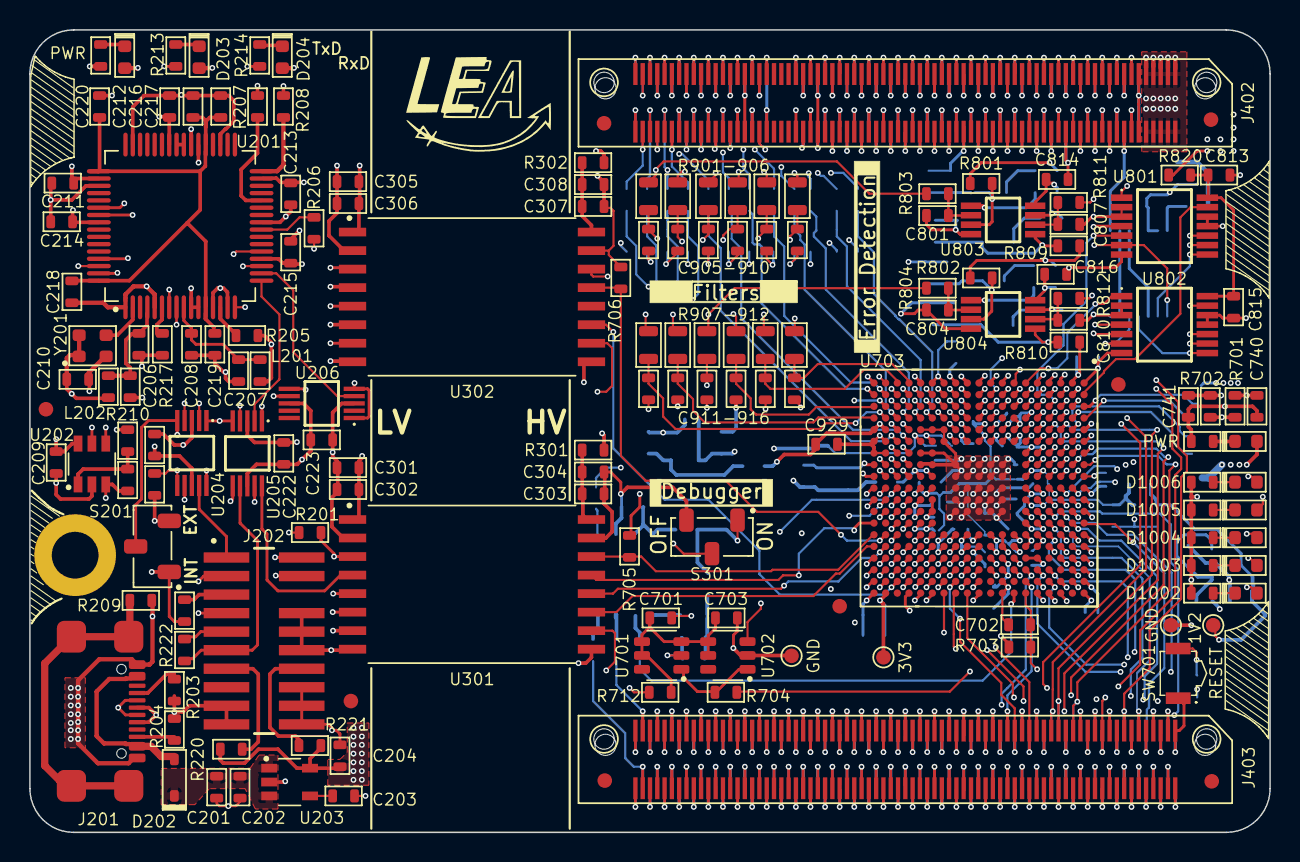
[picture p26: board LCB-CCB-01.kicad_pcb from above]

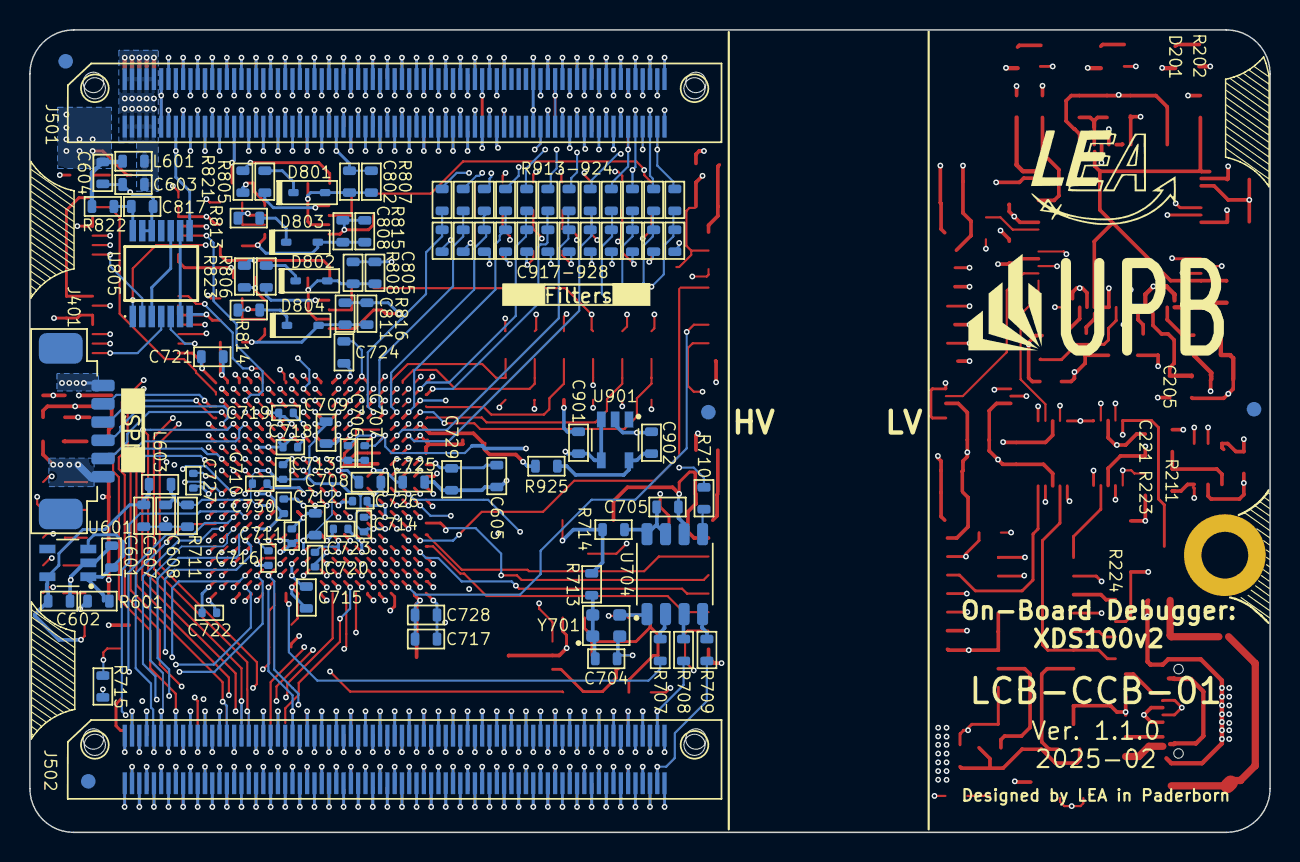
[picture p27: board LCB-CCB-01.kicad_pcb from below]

Board: 8 copper layers, 85.0 x 55.0 mm, 266 parts (105 on the bottom side), 330 nets.

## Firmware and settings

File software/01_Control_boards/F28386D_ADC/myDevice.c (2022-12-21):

//=================================================================================================
/// @file       myDevice.c
///
/// @brief      Datei enthält Funktionen um den Mikrocontorller TMS320F2838x grundlegend zu
///							initialisieren. Dazu wird der Watchdog-Timer ausgeschaltet, der Systemtakt
///							eingestellt, der Flash-Speicher initialisiert und die Interrupts freigeschaltet
///							und initialisiert.
///
/// @version    V1.1
///
/// @date       05.09.2022
///
/// @author     Daniel Urbaneck
//=================================================================================================
//-------------------------------------------------------------------------------------------------
// Includes
//-------------------------------------------------------------------------------------------------
#include "myDevice.h"


//-------------------------------------------------------------------------------------------------
// Global variables
//-------------------------------------------------------------------------------------------------


//-------------------------------------------------------------------------------------------------
// Global functions
//-------------------------------------------------------------------------------------------------
//=== Function: DeviceInit ========================================================================
///
/// @brief  Funktion ruft abhänging von der ausführenden CPU die entsprechende
///					Initialisierungsfunktion auf
///
/// @param  uint32_t clockSource
///
/// @return void
///
//=================================================================================================
void DeviceInit(uint32_t clockSource)
{
#ifdef CPU1
		// Übergabeparameter für die Taktquelle prüfen
		if (   (clockSource == DEVICE_CLKSRC_INTOSC2)
				|| (clockSource == DEVICE_CLKSRC_EXTOSC_SE_25MHZ))
		{
				DeviceInitCPU1(clockSource);
		}
		// Falls kein gültiger Parameter übergeben wurde den
		// internen 10 MHZ-Oszillator verwenden
		else
		{
				DeviceInitCPU1(DEVICE_CLKSRC_INTOSC2);
		}
#else
		DeviceInitCPU2();
#endif
}


//=== Function: DeviceInitCPU1 ====================================================================
///
/// @brief  Funktion führt (durch CPU1) eine Grundinitialisation des Mikrocontrollers durch:
///					- Watchdog-Timer ausschalten
///					- Speicherinhalte zeitkritischer Funktionen von FLASH in dern RAM kopieren
///					- Flash-Speicher für 200 MHz initialisieren
///					- Systemtakt einstellen (interner 10 MHz-Oszillator oder externer (single-ended)
///																	 25 MHz Oszillator, 200 MHz Systemtakt, 50 MHz Low Speed CLK)
///					- Fabrikationsdaten aus dem OTP-Speicher in die ADC-Trimmregister kopieren
///					- CPU-Interrupts aus-, PIE-Vectrotabelle ein- und Interrupts global einschalten
///
/// @param  uint32_t clockSource
///
/// @return void
///
//=================================================================================================
void DeviceInitCPU1(uint32_t clockSource)
{
#ifdef CPU1
    // Watchdog-Timer ausschalten
    WdRegs.WDCR.bit.WDDIS = 1;

    // Flash-Speicher initialisieren:
    // Funktion zur Initialisierung des Flash-Speichers zur RAM-Sektion zuordnen
    // (wird über die .cmd-Datei durch den Linker entsprechen in den RAM kopiert)
    #pragma CODE_SECTION(DeviceInitFlashMemory, ".TI.ramfunc");
    // Zeitkritische Funktion in den RAM kopieren, wenn der Flash genutzt wird.
    // Wird das nicht gemacht, funktioniert der Code nicht weil z.B. die Funktion
    // DELAY_US() angehalten wird und das Programm dann nicht weiterläuft. Die
    // Namen der Variablen sind Platzhalter für Konstanten des Linkers und dürfen
		// daher nicht verändert werden.
    extern Uint16 RamfuncsRunStart, RamfuncsLoadStart, RamfuncsLoadSize;
#ifdef _FLASH
    // Flash-Initialisierungsfunktion in den RAM-Speicher kopieren
		memcpy(&RamfuncsRunStart, &RamfuncsLoadStart, (size_t)&RamfuncsLoadSize);
		// Flash initialisieren. Muss vom RAM aus aufgerufen werden
		DeviceInitFlashMemory();
#endif

    // Register-Schreibschutz aufheben
    EALLOW;
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

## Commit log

2022-03-15 Upload project structure and control board LCB-CCB-01
    [AnalogFilter.kicad_sch, CAS-120TA.step, CAS-D20TA.step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]
2022-03-15 Add schematic from Hardware Monitor Extended
    [DAC.kicad_sch, Hardware_Monitor_Extended.kicad_pcb, Hardware_Monitor_Extended.kicad_sch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]
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2022-03-17 Add LCB-CHW-001 and LCB-CHW-002
    [DAC.kicad_sch, Hardware_Monitor.kicad_pcb, Hardware_Monitor.kicad_sch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]
2022-03-17 modify LCB-CCB-01 AGND, QR-Code
    [Control_Board.kicad_pcb, Control_Board.kicad_sch]
2022-03-17 Add Ref to some components, D. U. changes
    [Control_Board.kicad_pcb]
2022-03-17 Silkscreen back D. U. changes
    [Control_Board.kicad_pcb]
2022-03-17 finish RC change ref
    [AnalogFilter.kicad_sch, Control_Board.kicad_pcb, Control_Board.kicad_sch]
2022-03-17 Update Schematic and Datasheet
    [AnalogFilter.kicad_sch, Connector_Bottom.kicad_sch, Connector_Top.kicad_sch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]
2022-03-18 USB 90 Ohm correction
    [Control_Board.kicad_pcb]
2022-03-29 Schematic: analog filter values change, remove designator IC. PCB: replace LXXX footprint to 0805, add fiducials top and bottom. Update documentation
    [AnalogFilter.kicad_sch, Control_Board.kicad_pcb, Control_Board.kicad_sch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]
2022-03-29 remove designator IC and update documentation
    [DAC.kicad_sch, Hardware_Monitor.kicad_pcb, Hardware_Monitor.kicad_sch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]
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2022-04-28 change error comparator to soic-16 footprint
    [AnalogFilter.kicad_sch, Connector_Bottom.kicad_sch, Connector_Top.kicad_sch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]
2022-05-17 update MAX978EEE+ to MAX978ESE+ schematic symbol
    [Control_Board.kicad_pcb, Control_Board.kicad_sch, ErrorcComparator.kicad_sch]
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2022-07-30 change SOIC-16 3D model color
    [Control_Board.kicad_pcb, SOIC-16.step, SOIC-16_3.9x9.9mm_P1.27mm.step]
2022-07-30 add symbols, footprints and 3D models for Dock-PCB
    [2MS1T1B1M2QES.stp, Potentiometer_PTV09A-4020F-B103.stp, SOIC-14_3.9x8.7mm_P1.27mm.step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]
2022-08-01 update links in bom
    [BOM_Mouser_Control_Board.csv]
2022-08-08 update ferrit bead in bom
    [BOM_Mouser_Control_Board.csv]
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2022-08-09 add dock: schematic, and basic pcb placement. no routing
    [BOM_Dock.ods, Connector_Control_Board.kicad_sch, Dock.kicad_pcb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]
2022-08-10 fix short in schematic
    [Pinheaders.kicad_sch]
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2022-08-12 Update Power-Symbols in Dock, Perform DRC
    [Connector_Control_Board.kicad_sch, Dock.kicad_pcb, Dock.kicad_sch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]
2022-08-15 add LEA Symbol and Footprint
    [Connector_Control_Board.kicad_sch, Dock.kicad_pcb, Dock.kicad_sch]
2022-08-15 fix flipflop footprint: missing GND area for solder paste
2022-08-15 Dock: 3V3 and GND solder mask reference markers, more space to edge of Pcb, reduced inner layers
    [BOM_Dock.ods, Dock.kicad_pcb, Dock.kicad_sch]
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2022-08-24 update REF-Pin resistor Debugger to 12k
    [BOM_Mouser_Control_Board.csv, Control_Board.kicad_sch, Debugger.kicad_sch]
2022-08-25 add missing label description connector left/right to pcb
2022-08-30 add improvements for dock
    [BOM_Dock.ods]
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2022-09-30 add rubber bumper pads to HWOM BOM
    [BOM_Mouser_Hardware_Monitor.csv]
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2022-11-16 update symbols and footprints
    [Con_BNC_PCB.stp, Con_DPT_Signal.stp, Con_SMA_PCB.stp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]
2022-11-18 update kicadlibrary and lcb with new mouser number components
    [AnalogFilter.kicad_sch, Connector_Bottom.kicad_sch, Connector_Top.kicad_sch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]
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2022-11-20 update hw-mon to new material-numbers
    [DAC.kicad_sch, Hardware_Monitor.csv, Hardware_Monitor.kicad_pcb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]
2022-11-20 update dock symols to new symbols library
    [Connector_Control_Board.kicad_sch, Dock.kicad_pcb, Dock.kicad_sch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]
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2022-11-21 update control board components with new library data
    [AnalogFilter.kicad_sch, Control_Board.kicad_pcb, Control_Board.kicad_sch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]
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2022-12-22 update schematics for accessories: usb-cable, hw-mon-cable, rubber-feet, jumper and jumper cable set. Fix wrong footprint of 0402 ferrite bead to 0603
    [Control_Board.kicad_pcb, Control_Board.kicad_sch, Dock.kicad_sch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]
2022-12-22 fix missing connection at ferrite bead
    [Control_Board.kicad_pcb]
2023-01-03 add hint for limited input for error comparators. Add to-do on improvement list.
    [ErrorcComparator.kicad_sch]
2023-01-09 Error comparator input singal filtering does not work as expected due to series filtering instead of parallel filtering. Add note and workaround for series filtering of input signal
2023-01-12 fix designator for automatic generated capacitors
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2023-01-17 add missing adapter cables BNC/SMB to HW-MON
    [Hardware_Monitor.kicad_sch]
2023-01-18 add second rubber feet set to dock board
    [Dock.kicad_sch]
2023-01-18 update rubber feet symbol
    [Hardware_Monitor.kicad_sch]
2023-01-18 update fiducials to small/medium/large
    [Dock.kicad_pcb, Dock.kicad_sch]
2023-02-01 add adapter board LCB-ADA-01
    [LCB-ADA-01.kicad_pcb, LCB-ADA-01.kicad_sch]
2023-02-07 fix ferrite beads on control board (again...)
    [Control_Board.kicad_pcb, Control_Board.kicad_sch, Power.kicad_sch]
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2023-03-21 update schematic pdf files
    [Dock.csv, Hardware_Monitor.csv, LCB-ADA-01.csv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]
2023-03-21 update file structure, rm unecessary files
    [BOM_Mouser_Control_Board.csv, BOM_Mouser_Hardware_Monitor.csv, DAC.kicad_sch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]
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2023-04-09 mv HW-MON + Dock to separate repositories
    [AnalogFilter.kicad_sch, Connector.kicad_sch, Connector_Bottom.kicad_sch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]
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2023-04-09 mv kicad library to separate repository
    [2MS1T1B1M2QES.stp, CAS-120TA.step, CAS-D20TA.step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]
2023-04-11 signal variable renaming, update some footprints
    [AnalogFilter.kicad_sch, Connector_Bottom.kicad_sch, Connector_Top.kicad_sch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]
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2023-04-26 update variable names for more readable
    [AnalogFilter.kicad_sch, Connector_Bottom.kicad_sch, Connector_Top.kicad_sch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]
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2023-08-07 fix typo PGIO149 -> GPIO149
    [Connector_Bottom.kicad_sch, Connector_Top.kicad_sch, LCB-CCB-01.kicad_pcb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]
2023-08-28 Update README.md
    minor typo corrections (in particular no hyphens in LEA Control Board)
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2024-12-11 update to new kicad version
    [AnalogFilter.kicad_sch, Connector_Bottom.kicad_sch, Connector_Top.kicad_sch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]
2024-12-12 fix schematic warnings
    [AnalogFilter.kicad_sch, Connector_Bottom.kicad_sch, Connector_Top.kicad_sch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]
2024-12-12 footprint update, update printed version labeling
    [AnalogFilter.kicad_sch, Connector_Bottom.kicad_sch, Connector_Top.kicad_sch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]
2024-12-19 issues fix
    [AnalogFilter.kicad_sch, ErrorcComparator.kicad_sch, LCB-CCB-01.kicad_pcb]
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2025-01-06 Added M3 hole, Reset switch and removed boot switch
    [Debugger.kicad_sch, LCB-CCB-01.kicad_pcb, MCU.kicad_sch]
2025-01-08 update: 0402 to 0603
    [AnalogFilter.kicad_sch, Debugger.kicad_sch, ErrorcComparator.kicad_sch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]
2025-01-09 update: 0402->0603, Error detection part
    [Connector_Bottom.kicad_sch, Debugger.kicad_sch, ErrorcComparator.kicad_sch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]
2025-01-10 Components updates according to BOM
    [Connector_Bottom.kicad_sch, Debugger.kicad_sch, ErrorcComparator.kicad_sch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]
2025-01-17 Error det. circuit update - new packages/comps and OR gate
    [ErrorcComparator.kicad_sch, LCB-CCB-01.kicad_pcb, LCB-CCB-01.kicad_sch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]
2025-01-20 error det. OR gates - packages update
    [ErrorcComparator.kicad_sch, LCB-CCB-01.kicad_pcb]
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2025-01-27 updates:err det cir, debugger
    [AnalogFilter.kicad_sch, Connector_Bottom.kicad_sch, Connector_Top.kicad_sch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]
2025-01-29 updated error detection sch. and layout
    [ErrorcComparator.kicad_sch, LCB-CCB-01.kicad_pcb]
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2025-02-09 Error detection-Diode update
    [AnalogFilter.kicad_sch, Connector_Bottom.kicad_sch, Connector_Top.kicad_sch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]
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2025-02-19 few LED rel. changes and error det. resistance change: 33k->2.9V : 4.7k->2.6V
    [Connector_Bottom.kicad_sch, Debugger.kicad_sch, ErrorcComparator.kicad_sch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]
2025-02-19 fiducials, small routing changes
    [AnalogFilter.kicad_sch, Connector_Bottom.kicad_sch, Debugger.kicad_sch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]
2025-02-20 error det. AND gate update
    [AnalogFilter.kicad_sch, Connector_Bottom.kicad_sch, Connector_Top.kicad_sch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]
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2025-04-11 mv usb c connector for better soldering on rework station and handling on placement machine
2025-05-27 mv some components close to the rework station holder, bump to 1.2.0
    [AnalogFilter.kicad_sch, Connector_Bottom.kicad_sch, Connector_Top.kicad_sch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]
